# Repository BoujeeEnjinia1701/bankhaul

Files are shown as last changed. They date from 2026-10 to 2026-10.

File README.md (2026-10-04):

# BankHaul

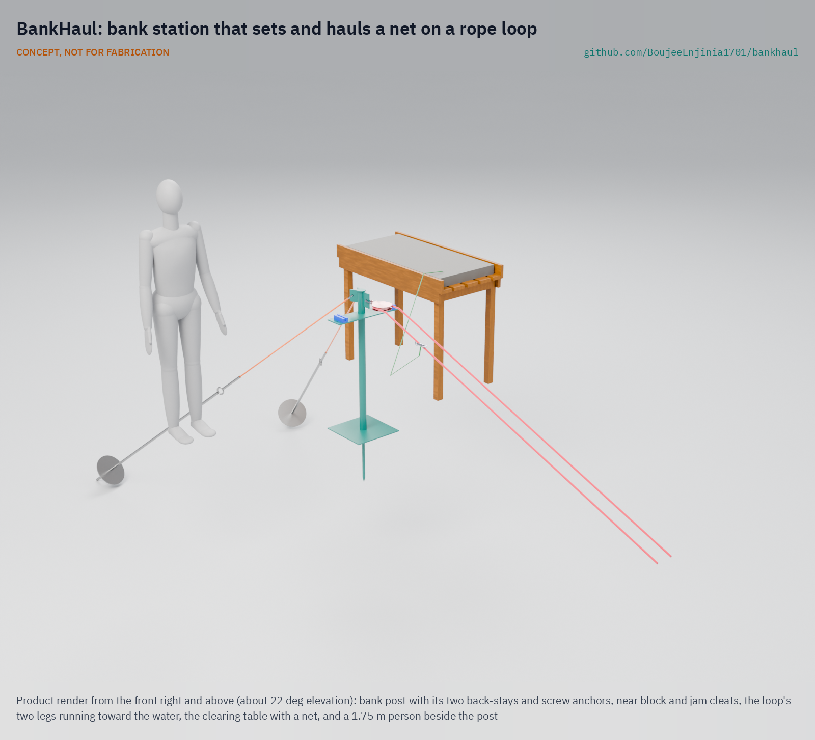
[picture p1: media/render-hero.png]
BankHaul: bank station that sets and hauls a net on a rope loop


     

**Area:** Food and water security · **TRL:** 3 of 9 (proof of concept on paper, design constructable) · **Value-engineering target:** USD 1,800 (estimated prototype cost USD 404) · **Difficulty:** 2 of 5

Sets and hauls nets from the bank on a rope loop so fishers stop wading into crocodile water.

> CONCEPT, NOT FOR FABRICATION. BankHaul is a TRL 3 design on paper: it has not been built or tested.

## Concept rationale

BankHaul is a running rope loop, the same idea as a washing line on two pulleys. One pulley sits on an anchor on the bank; the other sits offshore on a driven stake or on an anchored float. The net, or its end line, is clipped to the loop. Pulling one side of the loop from the bank carries the net out; pulling the other side brings it back to the bank for clearing. Once the stake or float is in place, nobody needs to step into the water to fish.

Everything is commodity hardware: rope, two pulleys, a ground anchor, a stake or a float and some clips. There is no motor and no winch. It is published as an open engineering reference so fisher groups, wildlife authorities and NGOs can build and adapt it to their own banks, nets and bed conditions.

## Burning platform

At Lake Kariba, researchers documented 106 crocodile attacks from 2000 to 2020; in a sample of 60 attacks, 58 % happened while the victim was fishing, and 49 % between midnight and 08:00 ([Matanzima et al., Oryx](https://www.cambridge.org/core/journals/oryx/article/negative-humancrocodile-interactions-in-kariba-zimbabwe-data-to-support-potential-mitigation-strategies/E7F0BCD3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)). In Tanzania, 575 crocodile attacks were recorded from 2010 to 2019 and 58 % were fatal ([Eustace et al., 2022](https://link.springer.com/article/10.1007/s10745-022-00355-z)). In Mozambique, crocodiles caused 66 % of the 265 wildlife-related deaths recorded over 27 months, and victims included people fishing with gill nets ([Dunham et al., Oryx, 2010](https://www.cambridge.org/core/journals/oryx/article/humanwildlife-conflict-in-mozambique-a-national-perspective-with-emphasis-on-wildlife-attacks-on-humans/434EEAAF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)).

The same pattern appears with saltwater crocodiles in Asia: in Timor-Leste, about 80 % of reported attacks happen while fishing or crabbing ([ABC News, 2025](https://www.abc.net.au/news/2025-01-09/crocodile-management-nt-lessons-for-timor-leste/104522096)), and Indonesia recorded 179 attacks with 92 deaths in 2024 ([ICSF, citing CrocAttack](https://icsf.net/newss/indonesias-crocodiles-are-back-and-fishermen-have-scars-to-prove-it/)). The Mozambique study notes that people take the risk because alternative foods or livelihoods are lacking ([Dunham et al., 2010](https://www.cambridge.org/core/journals/oryx/article/humanwildlife-conflict-in-mozambique-a-national-perspective-with-emphasis-on-wildlife-attacks-on-humans/434EEAAF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)). Telling fishers to stay out of the water is not enough; they need a way to keep fishing from the bank.

## Where it could be used

### By industry

| Industry | Use |
| --- | --- |
| Small-scale inland and estuarine fisheries | Setting and hauling gillnets and traps from the bank in crocodile water |
| Wildlife authorities and conservation | A human-wildlife conflict mitigation measure that protects people without removing crocodiles |
| Humanitarian and livelihood programmes | Low-cost kits for fishing households in conflict hotspots |
| Aquaculture and fish ponds | Moving nets, cages or feed lines across ponds without wading |
| Environmental monitoring | Placing and retrieving sampling gear or sensors from the bank |

### By country or region

| Country or region | Why it matters there |
| --- | --- |
| Zimbabwe and Zambia (Lake Kariba) | 58 % of 60 sampled crocodile attacks happened while fishing ([Oryx](https://www.cambridge.org/core/journals/oryx/article/negative-humancrocodile-interactions-in-kariba-zimbabwe-data-to-support-potential-mitigation-strategies/E7F0BCD3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)). |
| Tanzania | 575 crocodile attacks from 2010 to 2019, 58 % fatal ([Human Ecology, 2022](https://link.springer.com/article/10.1007/s10745-022-00355-z)). |
| Mozambique | Crocodiles caused 66 % of wildlife-related deaths, with over half near Lake Cabora Bassa and the Zambezi ([Oryx, 2010](https://www.cambridge.org/core/journals/oryx/article/humanwildlife-conflict-in-mozambique-a-national-perspective-with-emphasis-on-wildlife-attacks-on-humans/434EEAAF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)). |
| Timor-Leste | About 80 % of reported crocodile attacks happen while fishing or crabbing ([ABC News, 2025](https://www.abc.net.au/news/2025-01-09/crocodile-management-nt-lessons-for-timor-leste/104522096)). |
| Indonesia | 179 crocodile attacks and 92 deaths in 2024, more than any other country ([ICSF](https://icsf.net/newss/indonesias-crocodiles-are-back-and-fishermen-have-scars-to-prove-it/)). |

## What sparked the idea

The idea came from the Lake Kariba study by Matanzima, Marowa and Nhiwatiwa, which found that most attacks in its sample happened while people were fishing and recommended area-specific mitigation, patrols and closures of high-risk fishing zones ([Oryx](https://www.cambridge.org/core/journals/oryx/article/negative-humancrocodile-interactions-in-kariba-zimbabwe-data-to-support-potential-mitigation-strategies/E7F0BCD3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)). Closures protect people but also cut off food and income. The question behind BankHaul was simpler: if the net can travel out and back on a rope, does the fisher need to be in the water at all?

## Problem

Small-scale fishers in crocodile waters wade in to set and check their nets, and fishing is the activity during which most attacks happen. They need a way to set and haul nets without entering the water.

Full problem statement: [docs/01-problem.md](docs/01-problem.md)

## Concept

A running rope loop from a bank anchor out to a pulley on a stake or anchored float; fishers set and haul their nets by pulling the loop from the bank and never wade into crocodile water.

A steel post on the bank, held back by two rope stays to screw ground anchors, carries a swivel block at waist height. A steel stake driven into the bed carries a second block on a collar that turns and follows the water level. Two halves of 12 mm floating rope joined by two swivel rings make the loop; the net's far end clips to a ring through a weak link and is pulled out by the loop, then hauled back by hand onto a table at least 5 m from the water. The peak hand pull is about 200 N (BKH-CAL-001).

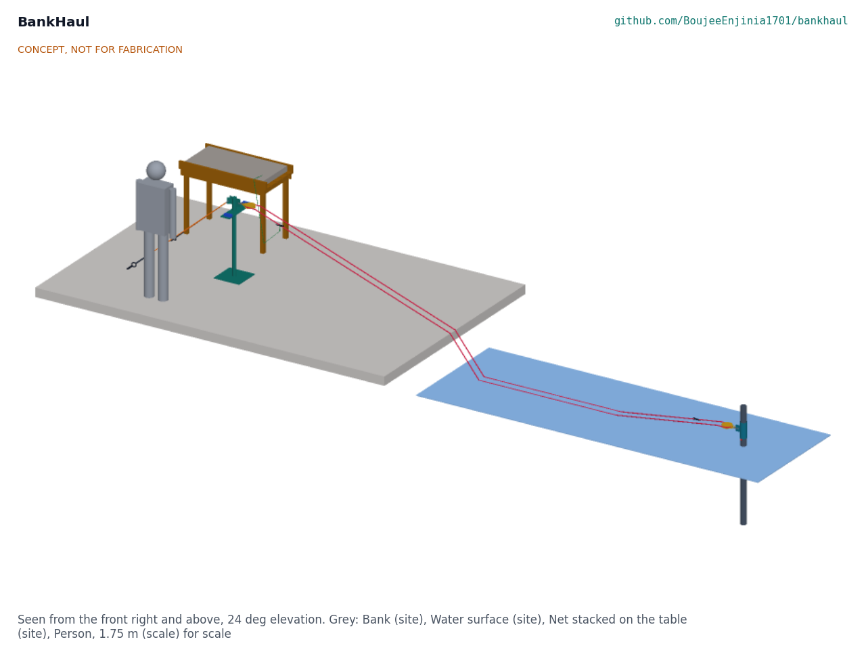
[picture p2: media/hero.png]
BankHaul concept, shortened layout


Full design precis: [docs/02-concept.md](docs/02-concept.md) · Requirements: [docs/03-requirements.md](docs/03-requirements.md) · Calculations: [docs/04-calcs/01-sizing.md](docs/04-calcs/01-sizing.md) · Prototype build plan: [docs/05-build-plan.md](docs/05-build-plan.md) · Design decisions: [docs/06-design-decisions.md](docs/06-design-decisions.md)

## Key components

- Bank post weldment with two back-stays, turnbuckles and screw ground anchors
- Near block and far block (bought swivel blocks)
- Far stake with a swivel collar and stop pin
- Rope loop of two halves joined by two swivel rings
- Net bridles with weak links and snap hooks
- Jam cleats on a cleat bar (the bank brake)
- Clearing table

## Building the prototype

The prototype is one station for a 30 m span, built from seven made and seven bought components. The post, stake and collar are cut, drilled and welded from steel tube and plate; the table is simple carpentry; the stays, loop and bridles are rope work. The bank station is set up on land; the far stake is driven from a boat or at low water, never by wading. The illustrated, step-by-step plan is in [docs/05-build-plan.md](docs/05-build-plan.md) (plan, not yet built).

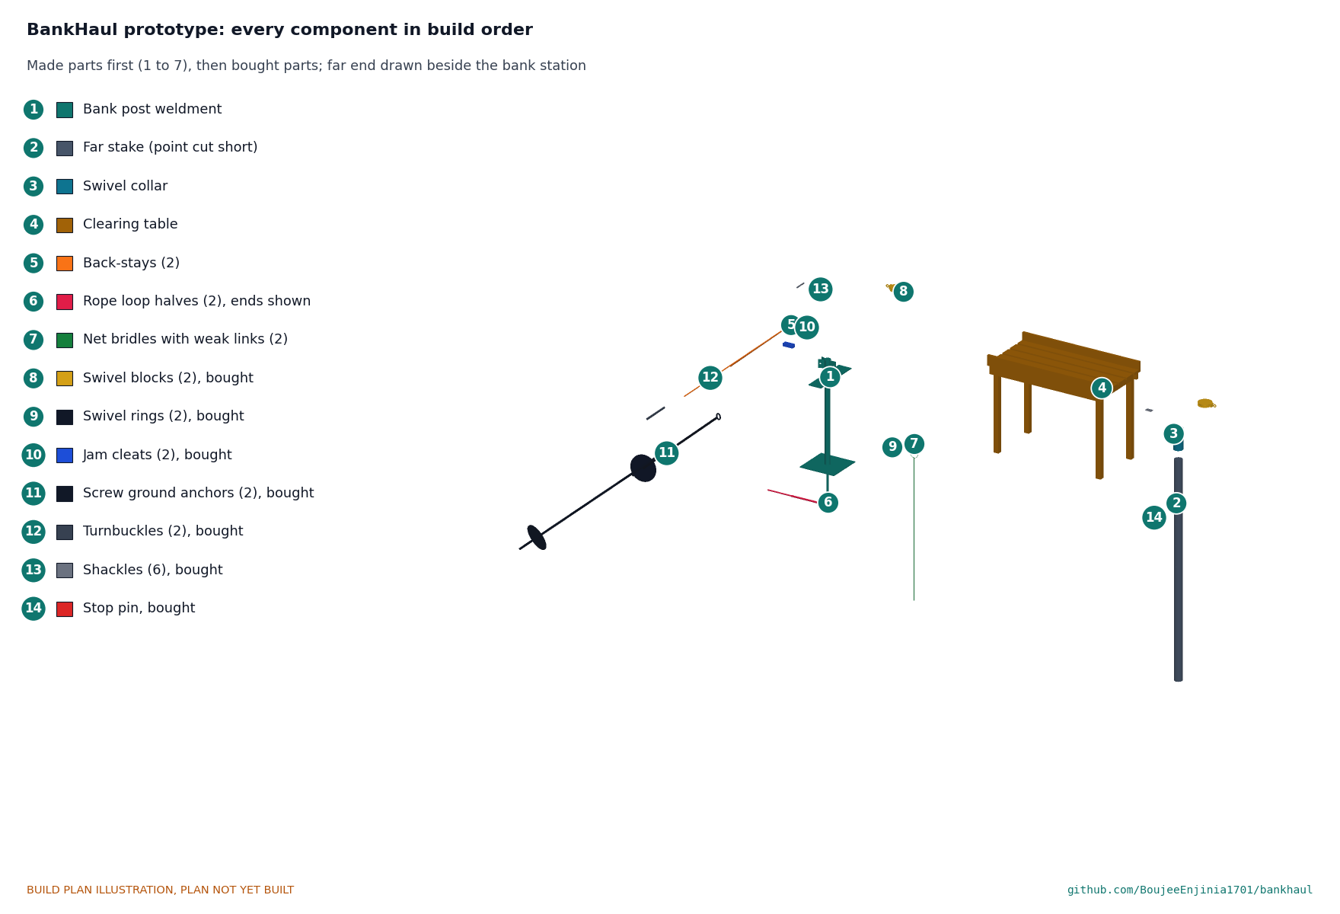
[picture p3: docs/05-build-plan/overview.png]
Every component, pulled apart and numbered in build order


## Safety

> Published as an open engineering reference, not certified equipment.
>
> BankHaul reduces time in the water; it does not protect anyone from a crocodile that leaves the water. Keep away from the water's edge at night where possible and follow local wildlife authority advice.
>
> Installing the offshore stake or float is the most dangerous step; do it from a boat or at low water, never by wading alone.
>
> Rope under load can snap back; never stand in the bight of the loop or in line with a loaded stay, and check anchors, stays, blocks and rope before each season.
>
> Each net end reaches the loop through a weak link that releases at 500 to 700 N; never replace it with stronger cord. Take the loop out of the water before a flood.
>
> Never tie the loop to your body.
>
> This design is published as an open engineering reference. It is not certified equipment.

## Repository layout

| Folder | Contents |
| --- | --- |
| `docs/` | Problem, concept, requirements, calculations and design decisions |
| `cad/src/` | build123d Python source, the source of truth for all geometry |
| `cad/step/`, `cad/stl/` | Exported models for FreeCAD, other CAD tools and printing |
| `cad/drawings/` | 2D sketches and dimensioned drawings |
| `bom/` | Bill of materials |
| `electronics/` | KiCad schematics and PCB layouts |
| `firmware/` | Microcontroller code |
| `media/` | Renders, perspectives and photos |
| `build-log/` | Dated prototyping notes |

## Documentation

Controlled documents follow the portfolio [documentation standard](.kit/STANDARDS.md). Each carries a document ID (BKH-PRC-001 for the precis), a version and a revision history. Branded PDFs are built with `python .kit/render.py` and attached to GitHub Releases when a document is tagged, for example `BKH-PRC-001/v1.0`.

## Credits

Designed by Amish Chadha at Design Molecule Labs. See [CONTRIBUTORS.md](CONTRIBUTORS.md) for roles. To cite this design, use [CITATION.cff](CITATION.cff) (GitHub shows it as "Cite this repository").

AI assistance (Claude) was used to accelerate prototype documentation and first-pass research. Design direction and all decisions are Amish Chadha's, recorded in this repository's decision records (`docs/decisions/`).

## Licenses

- **Hardware** (CAD, drawings, BOM, electronics): [CERN-OHL-S v2](LICENSE)
- **Software** (firmware, scripts, notebooks): [MIT](LICENSE-SOFTWARE)

A project of the [Design Molecule](https://designmolecule.com) lab.

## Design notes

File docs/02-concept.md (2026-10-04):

---
doc_id: BKH-PRC-001
title: BankHaul design precis
project: BankHaul
doc_type: Precis
version: "0.3"
status: Draft
date: '2026-10-03'
author: Amish Chadha
license: CERN-OHL-S-2.0
revisions:
- version: "0.1"
  date: '2026-09-30'
  author: Amish Chadha
  change: Initial scaffold
- version: "0.2"
  date: '2026-10-03'
  author: Amish Chadha
  change: TRL 2 and 3 update; constructable design (BKH-DDR-001, BKH-DDR-002), first-order numbers, safety
- version: "0.3"
  date: '2026-10-03'
  author: Amish Chadha
  change: Far stake driven 3.5 m and R8 restated (Amish's decisions 14A and 15A, BKH-DDR-003); numbers updated
---

# BankHaul design precis

Sets and hauls nets from the bank on a rope loop so fishers stop wading into crocodile water.

BankHaul concept, shortened layout

*Figure 1. Bank station, rope loop and far stake in the shortened picture layout (7 m between the blocks; 30 m in the design case).*

## How it works

A rope loop runs from a post on the bank out to a stake in the water and back. Once the stake is set, the fisher never needs to enter the water: the net is clipped to the loop on the bank, pulled out by the loop, and later hauled back onto a table on the bank.

- **Bank station.** A 48.3 mm steel post stands on a 350 mm foot plate with a ground spike, at least 6 m back from the water. Two rope back-stays with turnbuckles hold it back to two screw ground anchors with 250 mm helixes. A swivel block hangs from a pad eye at 950 mm, about waist height. A cleat bar carries two jam cleats, one for each leg of the loop, and a hole to tie off the net's near end.
- **Far end.** A 76.1 mm steel stake, 5.0 m long, is driven 3.5 m into the bed from a boat or at low water. A collar turns on the stake, resting on a through-bolt stop pin that can be moved up or down a hole as the season's water level changes; a second swivel block hangs from the collar, so it lines up with the loop by itself.
- **Loop.** Two halves of 12 mm floating rope are joined by two eye-to-eye swivels. The swivels are the clip rings: when ring 1 is at the bank, ring 2 is at the far block, and each ring stops at a block if pulled too far.
- **Setting.** The fisher clips the far end of the net to ring 1 through a weak link and pulls the other leg of the loop hand over hand; ring 1 carries the net's far end out while the net pays out from the table. When ring 1 reaches the far block, the net lies along the loop. The near end is tied to the cleat bar through a second weak link, and each leg is dropped into its jam cleat.
- **Hauling.** The fisher frees the legs, unties the near end and pulls the net in onto the table hand over hand; the loop follows, bringing ring 1 and the far end in last. The table is at least 5 m from the water.

## Components

| # | Component | Role | Made or bought |
| --- | --- | --- | --- |
| 1 | Bank post weldment | Carries the near block, the jam cleats and the stays | Made: welded steel tube and plate |
| 2 | Far stake | Carries the far end in the bed | Made: steel tube with a welded point and cap |
| 3 | Swivel collar | Turns on the stake so the far block lines up with the loop | Made: steel tube and lug |
| 4 | Clearing table | Raised surface to stack and clear the net above the waterline | Made: timber |
| 5 | Back-stays (2) | Hold the post back against the loop | Made: spliced polyester rope |
| 6 | Rope loop | Carries the net out and back | Made: two spliced halves of floating rope |
| 7 | Net bridles with weak links (2) | Join each net end to the loop or the post; release at 500 to 700 N | Made: cord, weak link and snap hook |
| 8 | Swivel blocks (2) | Turn the loop at each end | Bought: 100 mm sheave for 12 mm rope |
| 9 | Swivel rings (2) | Join the loop halves; clip rings and end stops | Bought |
| 10 | Jam cleats (2) | Hold each leg; the bank brake | Bought |
| 11 | Screw ground anchors (2) | Anchor the stays in soft soil | Bought: 250 mm helix, 1.6 m rod |
| 12 | Turnbuckles (2) | Tension the stays | Bought: rated M12 |
| 13 | Shackles (6) | Join blocks, stays and anchors | Bought: rated 10 mm |
| 14 | Stop pin | Holds the collar at the season's level | Bought: M12 bolt |

## Key design choices

Each choice is recorded in BKH-DDR-001 (TRL 2 review) or BKH-DDR-002 (design for construction) and listed in `docs/06-design-decisions.md`.

- **A stayed post, not a cantilever.** A post holding 3 kN at waist height as a cantilever would need a deep foundation; stays to screw anchors take the pull as tension and leave the post in compression, and two people can move it.
- **Rings that never pass a block.** The loop's joins are the clip rings, placed half a loop apart, so with a net shorter than the span less 2 m no ring or knot ever runs round a sheave.
- **Weak links.** Every net end reaches the loop or post through a link that releases at 500 to 700 N, about eight times the largest load in normal use, so a crocodile or snag taking the net cannot load the far stake past 1.4 kN or pull a person.
- **Floating loop.** Polysteel floats, so the loop stays visible, clear of the bed and easy to reach from a boat.
- **Hand pull only.** No winch or capstan (IP screen design-around); the peak pull of about 200 N does not need one.

## First-order numbers

All figures from BKH-CAL-001; assumptions are stated there.

| Quantity | Value | Basis |
| --- | --- | --- |
| Loop length, 30 m span | 60.4 m | Two legs plus half a wrap round each 112 mm rope circle |
| Peak hand pull to haul a 30 m net with 10 kg catch | about 200 N | Catch, weed and a fifth of the wet net up a 27 degree bank edge |
| Pull to set the net | about 43 N | Loop and net paying out at 0.5 m/s |
| Weak link release | 500 to 700 N | Nominal 600 N, plus or minus 15 % |
| Far end design load | 1.4 kN | Both legs at the link's highest release |
| Stay tension at the 3 kN bank load | 2.1 kN each | Stays 39 degrees up, 22 degrees either side |
| Screw anchor capacity | 4.4 kN each | 250 mm helix, 0.9 m deep, soil of 10 kPa shear strength |
| Far stake capacity | 6.1 kN in soft mud; 3.0 kN in very soft mud (factor 2.03 on R5) | Broms, short free-head pile, 3.5 m embedded |
| Cycle time | about 6 minutes | Without clearing fish |
| Station mass | about 106 kg; heaviest part 33.2 kg (far stake) | Model volumes and catalogue figures |
| Station parts | USD 394 (steel trial station; R8 now applies to a local-materials station costed with the co-design partner) | `bom/bom.csv` |

Value-engineering target: USD 1,800. Estimated cost of the constructable design: USD 404 including the stake driving cap (USD 1,396 under the target).

## Patent design-arounds

From the preliminary patent, trademark and prior-art screen (not legal advice):

- No powered hauler: hand-pulled loop only, which keeps clear of motorised line-hauler patents such as EP1429601 (expired) and later filings.
- Commodity blocks, anchors and rope, following the traditional running-line practice, rather than any proprietary downrigger or hauler pulley.

## Shared blocks

- CalRig proof-load: the first candidate rig for the anchor, stake and weak link tests at TRL 4.
- Hand capstan block from SaltDrag and SiltHaul: not used; the peak pull is within one person's reach, and the design-around excludes powered hauling.

## Safety

> **Safety:** BankHaul reduces time in the water; it does not protect anyone from a crocodile that leaves the water. Keep away from the water's edge, especially at night and at dawn, and follow the local wildlife authority's advice.
>
> Placing the far stake is the most dangerous step: do it from a boat or at low water with a second person watching, never by wading.
>
> A loaded rope can snap back. Never stand in the bight of the loop or in line with a loaded stay; check anchors, stays, blocks and rope before each season and after any hard pull.
>
> Never tie the loop or the net to your body, and never wrap the rope round a hand. If something big takes the net, let go: the weak link and the jam cleats hold the rest.
>
> Take the loop out of the water before a flood; floating debris can load it far beyond its design.
>
> This design is published as an open engineering reference. It is not certified equipment.

## Open questions

Open decisions and items to confirm when parts are bought are kept in the design decisions register (`docs/06-design-decisions.md`).

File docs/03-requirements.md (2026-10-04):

---
doc_id: BKH-REQ-001
title: BankHaul requirements
project: BankHaul
doc_type: Requirements
version: "0.3"
status: Draft
date: '2026-10-03'
author: Amish Chadha
license: CERN-OHL-S-2.0
revisions:
- version: "0.1"
  date: '2026-09-30'
  author: Amish Chadha
  change: Initial scaffold
- version: "0.2"
  date: '2026-10-03'
  author: Amish Chadha
  change: TRL 3; targets made measurable, R10 (weak link) and R11 (working distance) added, status from BKH-CAL-001
- version: "0.3"
  date: '2026-10-03'
  author: Amish Chadha
  change: Amish's decisions 14A (far stake driven 3.5 m; R5 status) and 15A (R8 restated), BKH-DDR-003
---

# BankHaul requirements

Measurable requirements for the first prototype station. Each status comes from the calculation note BKH-CAL-001 (`docs/04-calcs/01-sizing.md`); "on paper" means calculated, not yet tested. R10 and R11 were added at the TRL 2 review (BKH-DDR-001, items 3 and 4). R8 was restated, and R5's status changed, by Amish's decisions of 2026-10-03 (BKH-DDR-003). Amish, 2026-10-03: "i agree with all the 46 recommendations you provided. please proceed."

Table 1. Requirements

| ID | Requirement | Target | Verification (TRL 4 or later) | Status at TRL 3 |
| --- | --- | --- | --- | --- |
| R1 | Set and haul a gillnet with nobody entering the water | 10 of 10 set and haul cycles completed from the bank | Field trial with partner fishers | Met on paper: once the far stake is set from a boat, no step needs anyone in the water |
| R2 | Working span | At least 30 m (98 ft) between pulleys; stretch goal 50 m (164 ft) | Measured at the trial site | Met on paper: 30 m design case; rope bought for 50 m |
| R3 | Hand pull force | Peak pull under 250 N (56 lbf) to haul a 30 m net with catch | Spring scale or load cell during trials | Met on paper: about 200 N (estimate) |
| R4 | Bank anchor holding | Holds at least 3 kN (675 lbf) in soft wet soil without visible movement | Pull-out test on a CalRig-style rig | Met on paper: screw anchors at factor 2.1 on capacity in soil of 10 kPa shear strength |
| R5 | Offshore stake or float holding | Holds at least 1.5 kN (337 lbf) horizontal load in soft mud | Pull-out tests in a representative bed | Met on paper in soft mud (factor 4.05) and very soft mud (factor 2.03), with the stake driven 3.5 m (decision 14A) |
| R6 | Cycle time | Full haul and reset under 10 minutes for a 30 m net | Timed trials | Met on paper: about 6 minutes (estimate, without clearing fish) |
| R7 | Durability | One fishing season (6 months) of daily use without rope or pulley failure | Season-long pilot with inspection log | Met on paper (estimate): rope factor 5.7 after sun damage |
| R8 | Cost (restated, decision 15A) | Parts under USD 80 per station for a local-materials station, costed from local prices with the co-design partner before the season pilot. The steel station built for the TRL 4 trials is costed and recorded but not held to this figure | Bill of materials for the local-materials station, priced with the co-design partner | Steel trial station: USD 394, accepted for TRL 4. Local-materials station: about USD 98 (first-order estimate), so not yet met; settled by the partner's costing |
| R9 | Level change | Bank anchor relocatable by two people in under 30 minutes as the shoreline moves | Timed relocation | Met on paper: about 22 minutes (estimate) |
| R10 | Weak link | The net's bridle releases between 500 and 700 N, so a net seized by an animal or snag cannot load the loop, stake or fisher beyond that | Pull three samples of each cord batch to release | Met on paper; cord chosen by test when parts are bought |
| R11 | Working distance | The fisher's working spot is at least 5 m (16 ft) from the water's edge at the day's level | Measured at the trial site | Met by layout: 5.0 m |

## Restated by Amish's decisions

- **R8 (decision 15A, 2026-10-03).** Amish: "i agree with all the 46 recommendations you provided. please proceed." The steel station is built for the TRL 4 trials, so they test the method with parts of known strength, and a local-materials station is costed with the co-design partner. R8 was "Parts under USD 80 per station"; it now applies the USD 80 figure to the local-materials station costed from local prices, and records the steel trial station's cost without holding it to that figure.
- **R5 (decision 14A, 2026-10-03).** The target is unchanged; the far stake is driven 3.5 m, so it is met on paper in very soft mud as well as soft mud.

## Assumptions

- Fishers can shift from wading-set nets to loop-set nets without losing much catch.
- Most attack hotspots have banks where a screw anchor can hold (soft wet soil of about 10 kPa undrained shear strength or firmer).
- A boat or low-water window exists to place the far stake once per season.
- Nets can be fitted with a bridle at each end to clip to the loop and the bank post.
- Design case: a 30 m by 2 m gillnet, 10 kg of catch and 5 kg of weed; water 1.0 m deep at the far stake.

> **Safety:** R10 and R11 are safety requirements. They limit what a seized net can do to the fisher and keep the fisher back from the water. Neither makes it safe to stand at the water's edge.

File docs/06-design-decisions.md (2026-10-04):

---
doc_id: BKH-DEC-001
title: BankHaul design decisions register
project: BankHaul
doc_type: Design decisions register
version: "0.2"
status: Draft
date: '2026-10-03'
author: Amish Chadha
license: CERN-OHL-S-2.0
revisions:
- version: "0.1"
  date: '2026-10-03'
  author: Amish Chadha
  change: Register opened; design decisions made under Amish's pre-approvals of 2026-10-03; two requirement decisions proposed
- version: "0.2"
  date: '2026-10-03'
  author: Amish Chadha
  change: Amish decided both open items (14A far stake 3.5 m, 15A R8 restated); moved to Decisions made (BKH-DDR-003)
---

# BankHaul design decisions register

Every design decision still to be made, and every decision made, in one place. Each decision is argued in full in its decision record under `docs/decisions/` or in `docs/REVIEW.md`; this register is the index Amish works from. The build plan (`docs/05-build-plan.md`) describes the design as it stands and does not list decisions.

> **Safety:** Several decisions below set BankHaul's safety case (weak links, working distance, stayed post, far stake, floods). Each took the conservative option; the evidence that would relax it is in BKH-DDR-001, Table 1.

## Open decisions

None. Amish decided both requirement items on 2026-10-03 (decisions 14A and 15A, BKH-DDR-003); see Decisions made below.

## To confirm when parts are bought

| # | What to confirm | Why it matters | Source |
| --- | --- | --- | --- |
| 1 | The weak link cord: three samples from the batch each release between 500 and 700 N as a single 80 mm loop | Sets the largest load a seized net can put into the system (R10) | BKH-CAL-001, C |
| 2 | The screw anchors' helix diameter, rod length and eye, and the supplier's holding figure in soft clay | The bank check uses a 250 mm helix 0.9 m deep (R4) | BKH-CAL-001, D |
| 3 | The blocks' eye and cheek-spacer positions sit outside the rope's path round the sheave, and the sheave takes 12 mm rope | The loop must not rub the block; the post and collar holes are set for this block length | BKH-DDR-002, item 9 |
| 4 | The jam cleats' fixing hole spacing | The cleat bar is drilled for 60 mm | BKH-DWG-101 |
| 5 | The rope's breaking strength, floating and UV stabilisation | Factor 5.7 after a season assumes 20 kN new and half lost to sun | BKH-CAL-001, F |
| 6 | The turnbuckles and shackles are rated and marked with their working load limits | They carry the stays at up to 2.1 kN | BKH-CAL-001, D |
| 7 | The bed's shear strength at the trial site (a hand vane or cone test from the boat) | The 3.5 m stake holds at factor 2.03 down to about 5 kPa; a softer bed needs a new check | BKH-CAL-001, E |
| 8 | Local prices for the local-materials station, with the co-design partner | Sets the restated R8 figure (estimate about USD 98 against USD 80) | BKH-CAL-001, I; BKH-DDR-003 |

## Value engineering

Value-engineering target: USD 1,800 (a hypothetical control target, not a limit). Estimated cost of the constructable design: USD 404 including the stake driving cap (USD 1,396 under the target). Main cost drivers and savings worth trying:

- The two screw anchors (USD 76) are the largest line, then the far stake (USD 60), the rope (USD 54), the two blocks (USD 44), the table (USD 35) and the post (USD 32).
- Rated rigging (shackles, turnbuckles, blocks) is kept because it carries the safety case.
- Savings worth trying: rope bought only for the site's span (USD 29 for 30 m); a local timber table; anchors bought in bulk through a fencing or utility supplier; a hardwood far pole where the bed is firm.

## Decisions made

The pre-approvals: Amish, 2026-10-03: "start with the first 14 repos from the list of 29 projects. I pre-approve the batch runs along with any recommendations you come up with. I also accept any cost overruns or variations from the assumed scope cost." and, for this batch, "Proceed with the remaining 15 scaffolds".

| Date | Decision | Decided by | Record |
| --- | --- | --- | --- |
| 2026-10-03 | Bank anchor: post on a foot plate, held back by two stays to two screw anchors | Amish, under both pre-approvals quoted above | BKH-DDR-001, item 1 |
| 2026-10-03 | Driven stake for the first prototype; float kept as a variant for deep beds | Amish, under both pre-approvals quoted above | BKH-DDR-001, item 2 |
| 2026-10-03 | Weak link at each net end, 500 to 700 N; requirement R10 added | Amish, under both pre-approvals quoted above | BKH-DDR-001, item 3 |
| 2026-10-03 | Fisher works at least 5 m from the water; post 6 m back; requirement R11 added | Amish, under both pre-approvals quoted above | BKH-DDR-001, item 4 |
| 2026-10-03 | 12 mm floating polysteel loop | Amish, under both pre-approvals quoted above | BKH-DDR-001, item 5 |
| 2026-10-03 | Two swivel rings half a loop apart as clip rings and end stops; net at least 2 m shorter than the span | Amish, under both pre-approvals quoted above | BKH-DDR-001, item 6 |
| 2026-10-03 | A jam cleat for each leg as the bank brake | Amish, under both pre-approvals quoted above | BKH-DDR-001, item 7 |
| 2026-10-03 | Haul by the net's near end with the loop following | Amish, under both pre-approvals quoted above | BKH-DDR-001, item 8 |
| 2026-10-03 | Loop taken out before floods | Amish, under both pre-approvals quoted above | BKH-DDR-001, item 9 |
| 2026-10-03 | First co-design candidate to approach: the Lake Kariba research group of the Oryx study with an inshore fishing cooperative (not agreed) | Amish, under both pre-approvals quoted above | BKH-DDR-001, item 10 |
| 2026-10-03 | CalRig as the first candidate proof-load rig; no hand capstan | Amish, under both pre-approvals quoted above | BKH-DDR-001, item 11 |
| 2026-10-03 | `budget_usd` kept at 1,800 as a value-engineering target | Amish: "I also accept any cost overruns or variations from the assumed scope cost." | BKH-DDR-001, item 12 |
| 2026-10-03 | Design for construction: the twelve changes of BKH-DDR-002 | Amish, under both pre-approvals quoted above | BKH-DDR-002 |
| 2026-10-03 | Appearance model additions for renders: loop cut short, stake above the bed only, net on the table, mannequin beside the post | Amish, under both pre-approvals quoted above | `docs/REVIEW.md`, TRL 3 |
| 2026-10-03 | 14A, R5: far stake 5.0 m long, driven 3.5 m (factor 2.03 in very soft mud; USD 12 and 6.4 kg more) | Amish, 2026-10-03: "i agree with all the 46 recommendations you provided. please proceed." | BKH-DDR-003 |
| 2026-10-03 | 15A, R8: build the steel station for the TRL 4 trials and cost a local-materials station with the co-design partner; R8 restated to apply USD 80 to the local-materials station | Amish, 2026-10-03: "i agree with all the 46 recommendations you provided. please proceed." | BKH-DDR-003 |

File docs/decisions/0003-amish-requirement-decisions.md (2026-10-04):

---
doc_id: BKH-DDR-003
title: BankHaul requirement decisions of 2026-10-03
project: BankHaul
doc_type: Design decision record
version: "0.1"
status: Draft
date: '2026-10-03'
author: Amish Chadha
license: CERN-OHL-S-2.0
revisions:
- version: "0.1"
  date: '2026-10-03'
  author: Amish Chadha
  change: Amish's decisions 14A (R5, far stake driven 3.5 m) and 15A (R8, steel trial station and local-materials costing) recorded and carried out
---

# 0003: Requirement decisions of 2026-10-03 (far stake depth and cost per station)

- **Date:** 2026-10-03
- **Status:** accepted
- **Decided by:** Amish Chadha, 2026-10-03: "i agree with all the 46 recommendations you provided. please proceed." For BankHaul these are decisions 14A and 15A, each the recommended option.

## Context

The TRL 3 review left two requirements open (`docs/REVIEW.md`, TRL 3, "Decisions for Amish"):

1. **R5, far stake holding in very soft mud.** The 76.1 mm stake driven 2.5 m held an ultimate 1,845 N in a bed of about 5 kPa shear strength, a factor of 1.23 on the 1.5 kN of R5 against the factor of 2 taken as "holds".
2. **R8, cost per station.** The constructable station cost USD 382 in parts against "parts under USD 80 per station".

## Options considered

| Item | Options | Recommended |
| --- | --- | --- |
| 14 (R5) | A: drive the stake 3.5 m (5.0 m stake); B: two stakes 1 m apart, tied at the top; C: keep 2.5 m and use only sites with a firmer bed | A |
| 15 (R8) | A: build the steel station for the TRL 4 trials and cost a local-materials station with the co-design partner; B: switch the prototype to local materials now (about USD 98); C: one bank post and table for three loops | A |

## Decision

- **14A.** The far stake is a 76.1 x 3.6 mm S355 tube 5.0 m long overall (tube 4,850 mm plus the 150 mm point), driven 3.5 m into the bed. The paint ring that marks the driven depth moves to 3,500 mm above the point; the stop pin holes stay where they were relative to the cap.
- **15A.** The steel station is built for the TRL 4 trials. A local-materials station is costed from local prices with the co-design partner before the season pilot. R8 is restated: "Parts under USD 80 per station for a local-materials station, costed from local prices with the co-design partner before the season pilot. The steel station built for the TRL 4 trials is costed and recorded but not held to this figure."

## Consequences

| Item | Requirement | New result | Against the target |
| --- | --- | --- | --- |
| 14A | R5 | Factor 2.03 in very soft mud (3,040 N ultimate); 4.05 in soft mud (6,079 N); bending 162 MPa at 1.5 kN, unchanged | Met on paper in both beds; the TRL 4 pull test settles it |
| 15A | R8 (restated) | Steel trial station USD 394; local-materials station about USD 98 (first-order estimate) | Trial station accepted; the local-materials figure is not yet met on the estimate and is settled by the partner's costing |

- **Mass.** The stake is 33.2 kg, 6.4 kg more; it remains the heaviest part and is lifted by two people from the boat. The station is about 106 kg.
- **Cost.** The stake line rises from USD 48 to USD 60 (the same tube price per metre, about USD 12 a metre, for 1.0 m more). Value-engineering target: USD 1,800. Estimated cost of the constructable design: USD 404 (USD 1,396 under the target). Station parts USD 394.
- **Build.** The stake is cut 4,850 mm long and driven to a paint ring 3,500 mm above the point. In soft mud it sinks part of the way under its own weight and is pushed and twisted down before driving. Drawings BKH-DWG-002 and BKH-DWG-003 are at Rev P3 (BKH-DWG-001 bumped with them, no change to its content); making sketch BKH-DWG-102 is at Rev P2; build plan steps 6 to 8 are redrawn.
- **Safety.** A 5.0 m stake is longer to stand up from a boat. The build plan's safety stop now says two people lift it upright and nobody drives it from a standing position higher than the boat's seat.

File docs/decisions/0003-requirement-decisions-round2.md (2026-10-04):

---
doc_id: BKH-DDR-003
title: BankHaul requirement decisions, round 2
project: BankHaul
doc_type: Design decision record
version: "0.1"
status: Draft
date: '2026-10-03'
author: Amish Chadha
license: CERN-OHL-S-2.0
revisions:
- version: "0.1"
  date: '2026-10-03'
  author: Amish Chadha
  change: R5 (far stake in very soft mud) and R8 (cost per station) decided by Amish on 2026-10-03, both as recommended
---

# 0003: Requirement decisions, round 2

- **Date:** 2026-10-03
- **Status:** decided. Decided by Amish Chadha, 2026-10-03: "i approve all of the 47 recommendations provided by you. Execute them." Both decisions below were the recommended options in `docs/REVIEW.md` (TRL 3, Decisions for Amish) and in the design decisions register, taken exactly as worded there.

## Context

At TRL 3 (BKH-CAL-001 v0.1) two requirements were not met or at risk on paper. R5 (far stake holding) was met in soft mud but at risk in very soft mud: in a bed of about 5 kPa the 76.1 mm stake driven 2.5 m holds an ultimate 1,845 N, a factor of 1.23 on the 1.5 kN load, against the factor of 2 used as "holds", because lateral capacity in clay falls with its strength and the load acts 1.2 m above the bed. R8 (parts under USD 80 per station) was not met: the constructable station costs USD 382, driven by bought rated hardware and the steel stake and post.

> **Safety:** Neither decision relaxes a safety provision. The long stake is heavier (33.2 kg) and is handled by two people from a boat held on two anchors, with a lookout, as before; the hand vane reading of the bed is taken under the same rules. The steel trial station keeps the rated rigging that carries the safety case.

## Options considered

*Table 1. Options for each decision.*

| Requirement | A | B | C |
| --- | --- | --- | --- |
| R5, far stake holding in very soft mud | Drive 3.5 m into very soft beds (5.0 m stake): factor 2.03, met, about USD 12 more per stake and 6.4 kg more (33 kg stake) | Two stakes 1 m apart tied at the top with a bar carrying the collar: factor 2.21, met, about USD 56 more and about 28 kg more, two to drive from the boat | Keep 2.5 m and site stations only where a hand vane shows 10 kPa or more: factor 2.46 where used, very soft beds excluded, no cost or mass |
| R8, cost per station | Build this steel station for the TRL 4 trials and cost a local-materials station with the co-design partner before the season pilot: R8 not met for the trial station, USD 382 now, about 100 kg | Switch the prototype now to local materials: about USD 98, not met but close, about 30 kg more, R7 and R9 at risk | One bank post and table serve three loops at a landing site: about USD 257 per loop, not met, about 60 kg per loop |

## Decision

*Table 2. Decisions taken.*

| # | Requirement | Option chosen | Effect | Condition |
| --- | --- | --- | --- | --- |
| 5 | R5, far stake holding in very soft mud | A: drive 3.5 m into very soft beds with a 5.0 m stake | Factor 2.03 at 5 kPa (ultimate 3,040 N), 2.46 at 10 kPa with the standard 2.5 m: R5 met on paper. Long stake 33.2 kg (26.8 kg standard), about USD 12 more; station USD 394 at a very soft site. Bending stress unchanged (162 MPa, factor 2.2 on S355) | The extra 1 m is cut only where a hand vane test of the bed, from the boat down to 2.5 m, reads under 10 kPa. It gives a factor of 2 only down to 4.9 kPa; weaker beds are a new open question |
| 6 | R8, cost per station | A: build the steel station for the TRL 4 trials; cost a local-materials station with the co-design partner before the season pilot | R8 not met for the trial station (USD 382, or USD 394 with the long stake; about 100 kg). No change to the design or the bill of materials | The local-materials costing, from local prices with the co-design partner, is made before the season pilot and gives the real R8 figure |

## Consequences

- `cad/src/model.py`: `embed_vsoft` (3,500 mm) and `su_vane_min` (10 kPa) added, with the derived length of the long stake (5,000 mm). The model and the STEP files still show the 2.5 m design case, so they were not re-exported.
- `cad/src/sheets.py`: far end general arrangement BKH-DWG-002 to Rev P3 with the long stake note; `cad/src/build_plan_media.py`: making sketch BKH-DWG-102 with the long stake's cut length and paint ring.
- `docs/04-calcs/sizing.py` and `results.csv` (BKH-CAL-001 v0.2): R5 met on paper; the weakest bed covered (4.9 kPa); station cost and heaviest lift for the long stake; R8 restated as not met for the trial station.
- `bom/bom.csv`: line 2 note gives the long stake's cut length, mass and extra cost; the costed station stays the standard one (USD 382).
- Build plan BKH-BLD-001 v0.2: hand vane reading of the bed before the stake is cut, the long stake's cut length and paint ring, and the vane reading added to the safety stop before driving.
- `docs/03-requirements.md` v0.3: R5 and R8 status updated; no target restated.

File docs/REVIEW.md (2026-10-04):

# Review note: BankHaul

## 2026-10-03: Amish's requirement decisions carried out

Amish, 2026-10-03: "i agree with all the 46 recommendations you provided. please proceed." For BankHaul that decides items 14 and 15 as recommended (14A and 15A). Recorded in `docs/decisions/0003-amish-requirement-decisions.md` (BKH-DDR-003) and `docs/06-design-decisions.md` (BKH-DEC-001 v0.2); open decisions are now none.

**Changes made.**

- **14A, R5: far stake driven 3.5 m.** `cad/src/model.py` embedment 2,500 to 3,500 mm, so the stake is 5.0 m long overall (tube 4,850 mm); constructability checks pass (no overlaps, nothing floating); STEP and STL regenerated. `bom/bom.csv` line 2: USD 48 to USD 60 (same tube price per metre, about USD 12 a metre, for 1.0 m more), 33.2 kg. Build plan (BKH-BLD-001 v0.2) section 3.2 and step 6: cut 4,850 mm, paint ring 3,500 mm above the point, two people lift the stake upright, push and twist it down before driving; safety stop updated.
- **15A, R8 restated.** `docs/03-requirements.md` (BKH-REQ-001 v0.3) quotes Amish: R8 now applies "parts under USD 80 per station" to a local-materials station costed from local prices with the co-design partner before the season pilot; the steel station built for the TRL 4 trials is costed and recorded but not held to that figure. No design change.
- Calculation note BKH-CAL-001 v0.2 and `docs/04-calcs/sizing.py` re-run; `results.csv` updated. Precis BKH-PRC-001 v0.3 and README cost updated.

**New results.**

| Requirement | Target | New result | Status |
| --- | --- | --- | --- |
| R5 | Holds 1.5 kN horizontal in soft mud (factor 2 taken as "holds") | Factor 2.03 in very soft mud (5 kPa, was 1.23); 4.05 in soft mud (10 kPa, was 2.46); bending 162 MPa at 1.5 kN, unchanged | Met on paper in both beds; TRL 4 pull test |
| R8 (restated) | Local-materials station parts under USD 80, costed with the partner; steel trial station recorded | Steel trial station USD 394; local-materials station about USD 98 (first-order estimate) | Trial station accepted; local-materials figure not yet met on the estimate, settled by the partner's costing |

**Cost and mass.** Value-engineering target: USD 1,800. Estimated cost of the constructable design: USD 404 (USD 1,396 under the target); station parts USD 394. Far stake 33.2 kg (6.4 kg more), still the heaviest part; station about 106 kg.

**Pictures changed.** BKH-DWG-002 and BKH-DWG-003 at Rev P3 (BKH-DWG-001 bumped with the shared revision list, content unchanged); making sketch BKH-DWG-102 Rev P2; build plan steps 6, 7 and 8 redrawn; concept blueprint key figures (BKH-DWG-010) and concept media regenerated. The overview and joint pictures show the stake cut short and do not change. Appearance model: the detail view adds a red paint ring at the bed marking 3.5 m driven, since the deeper stake itself is below the bed and out of sight (appearance addition under Amish's decision of 2026-10-03). Scene files re-exported to `/home/claude/renders/bankhaul`; photoreal renders are re-made on Amish's Mac.

**Safety.** Standing a 5.0 m, 33 kg stake upright from a boat is harder than a 4.0 m one; the build plan now has two people lift it and nobody drive it standing higher than the boat's seat. All other safety notes stand.

**Cross-repo actions.** None.

**Open decisions.** None. Nothing new needs Amish.

**Recommended next step.** The design is ready for TRL 4 when the phase allows: build the steel station, run the R4, R5 and R10 proof loads (CalRig or in place), and cost the local-materials station with the co-design partner for R8.

## Session 2026-10-03: TRL 3 (kit 1.7.0, /to-trl3 under Amish's pre-approvals)

Amish, 2026-10-03: "start with the first 14 repos from the list of 29 projects. I pre-approve the batch runs along with any recommendations you come up with. I also accept any cost overruns or variations from the assumed scope cost." and, for this second batch, "Proceed with the remaining 15 scaffolds". Every design recommendation in this session is therefore recorded as decided, dated 2026-10-03, in `docs/06-design-decisions.md`. Requirements not met or at risk are not decided; they are posed below under "Decisions for Amish" (Amish, 2026-10-03: "A simple statement doesn't add value - ensure you are identifying a state and posing it as a clear recommendation for me to decide on."). Kit 1.7.0 was installed from the kit source; `.kit/PHASE.yaml` kept as installed.

### TRL 2

**What was done.**

- `docs/01-problem.md` (BKH-PRB-001 v0.2): first co-design candidate with a checklist, safety section.
- `docs/03-requirements.md` (BKH-REQ-001 v0.2): measurable targets with status; R10 (weak link) and R11 (working distance) added.
- `docs/02-concept.md` (BKH-PRC-001 v0.2): how it works, components, key design choices, first-order numbers, safety.
- `docs/decisions/0001-trl2-review-decisions.md` (BKH-DDR-001): twelve TRL 2 review items decided.

**Results.** A hand-pulled loop on two blocks can set and haul a 30 m gillnet from the bank; the hauling pull is set by dragging the catch up the bank edge, not by the loop. The open structural questions were the bank anchor (a 3 kN pull at waist height in soft soil) and the far stake in soft mud.

**Requirements not met.** None decided at TRL 2; R8 (cost) was already doubtful with bought blocks and anchors.

**Decisions made under the pre-approvals.** BKH-DDR-001, items 1 to 12: stayed post on screw anchors; driven stake for the prototype (float kept as a variant); weak links and R10; 5 m working distance and R11; 12 mm floating polysteel; swivel rings as clip rings and stops; jam cleats; haul by the near end; loop out before floods; Lake Kariba researchers with an inshore cooperative as first co-design candidate (not agreed); CalRig as first proof-load rig and no capstan; budget kept.

**Safety concerns.** Placing the far stake; rope snap-back; a net seized by a crocodile pulling the fisher; standing at the water's edge at night.

### TRL 3

**What was done.**

- `docs/04-calcs/01-sizing.md`, `docs/04-calcs/sizing.py` and `docs/04-calcs/results.csv` (BKH-CAL-001 v0.1).
- `cad/src/model.py`: parametric build123d model with constructability checks (no overlaps, nothing floating); STEP and STL in `cad/step` and `cad/stl` (bank station, far end, table; assembly STEP at the 30 m design case).
- `cad/src/sheets.py`: BKH-DWG-001 (bank station GA), BKH-DWG-002 (far end GA) and BKH-DWG-003 (layout, shortened), Rev P2.
- `bom/bom.csv`: 17 lines, all priced, with suppliers by type.
- `cad/src/concept_media.py`: `media/hero.png`, `exploded.png`, `flow.png`, `concept-blueprint.png` and `.pdf` (BKH-DWG-010), `model.glb` (about 1 MB, coarse tessellation) and `viewer.html`. No cutaway (the inside does not matter).
- `docs/decisions/0002-design-for-construction.md` (BKH-DDR-002); `design_state: constructable`.
- `cad/src/build_plan_media.py`: overview, seven making sketches (BKH-DWG-101 to 107), eight joint close-ups and eleven step pictures; `docs/05-build-plan.md` (BKH-BLD-001) and `docs/06-design-decisions.md` (BKH-DEC-001).
- `cad/src/product_model.py` (`product_parts()`, `TITLE`, `RENDER_VIEWS` hero, exploded, detail); scenes exported to `/home/claude/renders/bankhaul` (three .npz and .json, `bankhaul__jobs.json`). Photoreal renders, captions and cards are made on Amish's Mac; the README already leads with `media/render-hero.png`.
- `README.md`, `project.yaml` (trl 3, trl_target 3).

**Results (BKH-CAL-001).** Loop 60.4 m for the 30 m span; peak hand pull about 200 N to haul a 30 m net with 10 kg of catch; setting pull about 43 N; weak link 510 to 690 N, 8.3 times the normal load; far end design load 1.38 kN; stays 2.1 kN each at the 3 kN bank load; screw anchors 4.4 kN each (factor 2.13); far stake 3.7 kN in soft mud (factor 2.46) and 1.8 kN in very soft mud (factor 1.23), bending 150 to 162 MPa in S355; rope factor 5.7 after a season's sun; cycle 6.3 minutes without clearing fish; relocation 22 minutes; station about 100 kg, heaviest part the 26.8 kg stake. Value-engineering target: USD 1,800. Estimated cost of the constructable design: USD 392 (USD 1,408 under the target); station parts USD 382.

**Requirements not met or at risk.**

- **R5, at risk in very soft mud:** met in soft mud (factor 2.46) but factor 1.23 where the bed is very soft.
- **R8, not met:** USD 382 per station.
- R1, R3, R4, R6, R7, R9 and R10 are met on paper or as estimates and are settled by the TRL 4 trials; R6 excludes clearing fish (about 10 minutes for a 10 kg catch), which the loop does not change.

**Decisions for Amish.**

*Decision 1: R5, far stake holding in very soft mud.* State: in a bed with about 5 kPa shear strength, the 76.1 mm stake driven 2.5 m holds an ultimate 1,845 N, a factor of 1.23 on the R5 load, against the factor of 2 used as "holds"; in soft mud (10 kPa) it holds 3,689 N, factor 2.46. Cause: lateral capacity in clay falls in proportion to its strength, and the load acts 1.2 m above the bed.

| Option | Effect on R5 (very soft mud) | Cost | Mass |
| --- | --- | --- | --- |
| A: drive 3.5 m into very soft beds (stake 5.0 m long) | Factor 2.03, met | About USD 12 more per stake | 6.4 kg more (33 kg stake) |
| B: two stakes 1 m apart, tied at the top with a bar carrying the collar | Factor 2.21, met | About USD 56 more | About 28 kg more; two to drive from the boat |
| C: keep 2.5 m and site stations only where a hand vane shows 10 kPa or more | Factor 2.46 where used; very soft beds excluded | None | None |

**Recommendation: A.** It keeps one stake and one driving method, meets R5 in very soft mud for USD 12, and the 1 m extra is cut only for sites that the vane test shows need it.

*Decision 2: R8, cost per station.* State: the constructable station costs USD 382 in parts, about 4.8 times the R8 figure. Cause: bought rated hardware (two screw anchors USD 76, two blocks USD 44, shackles and turnbuckles USD 27) and steel stake and post (USD 80) dominate; the rope is USD 54.

| Option | Effect on R8 | Cost | Mass |
| --- | --- | --- | --- |
| A: build this steel station for the TRL 4 trials; cost a local-materials station with the co-design partner from local prices before the season pilot | Not met for the trial station; a local figure replaces the estimate | USD 382 now | About 100 kg |
| B: switch the prototype now to local materials: hardwood post and far pole, buried timber deadman, two hand-made hardwood sheaves, rope cut to a 30 m span, hardwood cleats, pole table | About USD 98: not met, close; R7 (sheave wear, timber rot) and R9 (digging a deadman, about 45 minutes) become at risk | About USD 98 | About 30 kg more (timber pole and deadman) |
| C: one bank post and table serve three loops at a landing site (post head with three pad eyes) | About USD 257 per loop: not met | About USD 257 per loop | About 60 kg per loop |

**Recommendation: A.** The steel station has known strengths, so the TRL 4 trials test the method rather than the materials; the local-materials costing then gives a real R8 figure for the season pilot.

**Decisions made under the pre-approvals.** BKH-DDR-002, the twelve design-for-construction changes (listed below); the appearance model additions (below). All in `docs/06-design-decisions.md`. Open decisions: the two above, "Proposed, awaiting Amish".

**Build plan findings (design changes made for construction, BKH-DDR-002).**

1. Bank post as a 48.3 mm tube on a 350 mm foot plate and spike, held back by two stays: the post only carries compression.
2. Pad eye at 950 mm with the near block on a shackle.
3. Two stay lugs splayed 22 degrees, 960 mm up.
4. Cleat bar slipped over the post for the jam cleats and the tie-off hole.
5. Screw anchors set in line with the stays, helix 0.9 m deep.
6. Far stake 76.1 x 3.6 mm S355; a 60.3 mm tube would reach about 250 MPa at the R5 load.
7. Welded point and cap disc on the stake; a driving cap tool added.
8. Swivel collar with 3 mm clearance on a moveable M12 stop pin, five holes at 200 mm.
9. Block eye and spacer outside the rope wrap; loop leaves each block level.
10. Loop as two halves joined by swivel rings, one end spliced and one hitched, so the span can change.
11. Net bridles with calibrated weak links and snap hooks.
12. Slatted table with lip boards, landward of the post and clear of the stays.

**Appearance model.** `product_model.py` uses the `model.py` solids in the shortened layout. Additions not in `model.py`: the loop and rings cut into a bank part and a far part, the stake shown above the bed only, a net stacked on the table, and a 1.75 m mannequin (`mannequin()`, standing, facing the water) beside the post and to the left of it as seen by the hero camera, never between the camera and the station. Decided under the pre-approvals.

**Safety concerns.**

- Placing the far stake from a boat in crocodile water is the most exposed job; it is a safety stop in the build plan, with two people and a lookout.
- A net seized by a large crocodile: the weak link bounds the load at about 700 N, but only if the link is never replaced with stronger cord; it is painted and tested by batch.
- Rope and stay snap-back: anchors sized at factor 2; nobody in the bight of the loop or in line with a stay.
- Floating debris can load the loop beyond its design; the loop comes out before floods.
- The 5 m working distance is a judgement, not data; the wildlife authority's advice may call for more at a given site.

**Recommended next step.** After Amish decides the two items above, the design is ready for TRL 4 when the phase allows: build one station, run the R4, R5 and R10 proof loads on CalRig or in place, then set and haul trials with the first co-design candidate. Suggestion not added to the repo: a float-and-mooring far end for beds deeper than 1.5 m.

## Session 2026-09-30: scaffolded

### What was done

- Repository created from kit 1.6.0 at TRL 1, target TRL 2.
- `docs/01-problem.md` (BKH-PRB-001 v0.1): problem with cited evidence, users, environment, constraints, prior work, open questions.
- `docs/02-concept.md` (BKH-PRC-001 v0.1): how it works, components, patent design-arounds, shared blocks, safety.
- `docs/03-requirements.md` (BKH-REQ-001 v0.1): 9 proposed requirements.
- `README.md` with concept rationale, burning platform, where it could be used, and what sparked the idea.

### Next

- Run `/populate` to bring the repo to a strong TRL 2 with concept media.

## 2026-10-03: photoreal renders

Rendered with Blender Cycles on Amish's Mac from `cad/src/product_model.py`; captioned with `.kit/photo_caption.py`; `media/card.png` and `media/social-preview.png` made with `.kit/cards.py`. Views: hero, exploded, detail. image_qc passes and `render.py --check` has no FAIL.

## 2026-10-04: photoreal renders redone after the round-2 and round-3 decisions

Views: hero, exploded, detail; cards regenerated; image_qc passes and `render.py --check` has no FAIL.

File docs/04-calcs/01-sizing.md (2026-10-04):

---
doc_id: BKH-CAL-001
title: BankHaul sizing calculations
project: BankHaul
doc_type: Calculation
version: "0.2"
status: Draft
date: '2026-10-03'
author: Amish Chadha
license: CERN-OHL-S-2.0
revisions:
- version: "0.1"
  date: '2026-10-03'
  author: Amish Chadha
  change: First sizing note at TRL 3 for the constructable design (BKH-DDR-002)
- version: "0.2"
  date: '2026-10-03'
  author: Amish Chadha
  change: Amish's decisions 14A and 15A (BKH-DDR-003); far stake driven 3.5 m (R5 met in very soft mud); R8 restated; cost and mass updated
---

# BankHaul sizing calculations

The constructable design meets ten of the eleven requirements on paper. Amish decided both open items on 2026-10-03 (Amish, 2026-10-03: "i agree with all the 46 recommendations you provided. please proceed."): the far stake is now driven 3.5 m (decision 14A), so R5 is met in very soft mud at a factor of 2.03; and R8 is restated (decision 15A): the steel station is built for the TRL 4 trials at USD 394 in parts, and the under USD 80 figure applies to a local-materials station costed with the co-design partner, estimated here at USD 98 and so not yet met. Every figure below is produced by `docs/04-calcs/sizing.py` from the parameters in `cad/src/model.py`; `docs/04-calcs/results.csv` holds the results table. Values marked "estimate" are first-order and are checked by test at TRL 4.

> **Safety:** These calculations size a rope system that works under load beside crocodile water. They are first-order and are not a substitute for proof-load tests on the anchors, stake, rope splices and weak links before the station is used.

## Results against requirements

Table 1. Results against every requirement

| ID | Target | Result | Status | Section |
| --- | --- | --- | --- | --- |
| R1 | Set and haul with nobody in the water | No step needs anyone in the water once the far stake is set from a boat | Met on paper; field trial at TRL 4 | J |
| R2 | At least 30 m between pulleys; stretch 50 m | 30 m design case; rope bought for 50 m | Met on paper | A |
| R3 | Peak pull under 250 N | 200 N (estimate) | Met on paper | B |
| R4 | Holds 3 kN in soft wet soil without movement | Anchor factor 2.13 at 10 kPa | Met on paper; pull test at TRL 4 | D |
| R5 | Holds 1.5 kN horizontal in soft mud | Factor 4.05 at 10 kPa; 2.03 at 5 kPa (3.5 m embedded) | Met on paper in soft and very soft mud; pull test at TRL 4 | E |
| R6 | Full haul and reset under 10 min | 6.3 min (estimate, without clearing fish) | Met on paper (estimate) | G |
| R7 | One season without rope or pulley failure | Rope factor 5.7 after sun damage | Met on paper (estimate) | F |
| R8 | Local-materials station parts under USD 80, costed with the partner; steel trial station recorded (restated, decision 15A) | Steel trial station USD 394; local-materials station about USD 98 (estimate) | Steel trial station accepted for TRL 4; **local-materials figure not yet met** (estimate), to be costed with the partner | I |
| R9 | Relocated by two people in under 30 min | 22 min (estimate) | Met on paper (estimate) | H |
| R10 | Weak link releases 500 to 700 N | 510 to 690 N | Met on paper; calibrate at TRL 4 | C |
| R11 | Working spot at least 5 m from the water | 5.0 m | Met by layout | J |

## A. Loop and rope

Assumptions: 12 mm floating polypropylene and polyethylene blend rope ("polysteel"), 20 kN minimum breaking strength, 0.068 kg/m, density about 0.93; blocks with 100 mm sheaves, so the rope centre runs on a 56 mm radius.

- Loop length for the 30 m design span: 2 x 30 + 2 x pi x 0.056 = **60.4 m**; for the 50 m stretch span, 100.4 m.
- Rope bought: 120 m, cut into two halves of 55 m (each 5 m longer than the 50 m span for splices and knots), leaving 10 m spare. The surplus of each half is coiled at its ring, which never passes a block.
- The loop for 30 m weighs 4.1 kg and floats.
- Sheave to rope diameter ratio: 100 / 12 = **8.3**, at the usual minimum of 8 for fibre rope.

## B. Hand pull to haul a 30 m net with catch (R3), estimate

Assumptions: a 30 m by 2 m gillnet with a 0.06 kg/m lead line, 1.2 kg of twine and a 0.03 kg/m float line; the wet net is 1.6 times its dry mass; 10 kg of catch and 5 kg of weed or debris; friction 0.6 on the bed and the wet bank; hauling at 0.4 m/s; the bank edge rises 0.5 m over 1 m (27 degrees); the fisher stacks the net on the table as it arrives, so about a fifth of the net is on the bank edge at once.

| Load | Value | Basis |
| --- | --- | --- |
| Lead line friction on the bed | 9.7 N | Submerged weight of the lead line x 0.6 |
| Drag of the bunched net and catch | 40.0 N | 0.5 x 1,000 x 0.4² x 0.5 m² |
| Catch, weed and a fifth of the net up the bank edge | 156.8 N | 15.9 kg x 9.81 x (0.6 cos 27° + sin 27°) |
| Loop following round both blocks | 18.3 N | Rope friction on the ground, block efficiency 0.95 each |
| **Peak hand pull** | **200 N** | Bank edge load, half the water loads, loop |

The peak comes at the instant the whole catch is on the bank edge. Hauling is done by the net's near end, so the loop only follows. Setting the net takes about **43 N** at 0.5 m/s.

## C. Weak link (R10) and design loads

The weak link sets the largest load a seized or snagged net can put into the system.

- Release: nominal **600 N**, plus or minus 15 % (510 to 690 N). The cord is chosen by pulling three samples from the batch bought.
- The largest load in normal use is during setting, **62 N**, so the lowest release is **8.3 times** the normal load: no nuisance breaks.
- Far end design load: both legs at the highest release, **1.38 kN**, within the 1.5 kN of R5.
- Bank design load: **3.0 kN** (R4) horizontal at the near block. It covers twice the link release, debris on the loop and a jammed cleat.

## D. Bank post, stays and screw anchors (R4)

Assumptions: soft wet soil with an undrained shear strength of 10 kPa; anchors with a single 250 mm helix on a 1.6 m rod, set in line with the stay; capacity Q = Fc x su x A with Fc = 9 for a deep helix (depth to helix diameter 3.6, at the critical depth for this soil).

| Quantity | Value | Note |
| --- | --- | --- |
| Stay length, lug hole to anchor eye | 1.44 m | Anchor eyes 1,100 mm behind and 450 mm either side |
| Stay elevation | 38.7° | |
| Stay tension at 3 kN | **2,076 N** each | Both stays share the pull along the line |
| Stay rope factor | 9.0 | 10 mm polyester, 22 kN, 85 % at the eye splice |
| Post compression | 2,595 N | Buckling factor 93 (48.3 x 3.2 tube, 1.0 m, pinned) |
| Foot plate bearing | 22.6 kPa | Factor 2.3 on 5.14 x su |
| Helix depth | 0.89 m | |
| Anchor capacity | **4,418 N** each | Factor **2.13** on the stay tension |
| Pad eye shear | 33.6 MPa | Block load 6 kN, two shear planes |
| Block working load factor | 1.67 | 500 kg block, two legs at 1.5 kN |

A factor of 2 or more on the anchor's ultimate capacity is taken as "no visible movement", since helical anchors creep noticeably above about half their ultimate load. R4 is met on paper; the TRL 4 pull test on a CalRig-style rig settles it.

## E. Far stake lateral capacity (R5)

Method: Broms' short free-head pile in cohesive soil. The load acts 1.2 m above the bed (1.0 m of water plus 0.2 m to the far block). The stake is a 76.1 x 3.6 mm S355 tube, 5.0 m long, embedded 3.5 m (decision 14A, BKH-DDR-003; Amish, 2026-10-03: "i agree with all the 46 recommendations you provided. please proceed.").

| Bed | Undrained shear strength | Ultimate lateral load | Factor on 1.5 kN | Bending stress at 1.5 kN |
| --- | --- | --- | --- | --- |
| Soft mud | 10 kPa | 6,079 N | **4.05** | 150 MPa (factor 2.4 on S355) |
| Very soft mud | 5 kPa | 3,040 N | **2.03** | 162 MPa (factor 2.2 on S355) |

A 60.3 mm stake would carry the load in soft mud but reach about 250 MPa at 1.5 kN, too close to yield; the 76.1 mm tube was chosen for strength (BKH-DDR-002, item 6). The bending stress at the R5 load does not change with embedment, since the largest moment lies within about 0.6 m of the bed.

At the first TRL 3 embedment of 2.5 m the factor in very soft mud was **1.23**, so R5 was at risk there. Driving the stake 1.0 m deeper raises it to **2.03**: R5 is now **met on paper in soft and very soft mud**. The stake is 1.0 m longer, 6.4 kg heavier (33.2 kg) and USD 12 dearer. The TRL 4 pull test from the boat settles it.

## F. Loop rope strength and durability (R7)

- The largest leg tension is the larger of the link's highest release and half the bank load: 1.5 kN. The new rope through a splice (85 %) has a factor of **11.3** on it.
- Assuming the rope loses half its strength to sun over a tropical season, the factor at the end of the season is **5.7**.
- Two set and haul cycles a day for 180 days give about 720 passes over each sheave, far below the bending fatigue life of fibre rope at a sheave ratio of 8.
- Blocks with bushed nylon sheaves in silty water are the less certain part; the season pilot at TRL 4 records bush wear.

R7 is met on paper as an estimate.

## G. Cycle time (R6), estimate

Haul at 0.25 m/s with stacking (2.0 min), unclip (1.0 min), re-clip (1.0 min), set 30 m at 0.4 m/s (1.3 min), cleat and tie off (1.0 min): **6.3 minutes**. Clearing a 10 kg catch of about 30 fish at 20 s each takes a further 10 minutes, as it does today; the loop does not change it, so it is outside this figure.

## H. Relocation (R9), estimate

Two people: unscrew both anchors (4 min), lift out the post and spike (2), carry up to 50 m (3), set out the new spot (3), screw in both anchors (6), stand the post and tension the stays (4): **22 minutes**. Re-tying both ring knots for the new loop length takes about 6 minutes more and is outside R9, which covers the bank anchor.

## I. Cost per station (R8) and value engineering

The station parts in `bom/bom.csv` cost **USD 394** (the 5.0 m far stake adds USD 12); with the stake driving cap, the prototype costs USD 404. Value-engineering target: USD 1,800. Estimated cost of the constructable design: USD 404 (USD 1,396 under the target).

The largest cost drivers are the two screw anchors (USD 76), the far stake (USD 60), the rope (USD 54), the two blocks (USD 44), the table (USD 35) and the post (USD 32).

R8 is restated (decision 15A, BKH-DDR-003; Amish, 2026-10-03: "i agree with all the 46 recommendations you provided. please proceed."). The steel station is built for the TRL 4 trials, so the trials test the method with parts of known strength; its USD 394 is recorded, not held to the R8 figure. The USD 80 figure applies to a local-materials station, costed from local prices with the co-design partner before the season pilot. The first-order estimate of that station (hardwood post with bolted fittings, buried timber deadman, hardwood far pole, two hand-made hardwood sheaves on steel pins, rope for a 30 m span only, galvanised rings, hardwood cleats, a pole table) is about **USD 98**, so the restated R8 is **not yet met** on this estimate. For reference, one bank post and table serving three loops would cost about USD 269 per loop.

## J. Layout and masses

- The post stands 6 m back from the water's edge and the fisher works within 1 m of it: **5.0 m** from the water (R11).
- Once the far stake is set from a boat or at low water, setting, hauling, clearing and relocating the bank station are all done from the bank (R1).
- Masses: bank post weldment 17.2 kg, far stake 33.2 kg, two screw anchors 14.3 kg, clearing table 26.4 kg, swivel collar 1.6 kg, two blocks 2.2 kg, rope 7.5 kg, small parts about 4 kg: about **106 kg** for the station. The heaviest part is the far stake, handled by two people from a boat.

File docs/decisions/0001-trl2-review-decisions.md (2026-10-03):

---
doc_id: BKH-DDR-001
title: BankHaul TRL 2 review decisions
project: BankHaul
doc_type: Design decision record
version: "0.1"
status: Draft
date: '2026-10-03'
author: Amish Chadha
license: CERN-OHL-S-2.0
revisions:
- version: "0.1"
  date: '2026-10-03'
  author: Amish Chadha
  change: TRL 2 review items decided under Amish's pre-approvals of 2026-10-03
---

# 0001: TRL 2 review decisions

- **Date:** 2026-10-03
- **Status:** accepted

## Context

The TRL 2 review (`docs/REVIEW.md`, TRL 2 section) raised the items below. On 2026-10-03 Amish wrote: "start with the first 14 repos from the list of 29 projects. I pre-approve the batch runs along with any recommendations you come up with. I also accept any cost overruns or variations from the assumed scope cost." He then wrote: "Proceed with the remaining 15 scaffolds", under the same pre-approval, which covers BankHaul. Every design recommendation below is therefore decided as recommended. Choices that touch safety take the conservative option, with the evidence that would relax them stated. Partners and regions are the first candidates to approach, not agreements. Requirements that are not met or at risk on paper (R5 in very soft mud, R8) are not decided here; they are posed to Amish in `docs/REVIEW.md` under "Decisions for Amish".

## Options considered

Table 1 lists the options for each item and the one chosen.

## Decision

*Table 1. Items decided on 2026-10-03 under Amish's pre-approvals.*

| # | Item | Options | Decision | What would relax a safety choice |
| --- | --- | --- | --- | --- |
| 1 | Bank anchor | (a) post driven or concreted in as a cantilever; (b) buried timber deadman; (c) post on a foot plate held back by two stays to screw ground anchors | (c), conservative: the stays take the pull as tension and the anchors can be moved in about 22 minutes (R9). Anchors sized at a factor of 2 on the R4 load | Pull tests at the trial site showing a holding factor above 3 would allow one anchor in firm soil |
| 2 | Far end for the first prototype | (a) driven stake; (b) float held by a sinker | (a) for the prototype, because a float that holds 1.5 kN sideways needs a sinker or anchor heavier than two people can place from a canoe. The float is kept as a variant for deep beds, not built in the first prototype | Not a safety choice |
| 3 | Load limit on the net | (a) none, size everything on what a crocodile can pull; (b) a weak link at each net end | (b), conservative: R10 added, release 500 to 700 N. The far end then sees 1.4 kN at most | Release tests showing a tighter scatter could narrow the band, never raise its top above 700 N |
| 4 | Where the fisher works | At the water's edge; 3 m back; 5 m back | At least 5 m back, conservative: R11 added; the post stands 6 m from the water | Local attack-distance data from the wildlife authority could support a different distance at a given site |
| 5 | Loop rope | 10 mm sinking polyester; 12 mm floating polysteel | 12 mm floating polysteel: a hand-hauling grip, stays visible and clear of the bed, factor 5.7 after a season's sun | Not relaxed |
| 6 | Clip points | (a) knots or hitches tied anywhere on the loop; (b) two swivel rings half a loop apart that join the loop halves | (b): the rings are the clip rings and the end stops and never run round a block if the net is at least 2 m shorter than the span | Not a safety choice |
| 7 | Bank brake | (a) horn cleat; (b) ratchet block; (c) a jam cleat for each leg | (c): either leg drops into its cleat between pulls and holds against an offshore pull | Not relaxed |
| 8 | How the net is hauled | (a) by the loop, far end first; (b) by the net's near end, with the loop following | (b): the net comes in straight onto the table without doubling back; the weak links stay out of the hauling load | Not a safety choice |
| 9 | Floods | Leave the loop in; take it out | Take the loop out before a flood; floating debris can load it far beyond its design | Not relaxed |
| 10 | Co-design partner | A wildlife authority; a researcher with local attack data; a fisher association | First candidate to approach: the Lake Kariba research group behind the Oryx study (Matanzima, Marowa and Nhiwatiwa), together with an inshore fishing cooperative on the Zimbabwean shore (not agreed) | |
| 11 | Shared blocks | CalRig for proof loads; hand capstan from SaltDrag and SiltHaul | CalRig is the first candidate rig for the anchor, stake and weak link tests at TRL 4. The hand capstan is not used: the peak pull is about 200 N, and the design-around excludes powered hauling | |
| 12 | Budget | Keep `budget_usd` at 1,800 | Kept; it is a value-engineering target, not a limit | |

## Consequences

- R10 (weak link) and R11 (working distance) are added to BKH-REQ-001.
- The design for construction (BKH-DDR-002) works from these choices.
- R5 in very soft mud and R8 are posed to Amish as decisions; they are listed as "Proposed, awaiting Amish" in `docs/06-design-decisions.md`.

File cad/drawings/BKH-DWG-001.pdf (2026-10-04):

CONCEPT, NOT FOR FABRICATION | BankHaul · github.com/BoujeeEnjinia1701/bankhaul

FRONT VIEW
Scale 1:50; looking at the front (along +Y)

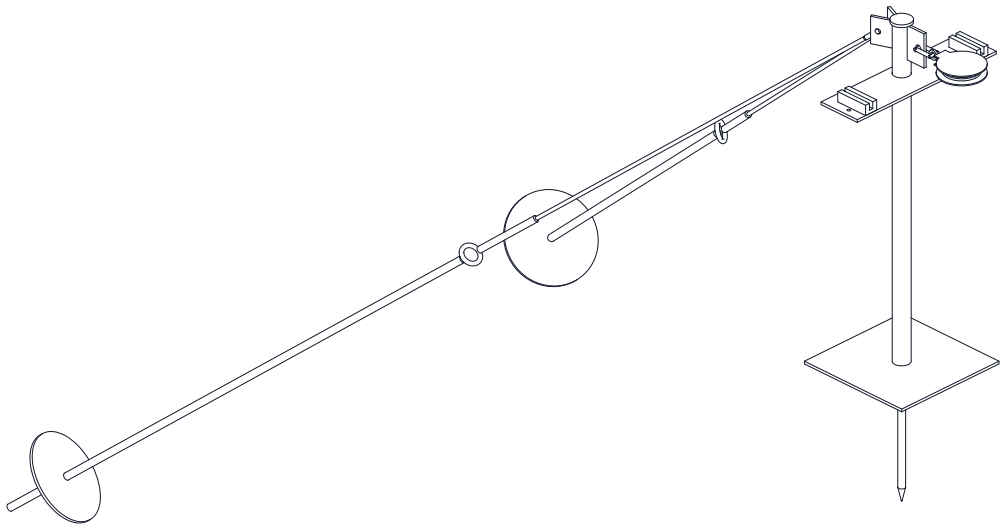
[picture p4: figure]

TOP VIEW
Scale 1:50; looking down (along -Z)

RIGHT VIEW
Scale 1:50; looking at the right side (along -X)

2566

1989 1974

ISOMETRIC VIEW
Not to scale; ground at z = 0; seen from the front right and above, about 30 deg elevation

MAIN DIMENSIONS AND INTERFACES (MM)
Post 48.3 x 3.2 tube, head 1,000 above the ground; weldment 17.2 kg (1) Foot plate 350 x 350 x 8; ground spike 20 round, 400 below the plate
Pad eye 18 hole 64 from the post axis, 950 up; near block on a shackle (8, 13) Near sheave centre 216 in front of the post; legs 112 apart
Two stay lugs, 15 holes, 960 up, splayed 22.2 deg either side of the line
Back-stays 10 rope with M12 turnbuckles to the anchor eyes (5, 12)
Anchor eyes 1,100 behind and 450 either side; rods in line with the stays (11)
Cleat bar 130 x 500 x 8 slipped over the post, top 850 up; jam cleats 200 either side (10) Tie-off hole 15 dia in the cleat bar for the net's near end
Third-angle; front view from -Y; the loop runs out to +X; (n) = BOM line
REV | DESCRIPTION | DATE | BY
P1 | Preliminary GA for TRL 3 (from cad/src/model.py) | 2026-10-03 | AC
P2 | BKH-DDR-002: design for construction | 2026-10-03 | AC
P3 | BKH-DDR-003: far stake 5.0 m long, driven 3.5 m (decision 14A) | 2026-10-03 | AC
BANKHAUL | github.com/BoujeeEnjinia1701/bankhaul

## Bank station: general arrangement

DRAWING NO.
BKH-DWG-001

REV
P3

SHEET
1 of 1

SIZE

## ANSI B

SCALE
1:50

UNITS
mm
PROJECTION | DATE
2026-10-03

DRAWN
Amish Chadha

MATERIAL / NOTES
Steel weldment, bought blocks, anchors and rigging per bom/bom.csv. PRELIMINARY, NOT FOR FABRICATION
Licensed CERN-OHL-S-2.0 · Design Molecule Lab · designmolecule.com | Generated from cad/src; do not edit by hand

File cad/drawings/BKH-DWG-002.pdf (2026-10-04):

CONCEPT, NOT FOR FABRICATION | BankHaul · github.com/BoujeeEnjinia1701/bankhaul

FRONT VIEW
Scale 1:50; looking at the front (along +Y)

TOP VIEW
Scale 1:50; looking down (along -Z)

RIGHT VIEW
Scale 1:50; looking at the right side (along -X)

336

130 5006

ISOMETRIC VIEW
Not to scale; seen from the front right and above, about 30 deg elevation

MAIN DIMENSIONS AND INTERFACES (MM)
Stake 76.1 x 3.6 S355 tube, 5,000 long overall with a 150 point; 33.2 kg (2) Driven 3,500 into the bed; design water depth 1,000; top 500 above the water Cap disc 6 thick takes the driving cap; never drive on the open tube
Five 12.5 holes at 200 pitch for the M12 stop pin (14)
Collar 88.9 x 3.2 x 200 turns on the stake and rests on the pin (3)
Collar lug 8 thick, 18 hole 75 from the stake axis
Far sheave 200 above the water at the design level (8, 13)
Move the pin up or down a hole to follow the season's water level Lateral capacity: BKH-CAL-001, section E (factor 2.03 in very soft mud) Third-angle; front view from -Y; the loop arrives from -X; (n) = BOM line
REV | DESCRIPTION | DATE | BY
P1 | Preliminary GA for TRL 3 (from cad/src/model.py) | 2026-10-03 | AC
P2 | BKH-DDR-002: design for construction | 2026-10-03 | AC
P3 | BKH-DDR-003: far stake 5.0 m long, driven 3.5 m (decision 14A) | 2026-10-03 | AC
BANKHAUL | github.com/BoujeeEnjinia1701/bankhaul

## Far end: stake, swivel collar and far block, general arrangement

DRAWING NO.
BKH-DWG-002

REV
P3

SHEET
1 of 1

SIZE

## ANSI B

SCALE
1:50

UNITS
mm
PROJECTION | DATE
2026-10-03

DRAWN
Amish Chadha

MATERIAL / NOTES
Steel tube S355 per bom/bom.csv; bought block and shackle. PRELIMINARY, NOT FOR FABRICATION
Licensed CERN-OHL-S-2.0 · Design Molecule Lab · designmolecule.com | Generated from cad/src; do not edit by hand

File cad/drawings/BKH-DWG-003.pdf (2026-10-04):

CONCEPT, NOT FOR FABRICATION | BankHaul · github.com/BoujeeEnjinia1701/bankhaul

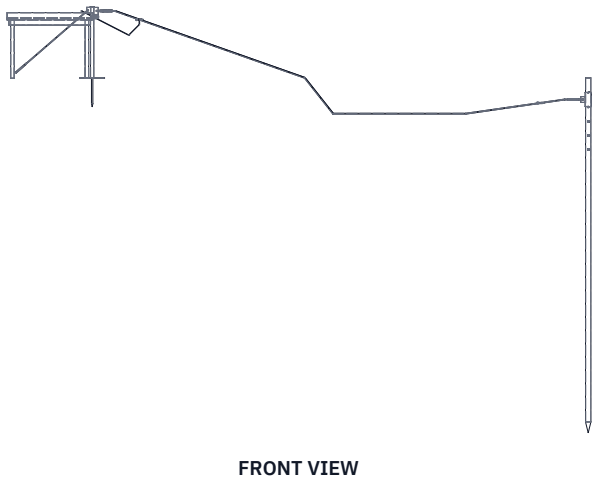
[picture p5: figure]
FRONT VIEW

Scale 1:100; looking at the front (along +Y)

TOP VIEW
Scale 1:100; looking down (along -Z)

8244

1750 6008

ISOMETRIC VIEW
Not to scale; span shortened to 7 m; seen from the front right and above, about 30 deg elevation

LAYOUT RULES (MM)
Design span 30,000 between sheave centres; stretch 50,000 (R2) Post at least 6,000 back from the water's edge (R11)
The fisher works within 1,000 of the post, never nearer the water Loop legs 112 apart, floating; the net is set along the -Y leg
Net no longer than the span less 2,000, so no ring reaches a block Loop direction within the stays' splay (22 deg either side) Clearing table landward on the +Y side, clear of the stays
Far stake set from a boat or at low water, never by wading Nobody in the bight of the loop or in line with a loaded stay Third-angle; front view from -Y; X along the loop
REV | DESCRIPTION | DATE | BY
P1 | Preliminary GA for TRL 3 (from cad/src/model.py) | 2026-10-03 | AC
P2 | BKH-DDR-002: design for construction | 2026-10-03 | AC
P3 | BKH-DDR-003: far stake 5.0 m long, driven 3.5 m (decision 14A) | 2026-10-03 | AC
BANKHAUL | github.com/BoujeeEnjinia1701/bankhaul

## Net-hauling station: layout (span shortened)

DRAWING NO.
BKH-DWG-003

REV
P3

SHEET
1 of 1

SIZE

## ANSI B

SCALE
1:100

UNITS
mm
PROJECTION | DATE
2026-10-03

DRAWN
Amish Chadha

MATERIAL / NOTES
Layout only; parts per BKH-DWG-001, 002 and 101 to 107. PRELIMINARY, NOT FOR FABRICATION
Licensed CERN-OHL-S-2.0 · Design Molecule Lab · designmolecule.com | Generated from cad/src; do not edit by hand

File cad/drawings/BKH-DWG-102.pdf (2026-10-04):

### BUILD PLAN SKETCH, PLAN NOT YET BUILT BankHaul · github.com/BoujeeEnjinia1701/bankhaul

FRONT VIEW
Scale 1:50; looking at the front (along +Y)

TOP VIEW
Scale 1:50; looking down (along -Z)

RIGHT VIEW
Scale 1:50; looking at the right side (along -X)

76

76 5006

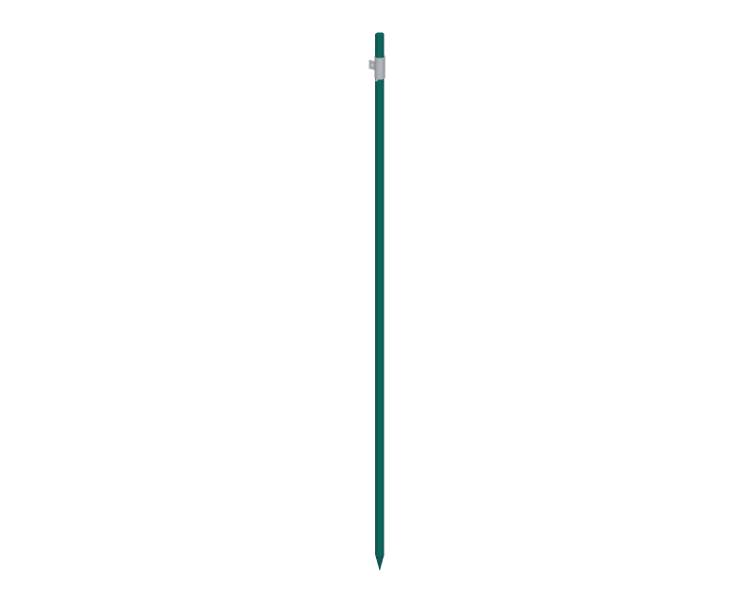
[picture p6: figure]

WHERE IT GOES
This part in colour, its neighbours in grey

HOW TO MAKE IT AND HOW IT FITS
Tube 4,850 long; overall 5,000 with the point; 33 kg, two to lift Point: four 4 mm plate triangles welded to a cone, 150 long
Cap disc 76 dia x 6 welded on the top; it takes every blow
Five 12.5 cross holes at 200 pitch, the top one 712 below the cap Drill the holes square through both walls on one line
Mark a paint ring 3,500 above the point: drive to this ring at the bed
Paint after drilling; leave the bore open to drain
Check: straight within 10 over the length; the pin slides through every hole
REV | DESCRIPTION | DATE | BY
P1 | Making sketch for the prototype build plan | 2026-10-03 | AC
P2 | BKH-DDR-003: stake 5.0 m long, driven 3.5 m (decision 14A) | 2026-10-03 | AC
BANKHAUL | github.com/BoujeeEnjinia1701/bankhaul

## Far stake: making sketch

DRAWING NO.
BKH-DWG-102

REV
P2

SHEET
1 of 1

SIZE

## ANSI B

SCALE
1:50

UNITS
mm
PROJECTION | DATE
2026-10-03

DRAWN
Amish Chadha

MATERIAL / NOTES
76.1 x 3.6 tube, S355; 4 mm plate; 6 mm plate; zinc-rich paint
Licensed CERN-OHL-S-2.0 · Design Molecule Lab · designmolecule.com | Generated from cad/src; do not edit by hand

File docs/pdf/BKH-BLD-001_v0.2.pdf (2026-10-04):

B A N K H A U L · B U I L D P L A N

# BankHaul prototype build plan

Design Molecule Lab · designmolecule.com

D O C U M E N T CO N T RO L

Document ID | BKH-BLD-001 | Version | 0.2
Status | Draft | Date | 2026-10-03
Author | Amish Chadha | License | CERN-OHL-S-2.0
Project TRL | TRL 3 | Proof of concept
Repository | github.com/BoujeeEnjinia1701/bankhaul
Source | docs/05-build-plan.md @ uncommitted

R EV I S I O N H I STO RY

Version | Date | Author | Change
0.2 | 2026-10-03 | Amish Chadha | Far stake 5.0 m long, driven 3.5 m (BKH-DDR-003, Amish's decision 14A); cost updated
0.1 | 2026-10-03 | Amish Chadha | First build plan; design made constructable (BKH-DDR-002)

D R A F T · N O T F O R F A B R I C A T I O N

## BankHaul prototype build plan

Plan, not yet built. How to build the first proof-of-concept station, component by component. Building and testing to it is TRL 4 work. Decisions still to be made are kept in the design decisions register ( docs/06-design-decisions.md ), not here.

Safety: BankHaul is a rope system worked beside crocodile water. Placing the far stake is the most dangerous job in this plan: it is done from a boat or at low water, with a second person watching the water, never by wading. Ropes under load can snap back; nobody stands in the bight of the loop or in line with a loaded stay. Section 6 lists the points where work stops.

### 1. What you are building


Figure 1. Every component of the prototype station, numbered in build order. The far end is drawn beside the bank station so all parts show.
The prototype is one net-hauling station for a 30 m span: a steel post on the bank held back by two rope stays to two screw ground anchors, a block at the post's head, a steel stake driven into the bed with a turning collar and a second block, a loop of floating rope between the blocks, two net bridles with weak links, and a timber clearing table. Seven components are made (the post, stake, collar and table by welding, drilling and carpentry; the stays, loop and bridles by rope work) and seven are bought (blocks, swivel rings, jam cleats, screw anchors, turnbuckles, shackles and a stop pin). The station parts cost about USD 394 from the bill of materials.

### 2. What changed to make it buildable

Component | The concept had | The buildable design has | Why
Bank post | A screw or deadman anchor carrying the pulley at waist height | A steel post on a foot plate and spike, held back by two splayed stays to two screw anchors | A post alone cannot hold 3 kN at waist height in soft soil; the stays take the pull as tension
Near pulley | A pulley on the anchor | A bought swivel block on a shackle through a pad eye at 950 mm | Commodity parts that line up with the loop by themselves
Cleat and brake | A cleat on the anchor | A cleat bar slipped over the post with a jam cleat for each leg and a tie-off hole | The round post has no flat face for a cleat
Screw anchors Not defined | Two anchors with 250 mm helixes,
| | screwed in line with the stays | The rods stay in tension; each holds about twice its load
Far stake | A steel or hardwood stake A 76.1 mm steel tube with a welded point
| | and cap, 5.0 m long, driven 3.5 m into the bed | A lighter stake bends at the design load; a shallower one can lean over in very soft mud
Far pulley and swivel | A pulley with a swivel | A collar that turns on the stake, resting on a stop pin that moves with the water level, with a bought block on a shackle | The collar is the swivel; the pin follows the season
Rope loop | An endless spliced loop | Two halves joined by two swivel rings, one end of each half spliced and the other hitched | The loop length can change with the shoreline; the rings are the clip points and end stops
Net clips | Quick clips | A bridle at each net end with a weak link and a snap hook | A seized net cannot pull more than about 700 N on the loop
Clearing table | A raised table or platform | A slatted timber table with lip boards, landward of the post | Keeps the net on the table, 5 m or more from the water

### 3. Making the components

### 3.1 Bank post weldment

What it is and what it is made from. The post that carries the near block, the jam cleats and the two stays. It is a 48.3 mm by 3.2 mm steel tube on a 350 mm square foot plate 8 mm thick, with a 20 mm round bar spike below, an 8 mm cap disc, an 8 mm pad eye, two 8 mm stay lugs and a 130 by 500 by 8 mm cleat bar. It weighs about 17 kg. How to make it.
Cut the tube 992 mm long with square ends. Cut the foot plate 350 mm square and mark its centre.
Cut the spike 400 mm long and grind a point over the last 40 mm. Weld it square under the foot plate centre, all round.
Stand the tube on the plate centre, square within 1 degree in both directions, and weld all round. Weld the 60 mm cap disc on the top.
Cut the pad eye from 8 mm plate, 84 by 100 mm, and drill an 18 mm hole 64 mm from the post's centre line and 950 mm above the ground. Weld it to the tube on the side that will face the water, top edge flush with the top of the tube.
Cut two stay lugs, 84 by 80 mm, with 15 mm holes 960 mm above the ground. Weld them to the back of the tube, each turned 22 degrees off straight back, one to each side.
Cut the cleat bar 130 by 500 mm and cut a 48.9 mm hole 40 mm from its back edge. Drill four 9 mm holes for the cleats (170 mm and 230 mm either side of the post's centre line, 40 mm in front of it) and one 15 mm tie-off hole. Slide it down the tube until its top is 850 mm above the ground, square to the pad eye, and weld all round. Clean and paint with zinc-rich paint.

1.
2.

3.

4.

5.

6.

7.

How it fits the parts next to it.

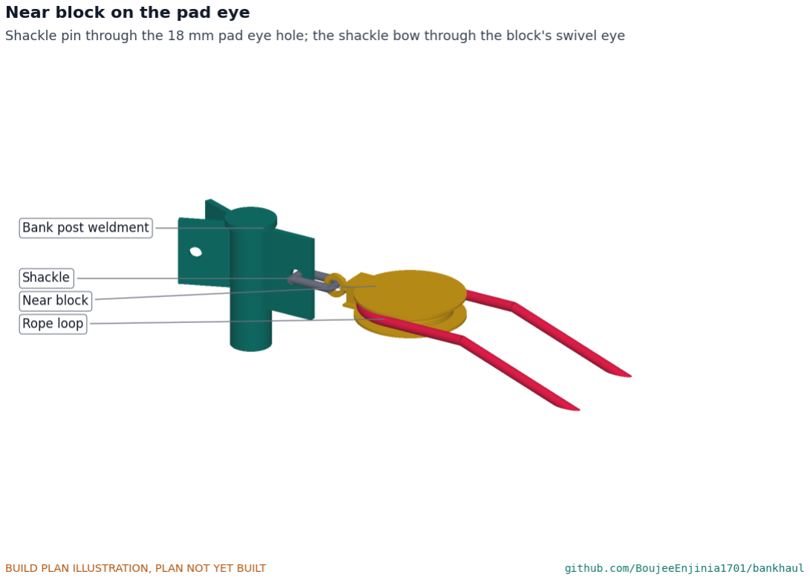
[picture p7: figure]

Figure 2. The near block hangs from the pad eye on a 10 mm shackle. The shackle pin passes through the 18 mm hole; the bow passes through the block's swivel eye. The block lies flat when the loop pulls on it.

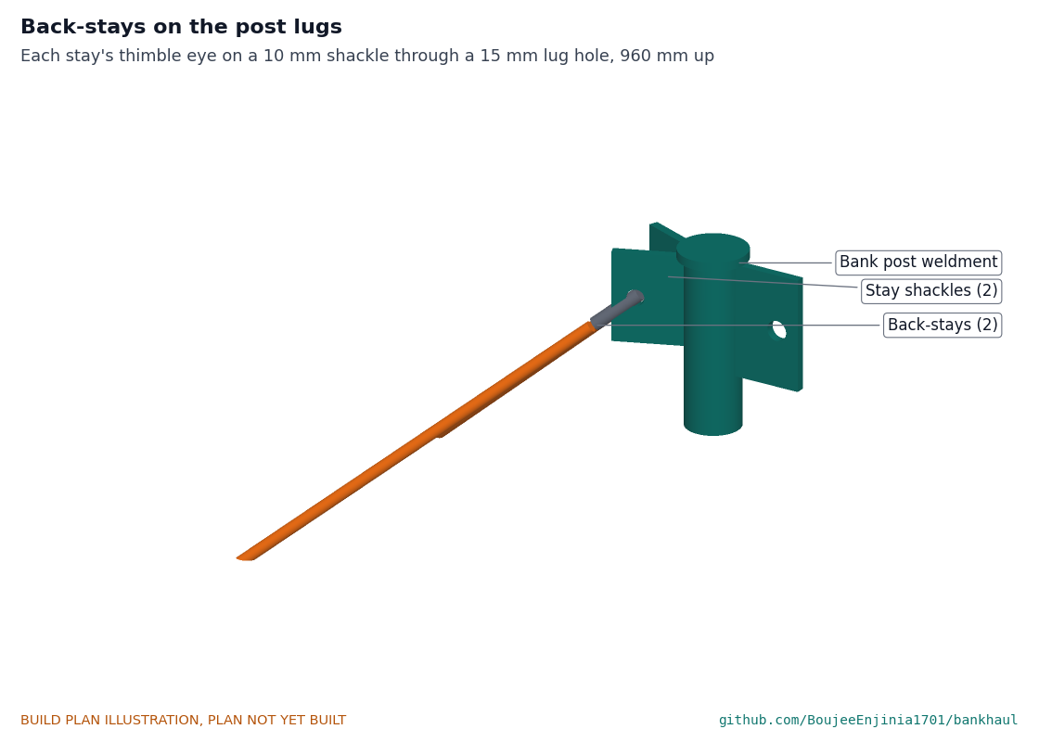
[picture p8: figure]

Figure 3. Each stay's thimble eye is held on a 10 mm shackle through a 15 mm lug hole. The lugs point along the stays, so the shackles pull straight.

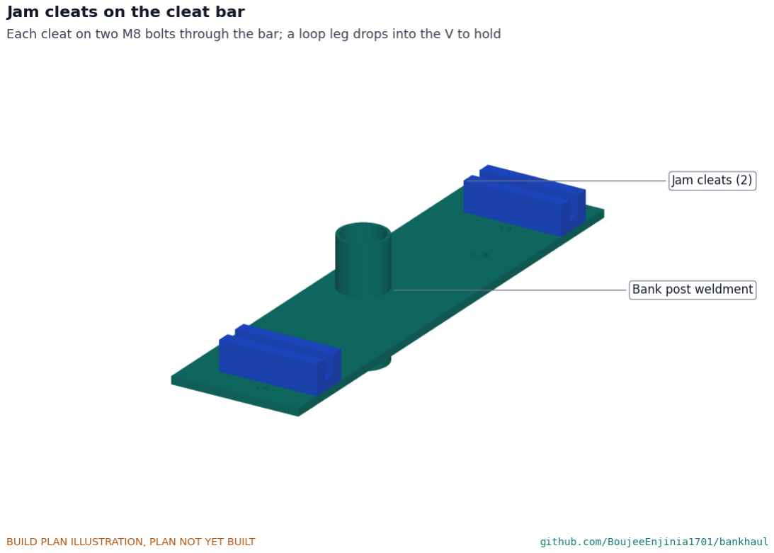
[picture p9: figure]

Figure 4. Each jam cleat sits on the cleat bar on two M8 bolts, its V pointing toward the water, beside one leg of the loop.

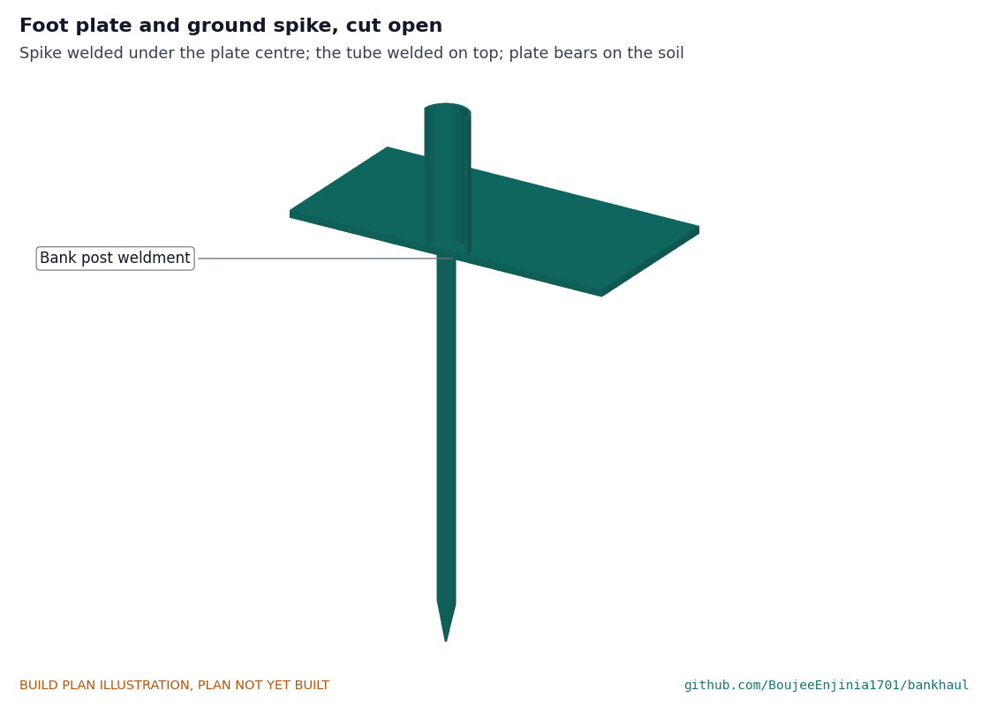
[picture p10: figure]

Figure 5. The spike is welded under the plate centre and the tube on top. The plate bears on the soil; the spike stops it sliding.
Check before moving on. A 10 mm shackle pin passes freely through the pad eye and both lug holes; the tube stands square on the plate; the cleat bar is level.

### 3.2 Far stake

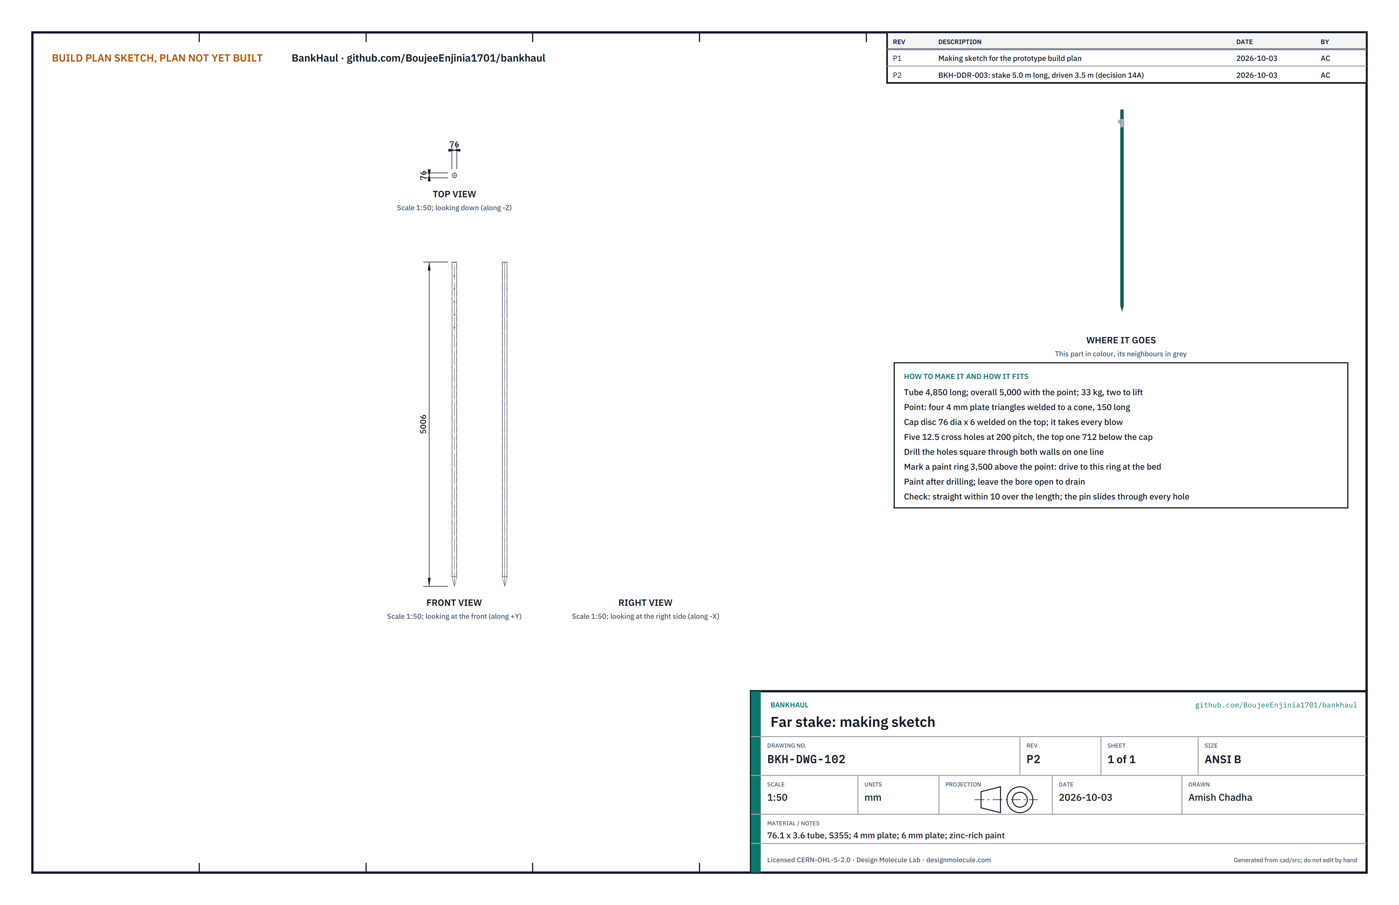
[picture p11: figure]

What it is and what it is made from. The post in the bed that carries the far block. It is a 76.1 mm by 3.6 mm S355 steel tube, 5.0 m long overall with its point, with five cross holes for the stop pin. It weighs about 33 kg, so two people carry and lift it.
How to make it.
Cut the tube 4,850 mm long with square ends.
Cut four triangles from 4 mm plate and weld them into a cone point 150 mm long on one end. Weld a 6 mm cap disc on the other end; this disc takes every blow when driving.
Mark a paint ring 3,500 mm above the point: the stake is driven until this ring reaches the bed.
Drill five 12.5 mm holes straight through both walls on one line, 200 mm apart, the top one 712 mm below the cap.
Paint with zinc-rich paint after drilling.

How it fits the parts next to it. The collar slides over the top and rests on the stop pin (section 3.3, Figure 7). Check before moving on. The stake is straight within 10 mm over its length, and a 12 mm bolt slides through every hole.

1.
2.

3.
4.

5.

### 3.3 Swivel collar

What it is and what it is made from. A short tube that turns on the stake and carries the far block. It is an 88.9 mm by 3.2 mm steel tube, 200 mm long, with an 8 mm lug.
How to make it.
Cut the tube 200 mm long with square ends and remove the burr inside.
Cut the lug from 8 mm plate, 60 by 80 mm, with an 18 mm hole 75 mm from the collar's centre line. Weld the lug to the outside of the tube, square to the tube's axis and centred on its length. Paint.

How it fits the parts next to it.

1.
2.
3.

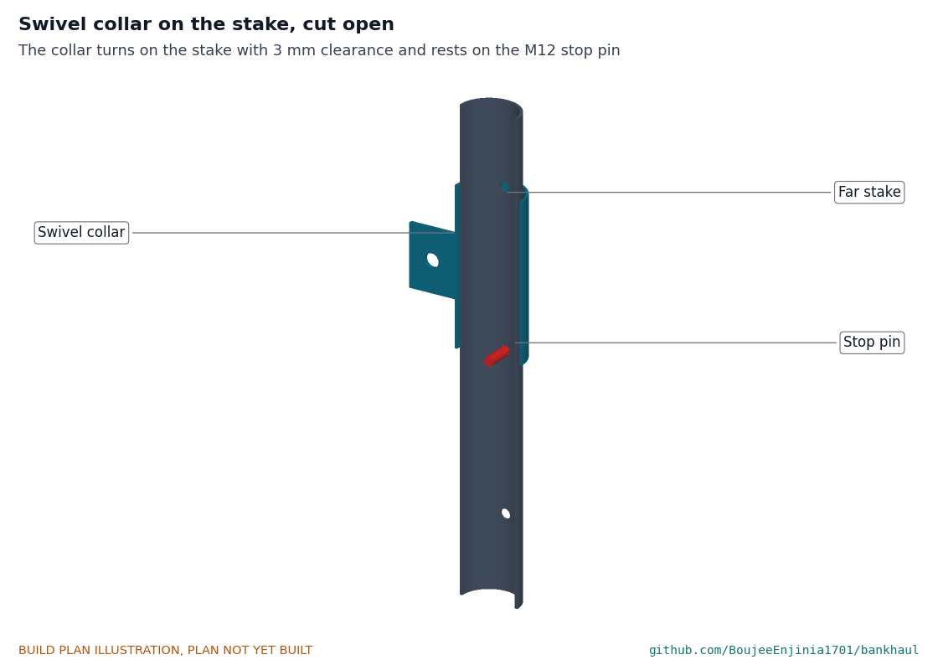
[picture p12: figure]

Figure 6. The collar turns on the stake with about 3 mm clearance all round and rests on the M12 stop pin through the stake.

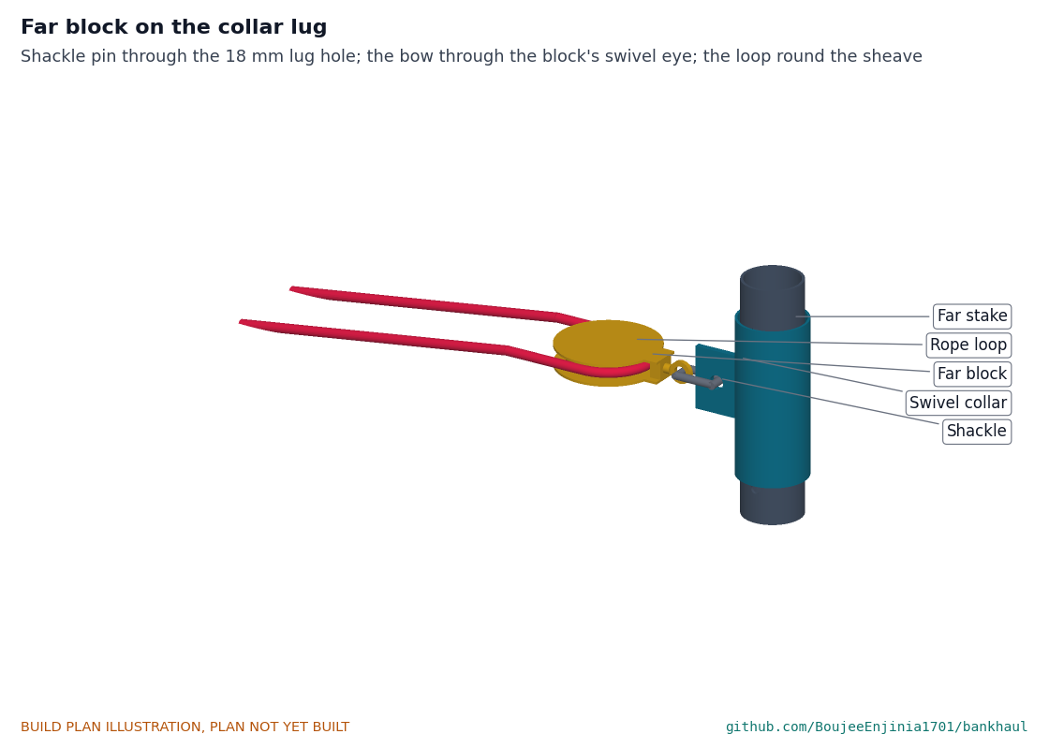
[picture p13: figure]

Figure 7. The far block hangs from the collar lug on a 10 mm shackle; the loop runs round its sheave and back toward the bank.
Check before moving on. The collar spins on an offcut of the stake tube and drops down it under its own weight.

### 3.4 Clearing table

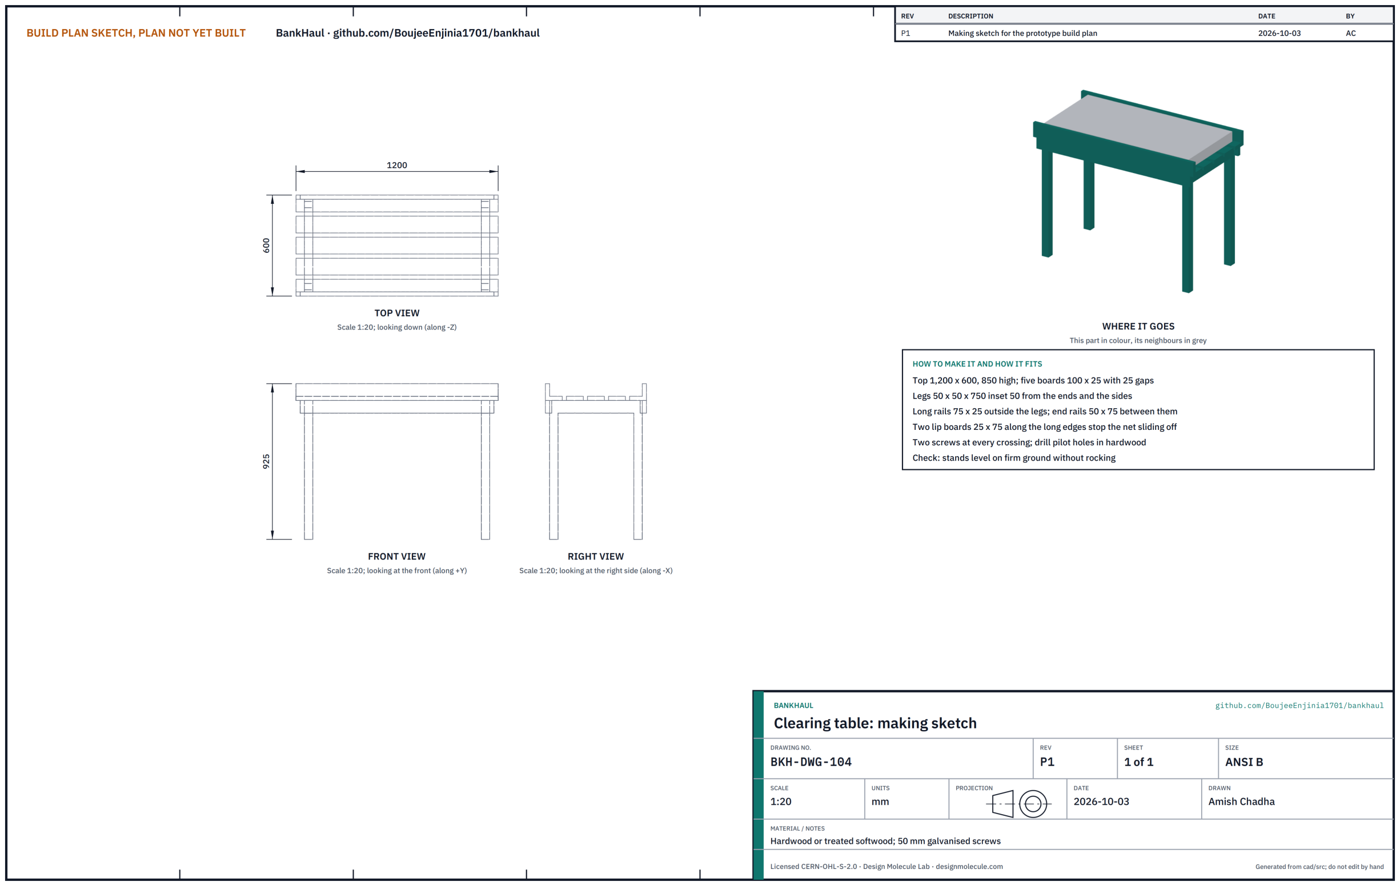
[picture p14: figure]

What it is and what it is made from. A raised table on the bank where the net is stacked and cleared. Hardwood or treated softwood, held with 50 mm galvanised screws; the top is 1,200 by 600 mm and 850 mm high.
How to make it.
Cut four legs 50 by 50 by 750 mm, two long rails 75 by 25 by 1,150 mm, two end rails 50 by 75 by 475 mm, five top boards 100 by 25 by 1,200 mm and two lip boards 25 by 75 by 1,200 mm.
Screw the long rails to the outside of the legs, 50 mm in from each end, and the end rails between them.
Screw the top boards across the rails with 25 mm gaps so water drains.
Screw the lip boards on edge along both long sides.

How it fits the parts next to it. It stands free on the bank, landward of the post and on the side away from the stays. Check before moving on. It stands level on firm ground without rocking.

1.

2.
3.
4.

### 3.5 Back-stays

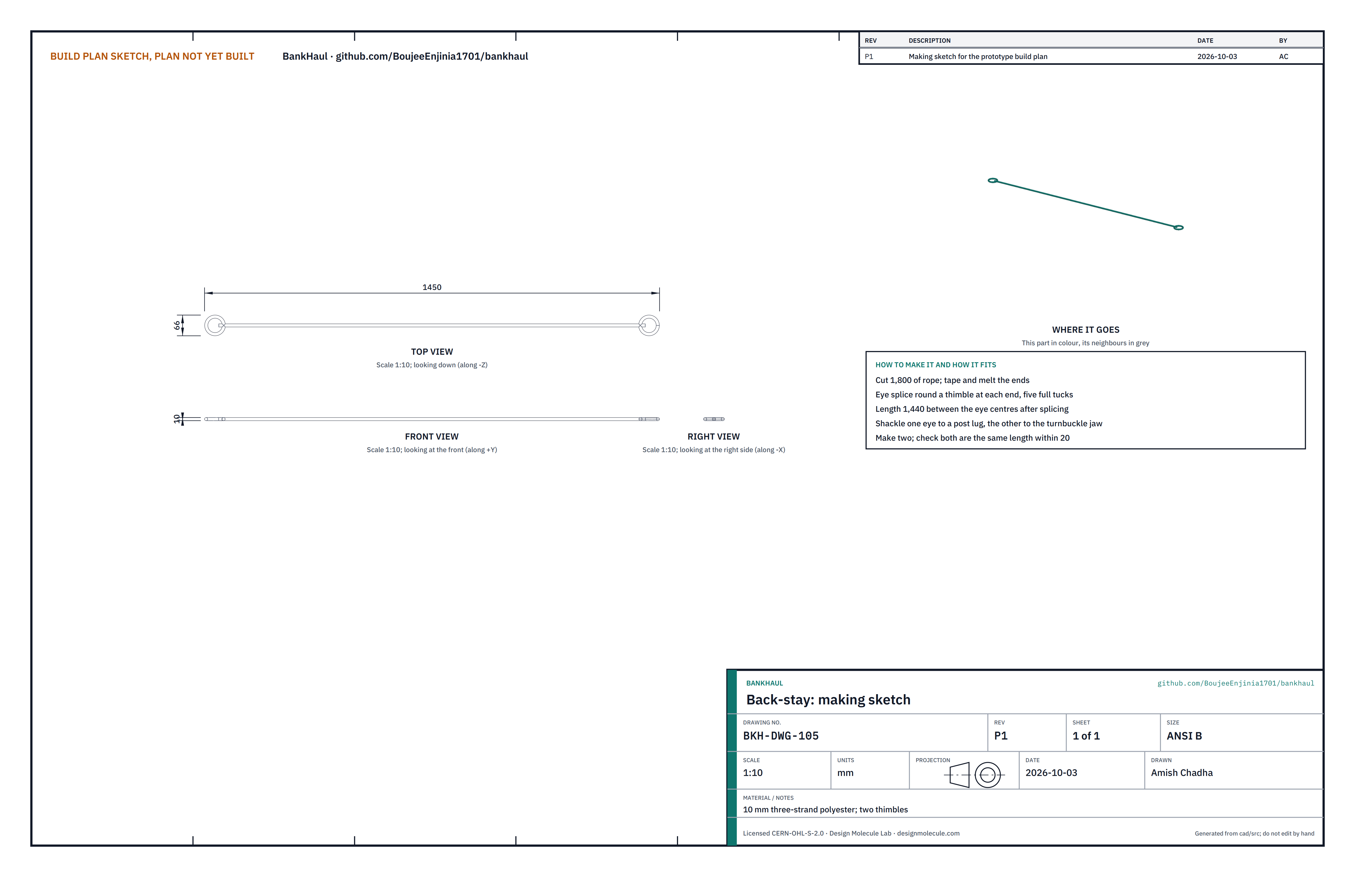
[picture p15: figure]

What it is and what it is made from. Two short ropes that hold the post back. Each is 10 mm three-strand polyester with a thimbled eye splice at each end.
How to make it.
Cut two lengths of 1,800 mm; tape and melt the ends.
Splice an eye round a thimble at each end with five full tucks, so the eye centres are 1,440 mm apart.

How it fits the parts next to it. One eye is shackled to a post lug (Figure 3); the other is shackled to the turnbuckle on the anchor eye.

1.
2.

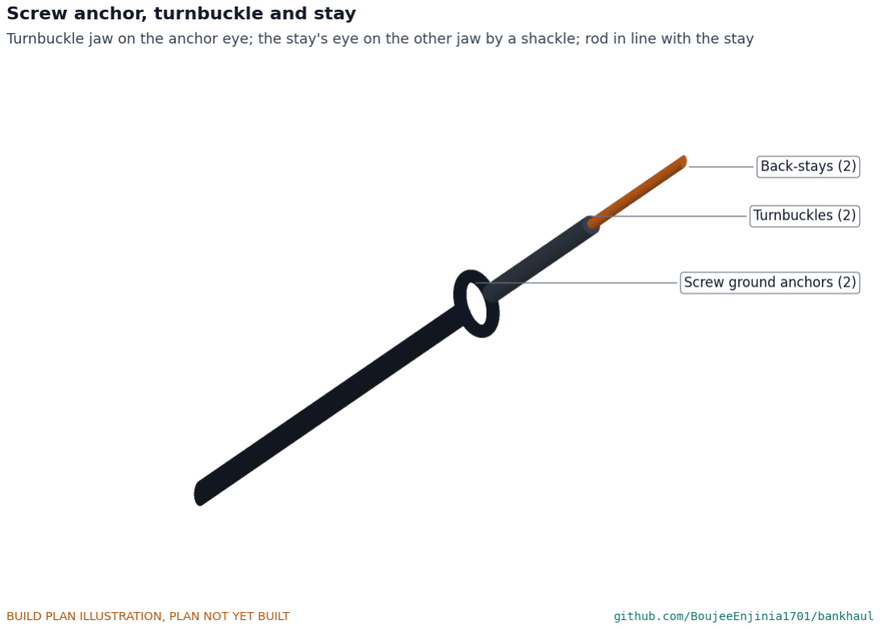
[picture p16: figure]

Figure 8. The turnbuckle's jaw takes the anchor's eye; the stay's eye is shackled to the other jaw. The anchor's rod runs in line with the stay.
Check before moving on. Both stays are the same length within 20 mm.

### 3.6 Rope loop

What it is and what it is made from. The loop that carries the net out and back: two halves of 12 mm floating polysteel rope joined by two eye-to-eye swivels, the swivel rings.
How to make it.
Cut two halves of 55 m from the 120 m coil; tape and melt all ends.
Splice a soft eye, about 80 mm long, round one eye of a swivel ring at one end of each half, with five tucks.
The plain end of each half is tied to the other ring with a round turn and two half hitches when the loop is reeved (step 9), so its length suits the span.

How it fits the parts next to it.

1.
2.
3.

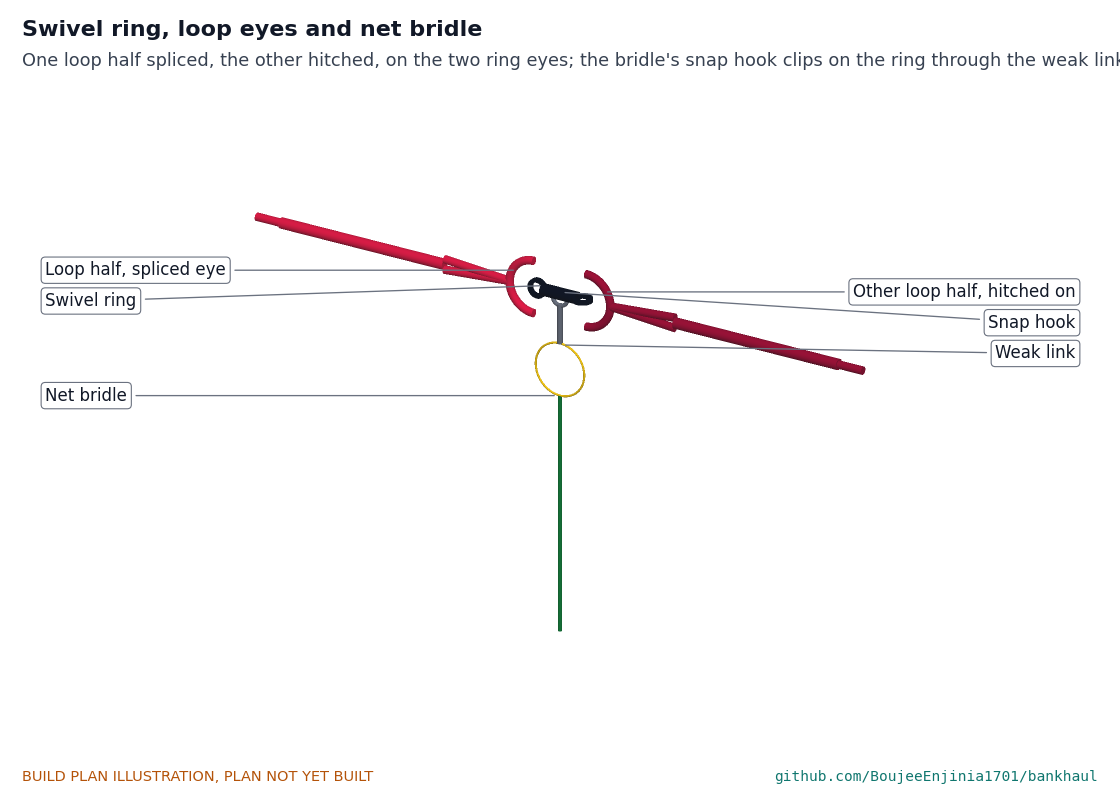
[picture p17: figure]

Figure 9. The two loop halves meet at each swivel ring, one spliced and one hitched. The net bridle's snap hook clips onto ring 1.
Check before moving on. Each ring turns freely under a firm hand pull; each splice has five full tucks.

### 3.7 Net bridles with weak links

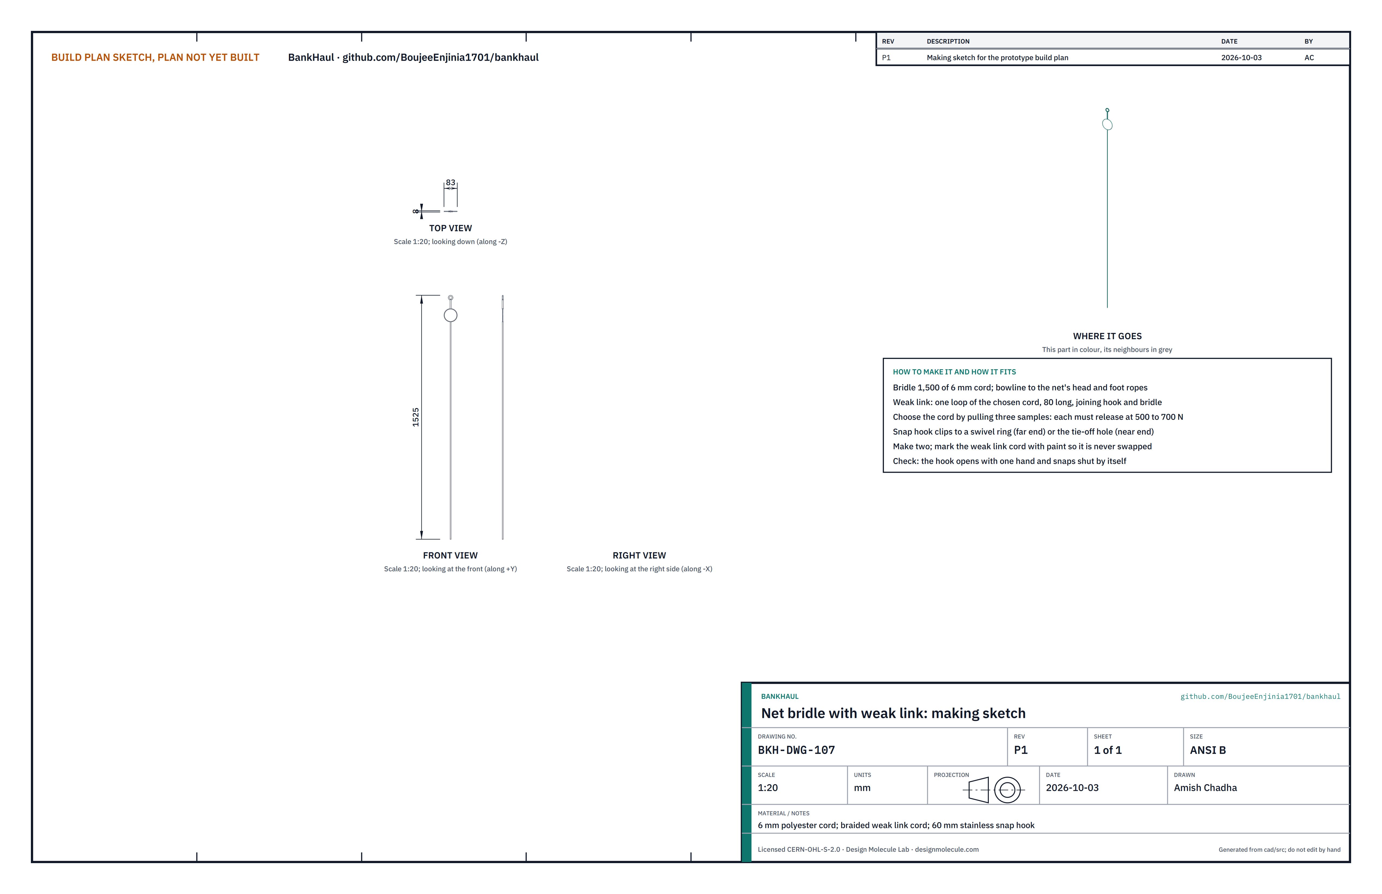
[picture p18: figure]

What it is and what it is made from. One bridle for each end of the net: 1.5 m of 6 mm polyester cord, a weak link of braided cord and a 60 mm stainless snap hook.
How to make it.
Pull three samples of the weak link cord to breaking on a spring scale or the CalRig rig; use the cord only if every sample breaks between 500 and 700 N, as a single loop 80 mm long.
Tie the bridle cord to the head rope and foot rope at the net's end with bowlines.
Join the bridle to the snap hook with one loop of the weak link cord. Mark the link with paint so it is never replaced with stronger cord.

How it fits the parts next to it. The far-end bridle clips onto ring 1 (Figure 9); the near-end bridle clips into the tie-off hole of the cleat bar.
Check before moving on. The hook opens with one hand and snaps shut by itself.

### 3.8 Bought components

Swivel blocks (2). Single sheave, 100 mm sheave for 12 mm rope, swivel eye, working load limit at least 500 kg. The eye and the spacer between the cheeks must sit outside the rope's path round the sheave. Nothing to do to them.
Swivel rings (2). Eye-to-eye swivels, 10 mm, working load limit at least 500 kg, with eyes at least 25 mm inside. Jam cleats (2). V-jam cleats for 10 to 14 mm rope with two 8 mm fixing holes about 60 mm apart. If the hole spacing differs, drill the cleat bar to suit.

1.

2.
3.

•

•
•

Screw ground anchors (2). A single 250 mm helix on a 20 mm galvanised rod, 1.6 m long, with an eye. Turnbuckles (2). Rated M12 jaw-and-jaw, working load limit at least 500 kg.
Shackles (6). Rated 10 mm bow shackles, working load limit at least 750 kg; wire every pin shut (mousing). Stop pin. An M12 by 100 mm stainless bolt with a nyloc nut and two washers, plus a spare.
Stake driving cap (tool). A 300 mm length of 88.9 mm tube with a 10 mm cap plate and two handles, made to fit over the stake top.

### 4. Putting it together

Steps 1 to 5 and 10 are done on the bank; steps 6 to 9 need a boat or a low-water day and two people.

Step 1: Screw in the two ground anchors

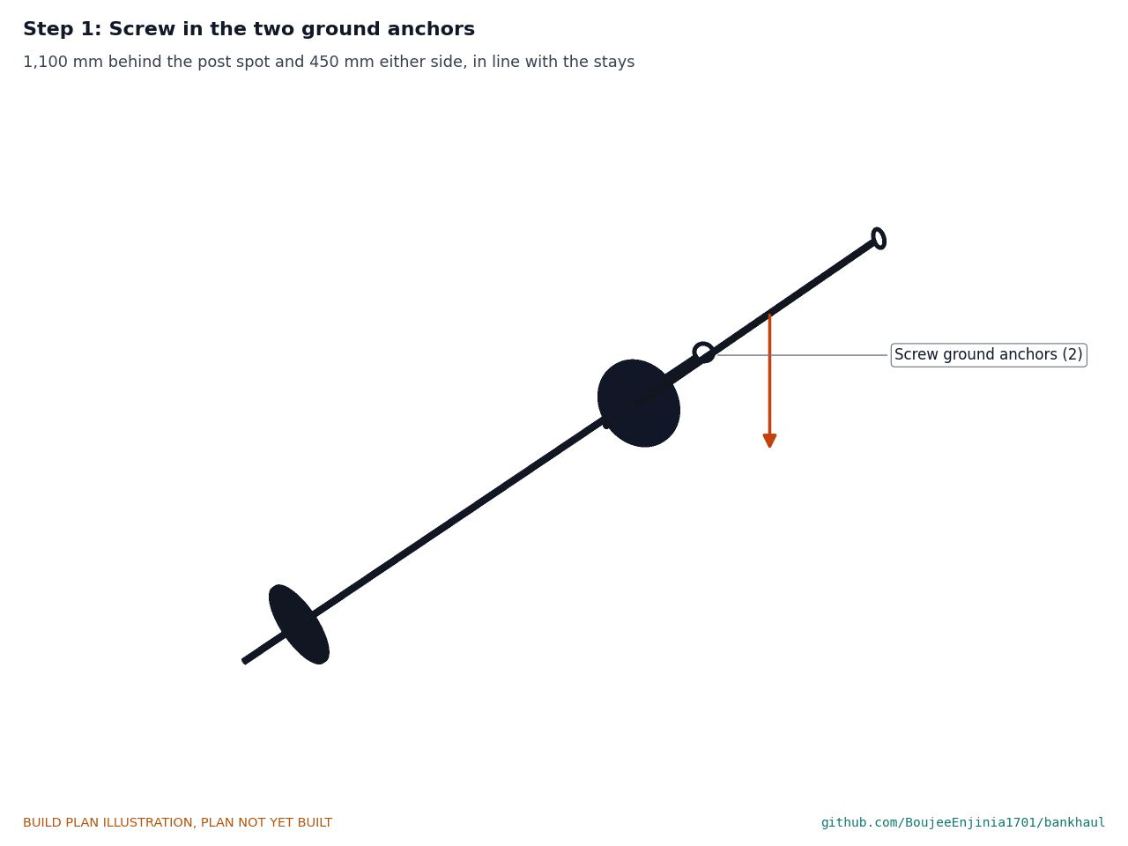
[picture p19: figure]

Mark the post spot at least 6 m back from the water's edge. Mark the two anchor spots 1,100 mm behind it and 450 mm either side of the line to the far stake. Screw each anchor in with a bar through its eye, leaning back toward the post at about 39 degrees from the ground, until the eye is just above the ground.

•
•
•
•
•

Step 2: Stand the post on its spike

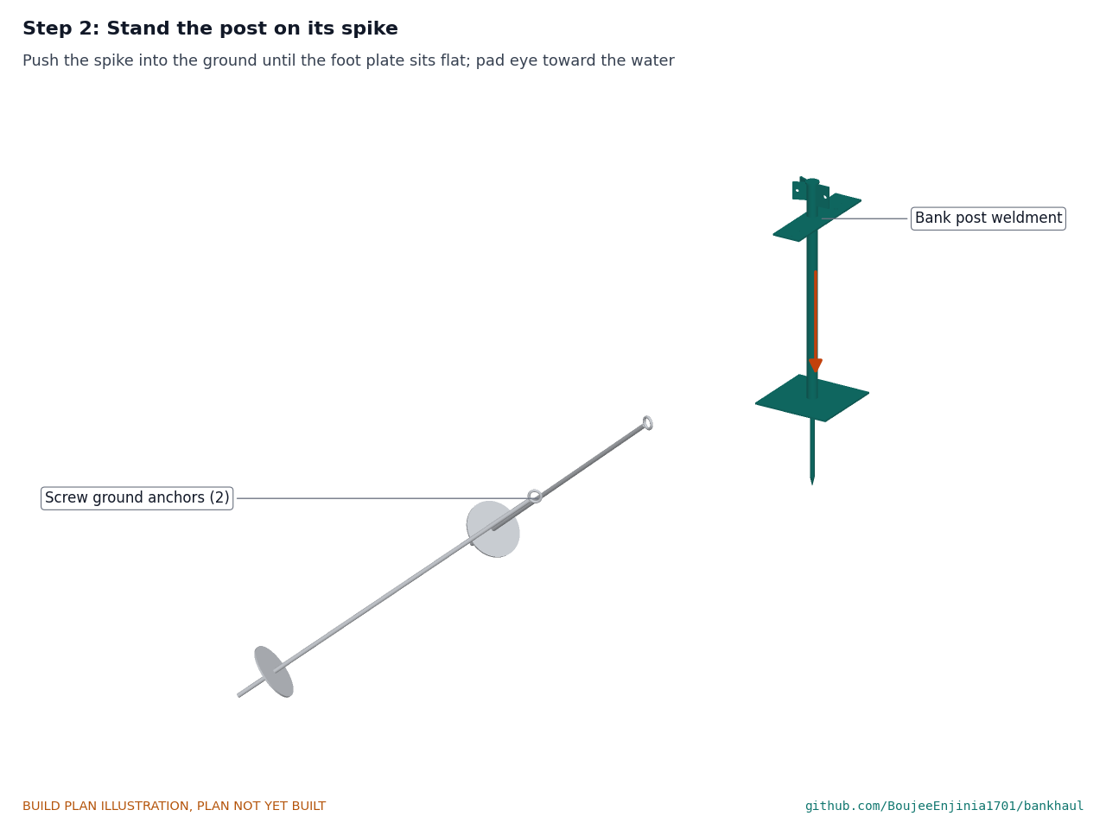
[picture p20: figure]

Push the spike in until the foot plate sits flat, pad eye toward the water.

Step 3: Fit the back-stays

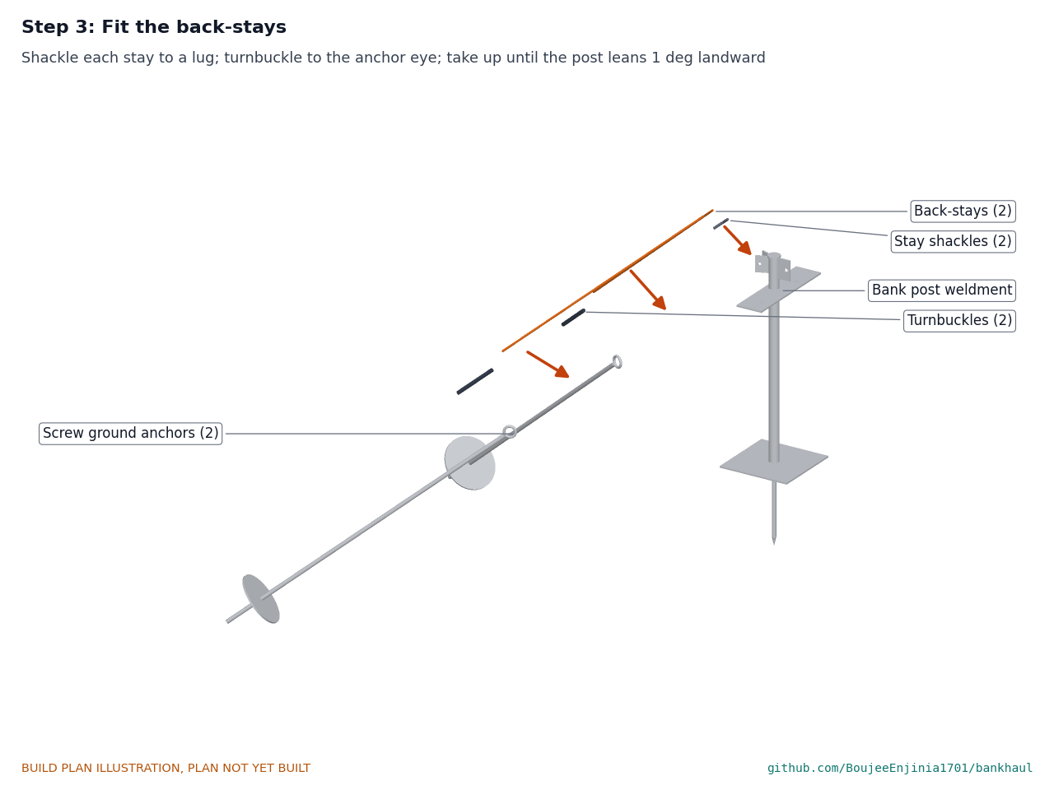
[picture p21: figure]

Shackle each stay to a post lug and to a turnbuckle on an anchor eye. Take up both turnbuckles evenly until the post leans about 1 degree away from the water. Wire the shackle pins.

Step 4: Bolt on the jam cleats

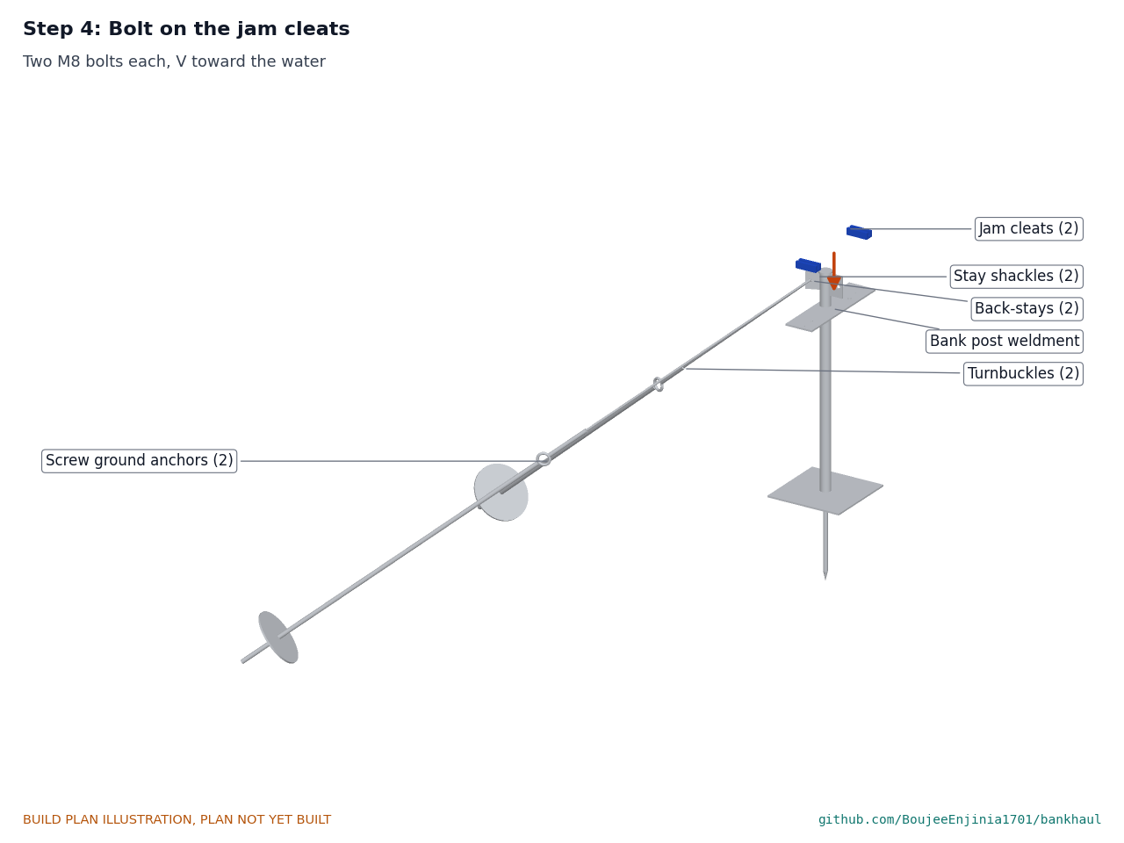
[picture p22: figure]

Two M8 bolts each, with the V pointing toward the water.

Step 5: Hang the near block

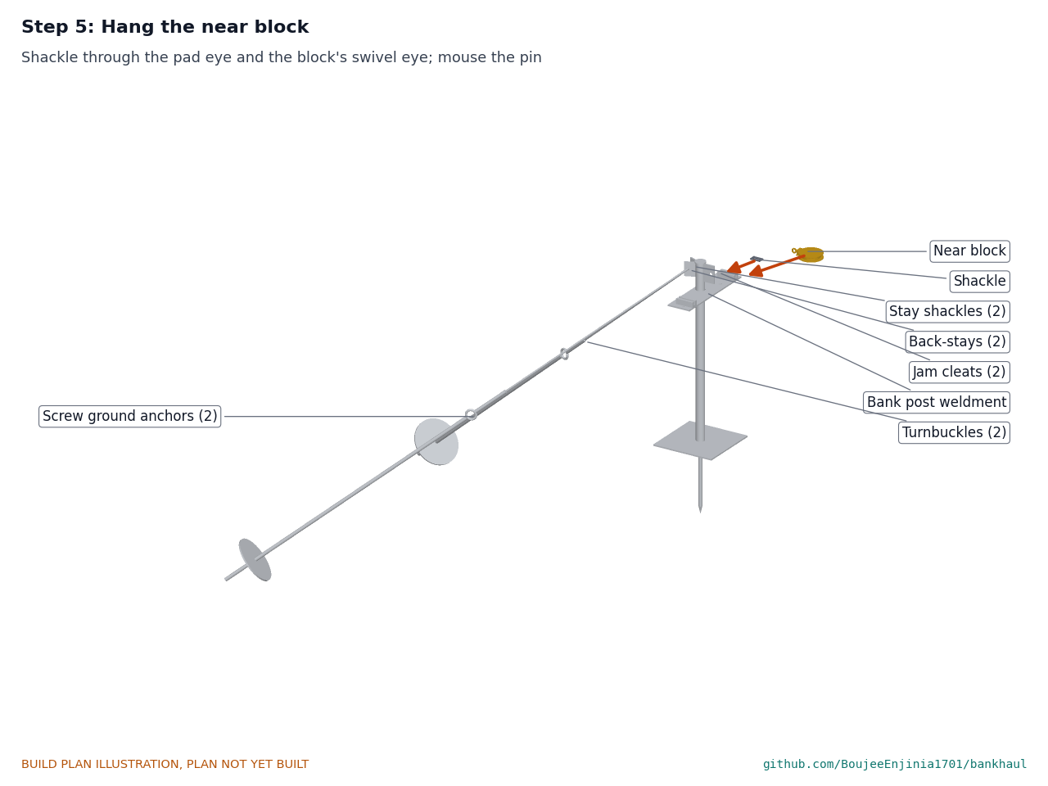
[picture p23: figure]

Shackle through the pad eye and the block's swivel eye; wire the pin.

Step 6: Drive the far stake from a boat

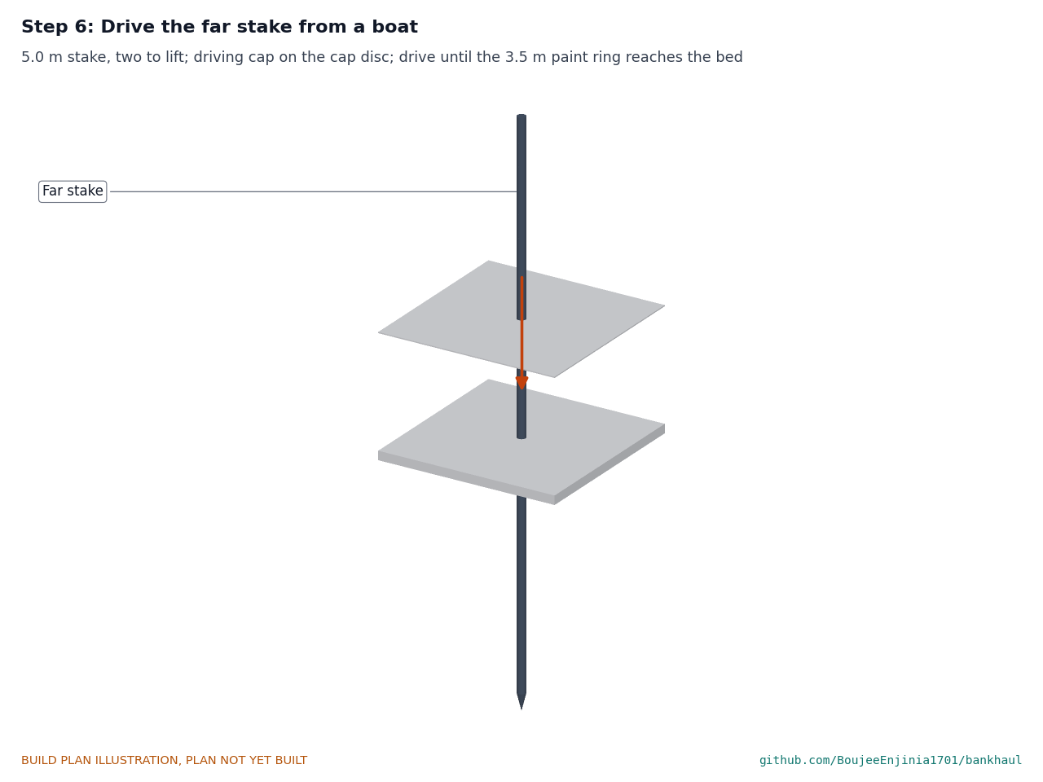
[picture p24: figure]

From a boat held on two anchors, or standing on the dry bed at low water, stand the stake on its point 30 m from the post on the line between the anchors. The stake is 5.0 m long, so two people lift it upright together. In soft mud it sinks part of the way under its own weight; push and twist it down as far as it will go. Then fit the driving cap and drive with a post driver or sledge until the paint ring, 3.5 m above the point, reaches the bed. Keep it upright within 2 degrees.

Step 7: Fit the stop pin and the collar

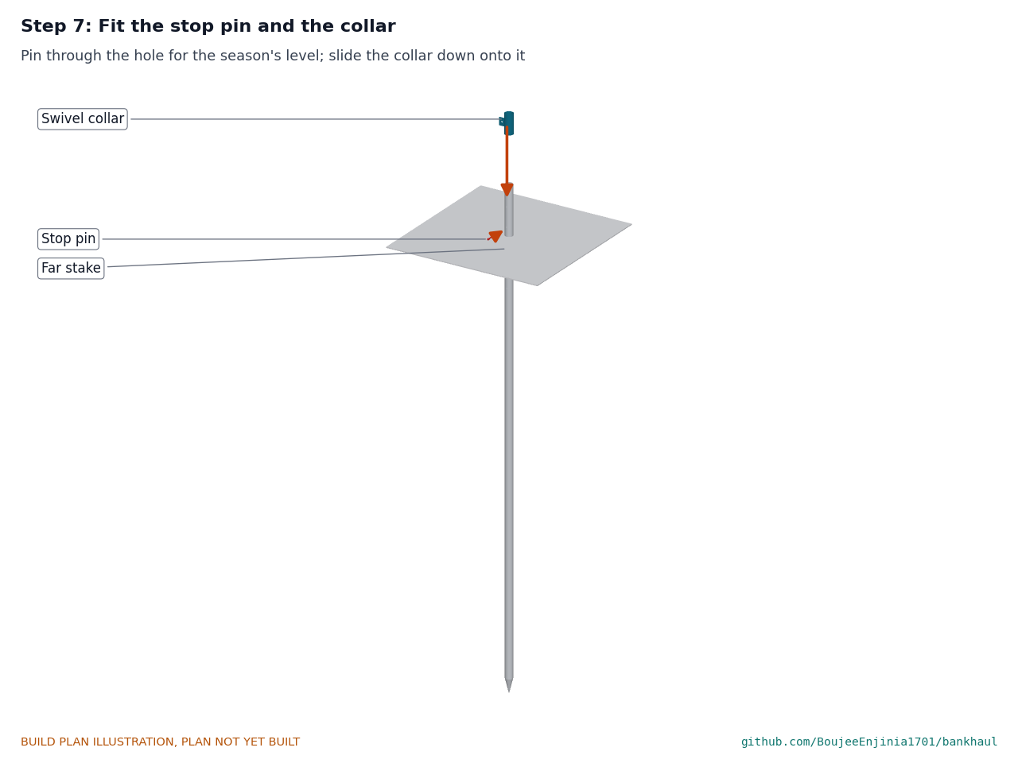
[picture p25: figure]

Choose the hole that puts the far block about 200 mm above the day's water. Fit the bolt and nyloc nut through it, then slide the collar down the stake onto the pin.

Step 8: Hang the far block

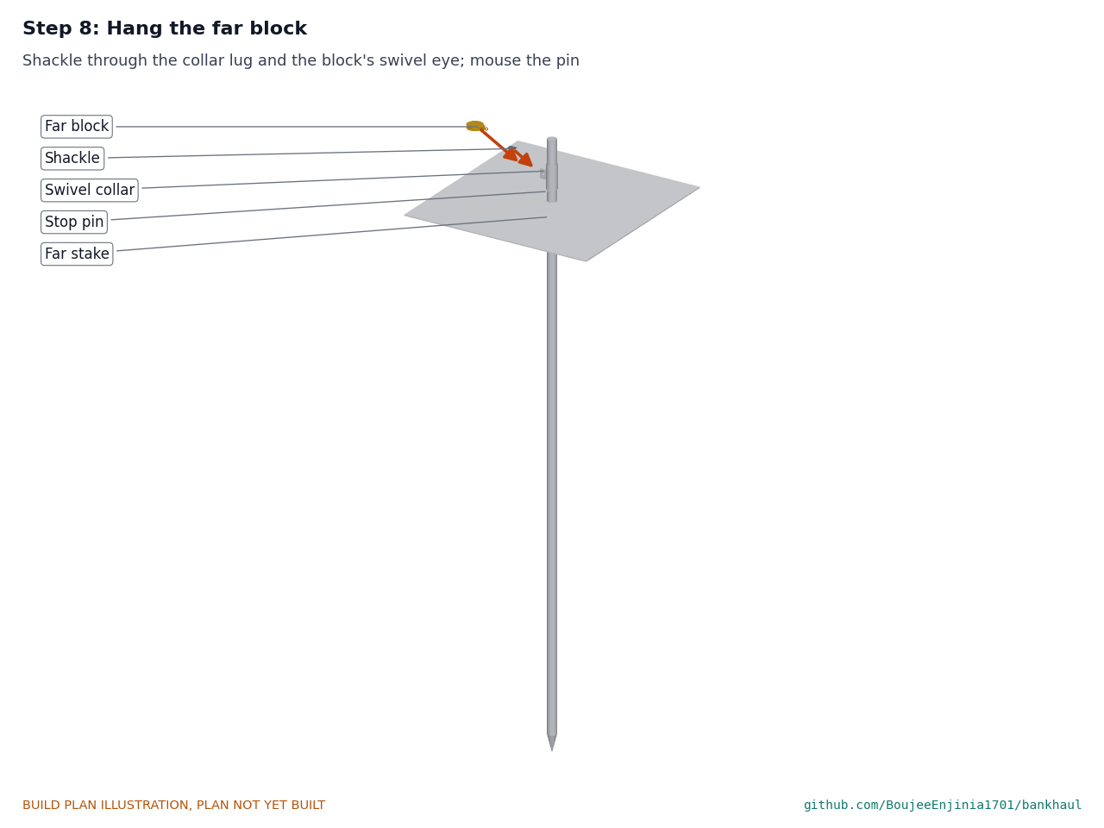
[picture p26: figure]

Shackle through the collar lug and the block's swivel eye; wire the pin.

Step 9: Reeve the loop and join the halves

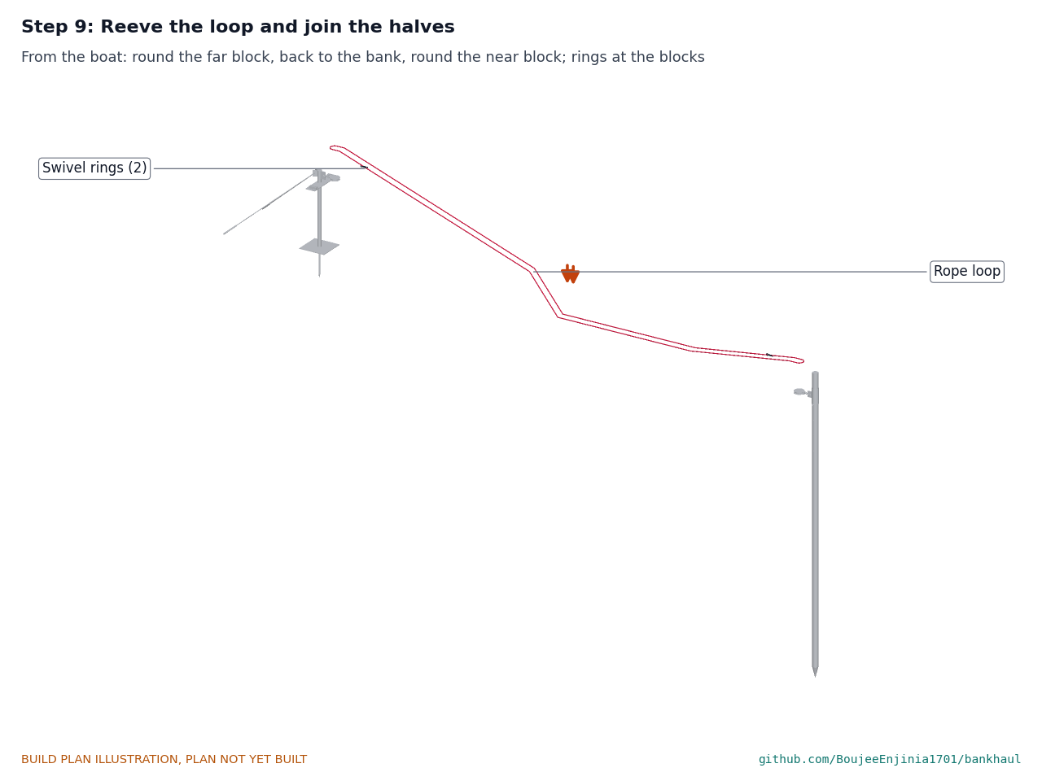
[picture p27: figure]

From the boat, run the first half from the bank round the far block and back to the bank; run the second half round the near block. Tie each plain end to the other half's ring with a round turn and two half hitches, so that ring 1 lies about 450 mm in front of the near block when ring 2 lies about 450 mm short of the far block and the loop is snug but not tight. Coil and seize any surplus at the ring.

Step 10: Set up the clearing table


Landward of the post on the side away from the stays, level on firm ground.

Step 11: Clip the net to ring 1


Stack the net on the table, far end on top. Clip the far-end bridle to ring 1 and the near-end bridle to the tie-off hole. The station is now ready for the first checks.

### 5. First checks

Check | Requirement How | Pass when

Post and
stays
| R4 | Pull the near block toward the water with a spring scale or come-along to 3 kN, from behind a screen | No visible movement of post, anchors or stays; no change at the anchor eyes
Far stake | R5 | Pull the collar toward the bank to 1.5 kN from the boat | The stake moves less than 25 mm at the collar and springs back
Weak link | R10 | Pull three links from the batch | Each releases between 500 and 700 N
Loop runs | R2 | Pull each leg by hand over a full cycle | The loop runs freely; no ring reaches a block; nothing rubs a cheek
Set and haul | R1, R3 | Set and haul a 30 m net from the bank with a spring scale on the hauling end | Nobody enters the water; peak pull under 250 N
Timing | R6 | Time a haul and reset | Under 10 minutes without clearing fish
Working spot | R11 | Measure from where the fisher stands to the water's edge | 5 m or more

### 6. Safety stops

Before driving the far stake: two people, a boat held on two anchors or a dry bed, a lookout on the water, and the local wildlife authority's advice on the site. Never wade. The 5.0 m stake is lifted upright by two people and never driven from a standing position higher than the boat's seat.
Before the first load on the bank station: stays tensioned, all shackle pins wired, anchors in line with the stays, and nobody in line with a stay or in the bight of the loop.
Before the first pull test: the person pulling stands behind a screen or to the side of the line; the load is applied slowly and held, never jerked.
Before the first net is set: both weak links tested from the same batch and marked; the jam cleats hold a leg against a firm pull.
Before each use: the loop, splices, stays, shackles and blocks are looked over; any cut, melted or worn rope is replaced.
When floods are expected: the loop is taken out of the water and the net is not set.

### 7. Tools, skills and workspace

Welding and drilling: MIG or stick welder for 3 to 8 mm steel, angle grinder, pillar drill or magnetic drill to 49 mm, a flat table to square the post. A competent welder.
Woodwork: saw, drill and screwdriver.
Rope work: splicing fid, sharp knife, tape and lighter; someone who can make an eye splice in three-strand rope. Site: two people, a tommy bar for the screw anchors, a post driver or 5 kg sledge with the driving cap, a tape measure, a boat that two people can work from, life jackets.
Testing: a spring scale or load cell to 5 kN and a come-along, or the CalRig proof-load rig.

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
### 8. Where the numbers come from

Model and constructability checks: | cad/src/model.py
General arrangements: | cad/drawings/BKH-DWG-001 | (bank station), | BKH-DWG-002 | (far end) and | BKH-DWG-003
(layout)
Making sketches: | cad/drawings/BKH-DWG-101 | to | BKH-DWG-107 ; pictures: | cad/src/build_plan_media.py
Calculations: | docs/04-calcs/01-sizing.md | and | docs/04-calcs/sizing.py | (BKH-CAL-001)
Parts: | bom/bom.csv
Design changes: | docs/decisions/0002-design-for-construction.md | (BKH-DDR-002) and | docs/decisions/
0003-amish-requirement-decisions.md | (BKH-DDR-003)

•
•

•
•
•
•

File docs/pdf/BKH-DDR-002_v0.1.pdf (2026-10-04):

B A N K H A U L · D E S I G N D E C I S I O N R E C O R D

# BankHaul design for construction

### Design Molecule Lab · designmolecule.com

D O C U M E N T CO N T RO L

Document ID | BKH-DDR-002 | Version | 0.1
Status | Draft | Date | 2026-10-03
Author | Amish Chadha | License | CERN-OHL-S-2.0
Project TRL | TRL 3 | Proof of concept
Repository | github.com/BoujeeEnjinia1701/bankhaul
Source | docs/decisions/0002-design-for-construction.md @ uncommitted

R EV I S I O N H I STO RY

Version | Date | Author | Change
0.1 | 2026-10-03 | Amish Chadha

Constructability review and changes that make the design buildable, decided under Amish's pre-approvals of 2026-10-03

D R A F T · N O T F O R F A B R I C A T I O N

# 0002: Design for construction

Date: 2026-10-03
Status: accepted

## Context

STANDARDS section 18 asks for every part to be makeable by its stated process and to fit and fasten to its neighbours (Amish, 2026-09-30: "fix the design assumptions to match and be physically feasible"). The TRL 2 concept (BKH-PRC-001, BKH-DDR-001) was reviewed part by part in cad/src/model.py : how each part is made, how it joins each neighbour, and build123d checks for overlapping parts and for parts that do not touch what holds them. The checks now report no overlaps and no floating parts; the only contacts allowed are a pin or rope eye passing through the hole or eye it is fitted to. Amish pre-approved every recommendation on 2026-10-03: "start with the first 14 repos from the list of 29 projects. I pre-approve the batch runs along with any recommendations you come up with. I also accept any cost overruns or variations from the assumed scope cost." and "Proceed with the remaining 15 scaffolds". No change alters what BankHaul does or its pitch; the safety-related changes all take the conservative side.

## Options considered

For each problem the simplest physically sound fix was chosen; the alternatives are noted in Table 1.

## Decision

Table 1. Changes made for construction.

•
•

# | Part | Problem found | Change | Why

1 | Bank anchor post | The concept's "screw or deadman anchor carrying the pulley at waist height" put a 3 kN pull 1 m above soft soil, which a post alone cannot resist | A 48.3 x 3.2 mm tube welded to a 350 mm foot plate with a 400 mm ground spike, held back by two splayed stays to two screw anchors | The post only carries compression (2.6 kN, buckling factor 93); foot bearing factor 2.3
2 | Near block mounting | No fixing for the pulley was defined | An 8 mm pad eye with an 18 mm hole at 950 mm; the bought swivel block hangs on a 10 mm shackle and lines up with the loop by itself | Commodity parts; pad eye shear 34 MPa at 6 kN
3 | Stay
attachment
No stay fixing | Two 8 mm lugs with 15 mm holes at
960 mm, splayed 22 degrees either side of straight back, each with a shackle

The stays meet the post
square to the lug, so the
shackle is not side-loaded

4 Cleat and
brake

A cleat on a round post has no flat face to bolt to

A 130 x 500 x 8 mm cleat bar with a 48.9 mm hole, slipped over the post and welded all round at 850 mm; two jam cleats on M8 bolts and a 15 mm tie-off hole

Gives the bought cleats a
flat seat beside each leg

5 Screw anchors A vertical anchor pulled at 39 degrees bends its rod in soft soil

Each anchor is screwed in line with its stay, so the rod is in tension; helix 0.9 m deep

Anchor factor 2.13 on the
stay tension (BKH-CAL-001, D)
6 | Far stake | A light stake would yield in bending at the R5 load

A 76.1 x 3.6 mm S355 tube, 2.5 m in the bed; a 60.3 mm tube would reach about 250 MPa at 1.5 kN

Bending factor 2.4 on
yield; capacity factor 2.46 in soft mud
7 | Stake ends | An open tube cannot be driven without splitting its top

A welded four-plate cone point and a 6 mm cap disc; a separate driving cap tool (BOM 17)

Drivable from a boat with a post driver or sledge

8 | Far block mounting and swivel | The concept's "far pulley and swivel" had no defined way to turn or follow the water level

An 88.9 x 3.2 mm collar that turns on the stake with 3 mm clearance and rests on an M12 stop pin; five pin holes at 200 mm pitch

The collar is the swivel; the pin follows the season's
level
9 | Blocks | The rope wrap must not touch the block's spacer or cheeks

Blocks specified with the eye and spacer outside the rope wrap (cheeks 65 mm radius over a 56 mm rope circle); the loop leaves each block level for about 100 mm

Checked in the model: no
rope contact with cheeks
or spacer
10 Loop | An endless spliced loop cannot change length as the shoreline moves

Two halves of 55 m, each with an eye splice on one swivel ring and a round turn and two half hitches on the other; surplus coiled at the ring

Spans from 30 to 50 m
with the same rope;
nothing but the sheave-side rope passes a block
11 Net clips | "Quick clips" were not defined and had no load limit

A bridle at each net end with a calibrated weak link and a 60 mm

R10; the link stays out of the hauling load

# | Part | Problem found | Change | Why

| | | stainless snap hook; far end to ring 1, near end to the tie-off hole
12 Clearing table | A flat table lets a wet net slide off | Slatted top 1,200 x 600 mm at 850
| | | mm with two lip boards; placed landward on the +Y side, clear of the stays | Net stays on the table; the table is at least 5 m from the water

## Consequences

cad/src/model.py , the drawings BKH-DWG-001 to 003 (Rev P2), the concept media and the build plan pictures are regenerated from the constructable model.
Bill of materials: the cleat bar, stays, turnbuckles, shackles, stop pin, fixings, rope work kit and driving cap are added. Station parts: USD 382.
project.yaml | is set to | design_state: constructable .

•

•

•

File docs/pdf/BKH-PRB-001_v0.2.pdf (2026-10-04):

B A N K H A U L · P R O B L E M S TAT E M E N T

# BankHaul problem statement

Design Molecule Lab · designmolecule.com

D O C U M E N T CO N T RO L

Document ID | BKH-PRB-001 | Version | 0.2
Status | Draft | Date | 2026-10-03
Author | Amish Chadha | License | CERN-OHL-S-2.0
Project TRL | TRL 3 | Proof of concept
Repository | github.com/BoujeeEnjinia1701/bankhaul
Source | docs/01-problem.md @ uncommitted

R EV I S I O N H I STO RY

Version | Date | Author | Change
0.2 | 2026-10-03 | Amish Chadha | TRL 2 update; first co-design candidate, safety note, open questions routed to the decisions register
0.1 | 2026-09-30 | Amish Chadha | Initial scaffold

D R A F T · N O T F O R F A B R I C A T I O N

## BankHaul problem statement

Small-scale fishers often work gillnets and traps close to shore, in the shallows or from canoes. In crocodile water, fishing is the activity during which most recorded attacks happen.

### The problem

Attack studies across Africa and Asia point to the same activity. At Kariba, fishing accounted for 58 % of sampled attacks, ahead of domestic chores at 27 % (Oryx). (https://www.cambridge.org/core/journals/oryx/article/negative-humancrocodile-interactions-in-kariba-zimbabwe-data-to-support-potential-mitigation-strategies/E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) In northern Mozambique victims were collecting water, bathing, wading across rivers, falling from canoes and fishing with gill nets, rod and line, or nets and traps (Oryx, 2010). (https://www.cambridge.org/core/journals/oryx/article/humanwildlife-conflict-in-mozambique-a-national-perspective-with-emphasis-on-wildlife-attacks-on-humans/4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) In Timor-Leste, fishing and crabbing account for about 80 % of reported attacks (ABC News, 2025). (https://www.abc.net.au/news/2025-01-09/crocodile-management-nt-lessons-for-timor-leste/104522096)
The main engineered answer so far is the crocodile exclusion enclosure, a fenced area at the water's edge. Enclosures work well for bathing, collecting water and washing, but are far less useful for fishers (CrocAttack). (https://crocattack.org/crocodile-exclusion-enclosures-cees/) The Uganda Wildlife Authority built enclosures on Yuwe Island in Lake Victoria in 2019 after about 10 deaths, mainly to protect water collection (PML Daily, 2019). (https://www.pmldaily.com/news/2019/10/yuwe-island-gets-crocodile-exclusion-enclosures.html) Commercial setnet fishers already use running lines, a pulley system from shore to deeper water, to moor skiffs (Northwest Setnetters), (https://www.northwestsetnetters.org/what-we-do) but that practice assumes boats and has not been packaged as a no-wade method for subsistence fishers.

### Users and context

User | Need | Context
Subsistence and small-scale fishers | Set, check and haul nets from the bank at night and at dawn | Lake shores, river banks, estuaries and mangrove edges
Fisher associations and village committees | A shared set of stations at known hotspots | Landing sites and fishing camps
Wildlife authorities | A mitigation measure they can promote alongside patrols and closures | Human-wildlife conflict programmes
NGOs and livelihood programmes | A low-cost, locally made kit | Households in conflict hotspots

### Operating environment

Fresh or brackish water, still to slow flowing; banks from firm to soft mud and sand.
Working span from bank anchor to offshore pulley of 10 to 50 m (33 to 164 ft) (target).
Water depth at the offshore pulley up to about 3 m (10 ft) for a stake, deeper with a float (estimate). Seasonal level change of the shoreline; banks move as water rises and falls.
Night and dawn use, sun, UV and floating debris; hippos and crocodiles present.

### Constraints

Prototype budget ceiling USD 1,800 for all prototypes and test rigs.
No powered hauler; hand pull only (IP screen design-around).

•
•
•
•
•

•
•

Parts cost target below USD 80 per station (target), using commodity rope, pulleys and anchors.
Installable without anyone standing in crocodile water; the offshore point is placed from a boat, at low water, or by a trained team with protection.
Open hardware under CERN-OHL-S-2.0.

### Out of scope

Crocodile deterrence, capture or culling.
Protection for bathing and water collection, already covered by exclusion enclosures. Motorised line haulers or winches.
Changes to fishing regulations or zoning.

### Prior work

Prior work | What it does | Gap for these users | Source
Crocodile exclusion enclosures (CEEs) | Metal or wire fenced areas at the water's edge for bathing, washing and collecting water | Far less useful for fishers, who need to reach water beyond the fence | link (https://crocattack.org/crocodile-exclusion-enclosures-cees/)

Yuwe Island enclosures, Uganda
Wildlife Authority (2019)

Crocodile exclusion enclosure for residents who depend on Lake Victoria for water

Protects a fixed water point, not fishing | link (https://www.pmldaily.com/news/2019/10/yuwe-island-gets-crocodile-exclusion-enclosures.html)
Setnet running lines | A pulley line from shore to deeper water used by commercial setnetters to moor skiffs

Assumes boats and crew; not
documented as a no-wade method for subsistence nets

link (https://www.northwestsetnetters.org/what-we-do)

EP1429601B1, device for
hauling a fishing line (expired 2022)

A hydraulic motorised pulley and capstan line hauler

Powered and boat-mounted; BankHaul stays manual and bank-based

link (https://patents.google.com/patent/EP1429601B1/en)

### Co-design

First candidate to approach (not agreed): the Lake Kariba research group behind the Oryx study (Matanzima,
Marowa and Nhiwatiwa), together with an inshore fishing cooperative on the Zimbabwean shore of the lake, because the researchers hold attack locations and times and can site a trial station where attacks happen (BKH-DDR-001, item 10).
Checklist for the co-design work:
[ ] Confirm the net types, lengths and depths used at the trial site.
[ ] Map the bank, bed and water level over a season at two candidate stations.
[ ] Agree who places and inspects the far stake, and from which boat.
[ ] Agree the safety briefing with the local wildlife authority.

The original brief: a fisher association in a documented attack hotspot, working with the wildlife authority or a human-wildlife conflict researcher who already holds local attack data, so the station is sited where attacks happen and tested with the nets people actually use.

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
### Safety

Safety: BankHaul is a rope system worked beside crocodile water. It reduces time in the water; it does not protect anyone from a crocodile that leaves the water. Placing the far stake is the most dangerous step and is done from a boat or at low water, never by wading. A loaded rope can snap back, and a net seized by a large animal can pull hard on the loop: the design limits that pull with a weak link, keeps the fisher at least 5 m from the water and never ties the loop to anyone. BankHaul is published as an open engineering reference, not certified equipment.

### Open questions

The questions below are answered, or routed to the design decisions register ( docs/06-design-decisions.md ), at TRL 3.
How can the offshore stake or float be placed safely where no boat is available?
Does a moving loop disturb fish or crocodiles more than a static net?
Which net types (gillnet, seine, traps) suit the loop, and which do not?
Will fishers use shared stations, or does each household need its own?
How does anchor pull-out behave in soft, saturated beds over a season?

•
•
•
•
•

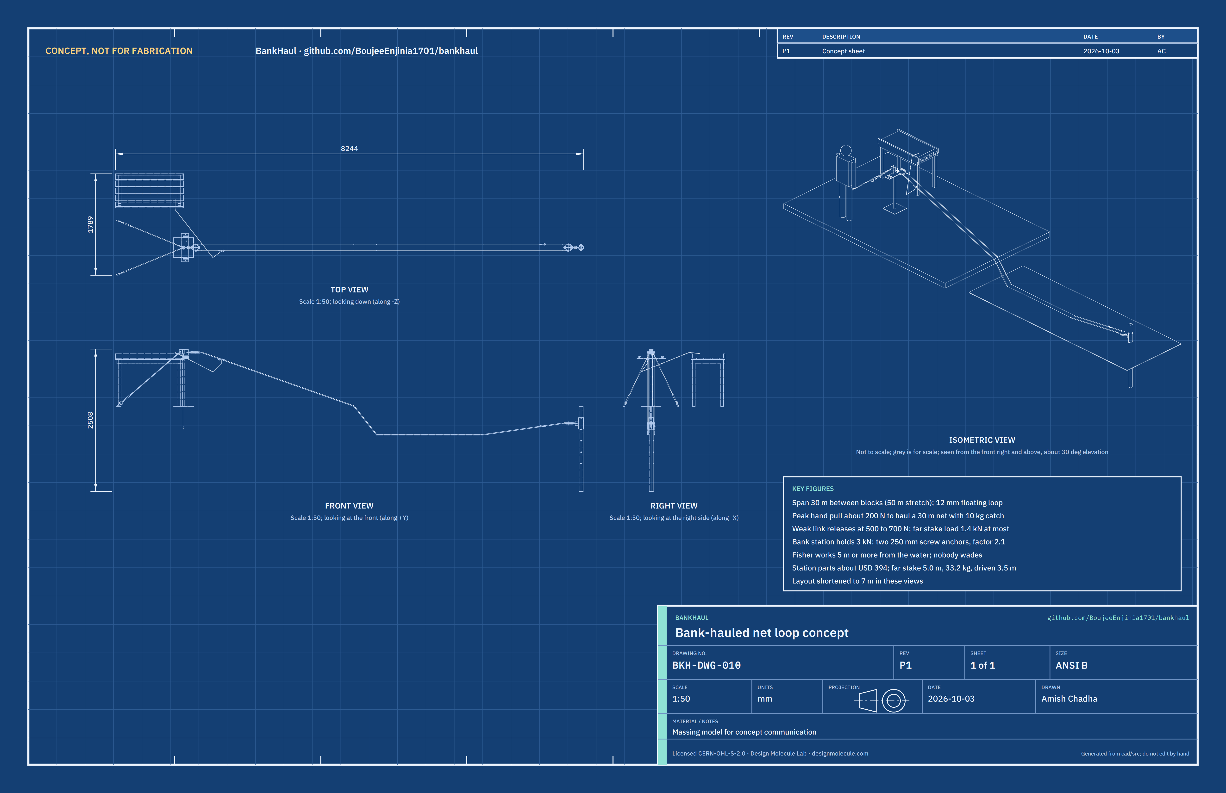
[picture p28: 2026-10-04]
media/concept-blueprint.png

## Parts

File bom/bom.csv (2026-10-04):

item | qty | spec | supplier | unit_cost_usd | make_buy | notes
1 Bank post weldment | 1 | Steel tube 48.3 x 3.2 mm (S235 or S355) 992 mm long; foot plate 350 x 350 x 8 mm; ground spike from 20 mm round bar 400 mm long with a ground point; cap disc 60 mm from 8 mm plate; pad eye 8 mm plate 84 x 100 mm with an 18 mm hole; two stay lugs 8 mm plate 84 x 80 mm with 15 mm holes; cleat bar 130 x 500 x 8 mm flat with a 48.9 mm hole, four 9 mm holes and a 15 mm tie-off hole; zinc-rich paint | Local steel stockholder | 32.00 | make | Indicative material price; 17.2 kg from cad/src/model.py; MIG or 2.5 mm stick welds
2 Far stake | 1 | Steel tube 76.1 x 3.6 mm (S355, EN 10219) 4,850 mm long; welded cone point 150 mm long from 4 mm plate; 6 mm cap disc; five 12.5 mm cross holes at 200 mm pitch for the stop pin; zinc-rich paint | Local steel stockholder | 60.00 | make | Indicative: same tube price per metre as before (about USD 12 a metre), 1.0 m more for USD 12; 33.2 kg; driven 3.5 m into the bed from a boat (BKH-CAL-001 E; BKH-DDR-003)
3 Swivel collar | 1 | Steel tube 88.9 x 3.2 mm, 200 mm long, turns freely on the stake; lug 8 mm plate 60 x 80 mm with an 18 mm hole, welded on | Local steel stockholder | 8.00 | make | Indicative; 1.6 kg
4 Clearing table | 1 | Hardwood or treated softwood: four legs 50 x 50 x 750 mm; two long rails 75 x 25 x 1,150 mm; two end rails 50 x 75 x 475 mm; five top boards 100 x 25 x 1,200 mm with 25 mm gaps; two lip boards 25 x 75 x 1,200 mm; 50 mm galvanised screws | Local timber yard | 35.00 | make | Indicative; 26.4 kg; top 850 mm high
5 Back-stays | 2 | 10 mm three-strand polyester rope, 1.8 m each with a thimbled eye splice at each end (minimum breaking strength 22 kN) | Chandlery or fishing supplier | 3.50 | make | Made from bought rope; 4 m bought for two
6 Rope loop | 1 | 12 mm floating polypropylene and polyethylene blend rope (polysteel), UV stabilised, minimum breaking strength 20 kN; 120 m coil cut into two halves of 55 m with an eye splice at one end of each, 10 m spare | Fishing supplier or chandlery | 54.00 | make | Made from bought rope; the loop for a 30 m span uses about 61 m; halves cut long so the span can grow to 50 m
7 Net bridles with weak links | 2 | 6 mm polyester cord bridle 1.5 m; weak link of braided cord calibrated to release at 500 to 700 N (about 1.5 mm braided polyester, to be chosen by test); stainless snap hook 60 mm | Fishing supplier | 3.00 | make | One at each end of the net; cord for test samples included
8 Swivel blocks | 2 | Single-sheave block with swivel eye, 100 mm sheave for 12 mm rope, galvanised or stainless cheeks, nylon sheave on a bushed pin, working load limit at least 500 kg | Chandlery or rigging supplier | 22.00 | buy | Indicative; about 1.1 kg each; near block and far block
9 Swivel rings | 2 | Eye-to-eye swivel, galvanised or stainless, 10 mm, working load limit at least 500 kg, eyes at least 25 mm inside | Rigging or fishing supplier | 7.00 | buy | Indicative; join the two loop halves and serve as clip rings and end stops
10 Jam cleats | 2 | V-jam cleat for 10 to 14 mm rope, cast aluminium or glass-filled nylon, two 8 mm fixing holes about 60 mm apart | Chandlery | 9.00 | buy | Indicative
11 Screw ground anchors | 2 | Helical ground anchor, single 250 mm helix, 20 mm galvanised rod 1.6 m long with a forged eye | Fencing or utility hardware supplier | 38.00 | buy | Indicative; 7.2 kg each; set in line with the stay (BKH-CAL-001 D)
12 Turnbuckles | 2 | Rated jaw-and-jaw turnbuckle M12, drop forged, galvanised, working load limit at least 500 kg, take-up 150 mm | Rigging supplier | 6.00 | buy | Indicative
13 Shackles | 6 | Bow shackle 10 mm, galvanised, rated, working load limit at least 750 kg, screw pin (mouse with wire) | Rigging supplier | 2.50 | buy | Indicative; two at the blocks | two at the stay lugs | two at the anchor eyes
14 Stop pin bolts | 2 | Stainless bolt M12 x 100 with nyloc nut and two washers; one fitted, one spare | Hardware store | 2.00 | buy | Indicative
15 Fixings | 1 | Four M8 x 50 stainless bolts with nyloc nuts and washers for the jam cleats; two 2 m lengths of 3 mm whipping twine; tape | Hardware store | 3.00 | buy | Indicative
16 Rope work kit | 1 | Splicing fid for 12 mm rope, sharp knife, whipping twine, lighter | Chandlery | 6.00 | buy | Indicative; used for the loop and stay splices
17 Stake driving cap | 1 | Steel tube 88.9 x 3.2 mm 300 mm long with a 10 mm cap plate and two 20 mm handles; fits over the stake top for a post driver or sledge | Local steel stockholder | 10.00 | make | Tool; not part of the station

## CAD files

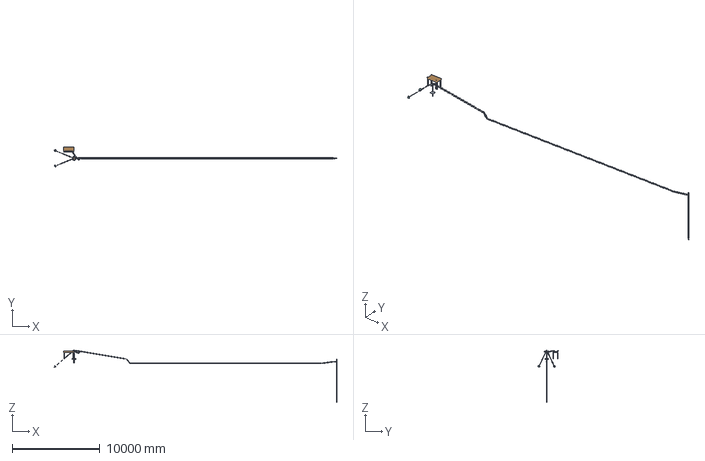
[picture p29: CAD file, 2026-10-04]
cad/step/bankhaul-assembly.step
32329.1 x 2294.4 x 6008.0 mm

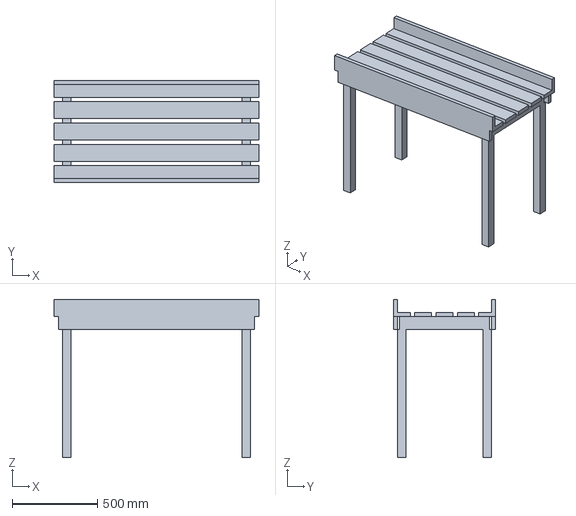
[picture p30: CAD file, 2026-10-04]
cad/step/bankhaul-table.step
1200.0 x 600.0 x 925.0 mm

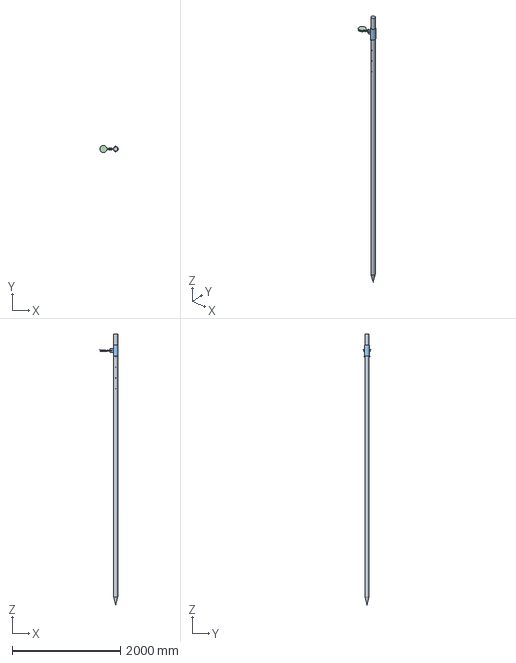
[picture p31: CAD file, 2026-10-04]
cad/step/bankhaul-far-end.step
336.5 x 129.9 x 5006.0 mm

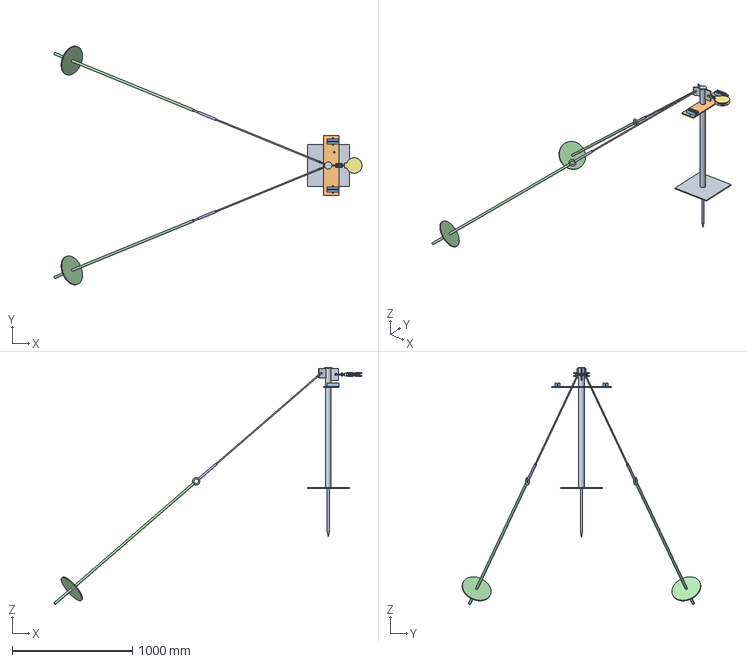
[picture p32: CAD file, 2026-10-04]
cad/step/bankhaul-bank-station.step
2565.7 x 1988.8 x 1974.4 mm

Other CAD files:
cad/stl/bankhaul-bank-station.stl
cad/stl/bankhaul-far-end.stl
cad/stl/bankhaul-table.stl

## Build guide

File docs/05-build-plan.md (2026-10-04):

---
doc_id: BKH-BLD-001
title: BankHaul prototype build plan
project: BankHaul
doc_type: Build plan
version: "0.2"
status: Draft
date: '2026-10-03'
author: Amish Chadha
license: CERN-OHL-S-2.0
revisions:
- version: "0.1"
  date: '2026-10-03'
  author: Amish Chadha
  change: First build plan; design made constructable (BKH-DDR-002)
- version: "0.2"
  date: '2026-10-03'
  author: Amish Chadha
  change: Far stake 5.0 m long, driven 3.5 m (BKH-DDR-003, Amish's decision 14A); cost updated
---

# BankHaul prototype build plan

**Plan, not yet built.** How to build the first proof-of-concept station, component by component. Building and testing to it is TRL 4 work. Decisions still to be made are kept in the design decisions register (`docs/06-design-decisions.md`), not here.

> **Safety:** BankHaul is a rope system worked beside crocodile water. Placing the far stake is the most dangerous job in this plan: it is done from a boat or at low water, with a second person watching the water, never by wading. Ropes under load can snap back; nobody stands in the bight of the loop or in line with a loaded stay. Section 6 lists the points where work stops.

## 1. What you are building

Every component, pulled apart and numbered in build order

*Figure 1. Every component of the prototype station, numbered in build order. The far end is drawn beside the bank station so all parts show.*

The prototype is one net-hauling station for a 30 m span: a steel post on the bank held back by two rope stays to two screw ground anchors, a block at the post's head, a steel stake driven into the bed with a turning collar and a second block, a loop of floating rope between the blocks, two net bridles with weak links, and a timber clearing table. Seven components are made (the post, stake, collar and table by welding, drilling and carpentry; the stays, loop and bridles by rope work) and seven are bought (blocks, swivel rings, jam cleats, screw anchors, turnbuckles, shackles and a stop pin). The station parts cost about USD 394 from the bill of materials.

## 2. What changed to make it buildable

| Component | The concept had | The buildable design has | Why |
| --- | --- | --- | --- |
| Bank post | A screw or deadman anchor carrying the pulley at waist height | A steel post on a foot plate and spike, held back by two splayed stays to two screw anchors | A post alone cannot hold 3 kN at waist height in soft soil; the stays take the pull as tension |
| Near pulley | A pulley on the anchor | A bought swivel block on a shackle through a pad eye at 950 mm | Commodity parts that line up with the loop by themselves |
| Cleat and brake | A cleat on the anchor | A cleat bar slipped over the post with a jam cleat for each leg and a tie-off hole | The round post has no flat face for a cleat |
| Screw anchors | Not defined | Two anchors with 250 mm helixes, screwed in line with the stays | The rods stay in tension; each holds about twice its load |
| Far stake | A steel or hardwood stake | A 76.1 mm steel tube with a welded point and cap, 5.0 m long, driven 3.5 m into the bed | A lighter stake bends at the design load; a shallower one can lean over in very soft mud |
| Far pulley and swivel | A pulley with a swivel | A collar that turns on the stake, resting on a stop pin that moves with the water level, with a bought block on a shackle | The collar is the swivel; the pin follows the season |
| Rope loop | An endless spliced loop | Two halves joined by two swivel rings, one end of each half spliced and the other hitched | The loop length can change with the shoreline; the rings are the clip points and end stops |
| Net clips | Quick clips | A bridle at each net end with a weak link and a snap hook | A seized net cannot pull more than about 700 N on the loop |
| Clearing table | A raised table or platform | A slatted timber table with lip boards, landward of the post | Keeps the net on the table, 5 m or more from the water |

## 3. Making the components

### 3.1 Bank post weldment

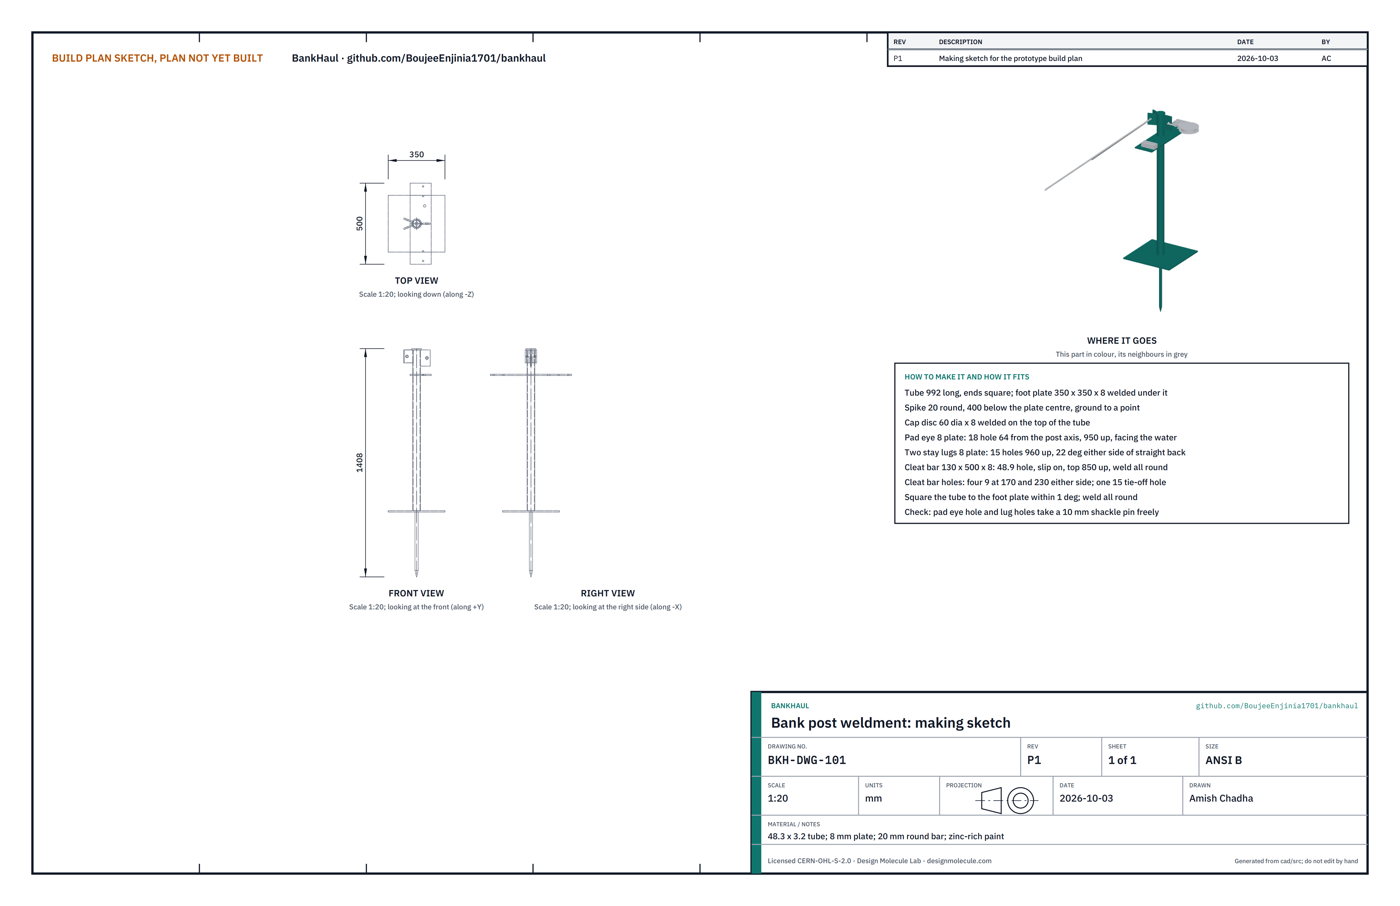
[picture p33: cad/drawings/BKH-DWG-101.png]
Making sketch: bank post weldment


**What it is and what it is made from.** The post that carries the near block, the jam cleats and the two stays. It is a 48.3 mm by 3.2 mm steel tube on a 350 mm square foot plate 8 mm thick, with a 20 mm round bar spike below, an 8 mm cap disc, an 8 mm pad eye, two 8 mm stay lugs and a 130 by 500 by 8 mm cleat bar. It weighs about 17 kg.

**How to make it.**

1. Cut the tube 992 mm long with square ends. Cut the foot plate 350 mm square and mark its centre.
2. Cut the spike 400 mm long and grind a point over the last 40 mm. Weld it square under the foot plate centre, all round.
3. Stand the tube on the plate centre, square within 1 degree in both directions, and weld all round. Weld the 60 mm cap disc on the top.
4. Cut the pad eye from 8 mm plate, 84 by 100 mm, and drill an 18 mm hole 64 mm from the post's centre line and 950 mm above the ground. Weld it to the tube on the side that will face the water, top edge flush with the top of the tube.
5. Cut two stay lugs, 84 by 80 mm, with 15 mm holes 960 mm above the ground. Weld them to the back of the tube, each turned 22 degrees off straight back, one to each side.
6. Cut the cleat bar 130 by 500 mm and cut a 48.9 mm hole 40 mm from its back edge. Drill four 9 mm holes for the cleats (170 mm and 230 mm either side of the post's centre line, 40 mm in front of it) and one 15 mm tie-off hole. Slide it down the tube until its top is 850 mm above the ground, square to the pad eye, and weld all round.
7. Clean and paint with zinc-rich paint.

**How it fits the parts next to it.**

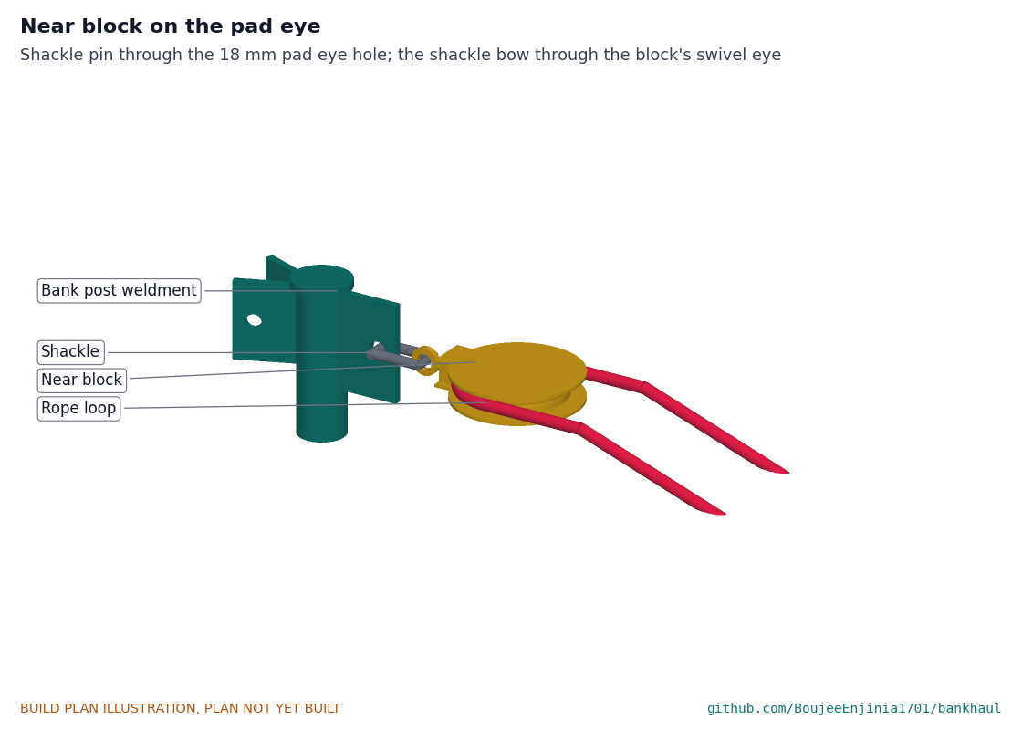
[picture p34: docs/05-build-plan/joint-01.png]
Close-up: near block on the pad eye


*Figure 2. The near block hangs from the pad eye on a 10 mm shackle. The shackle pin passes through the 18 mm hole; the bow passes through the block's swivel eye. The block lies flat when the loop pulls on it.*

Close-up: back-stays on the post lugs

*Figure 3. Each stay's thimble eye is held on a 10 mm shackle through a 15 mm lug hole. The lugs point along the stays, so the shackles pull straight.*

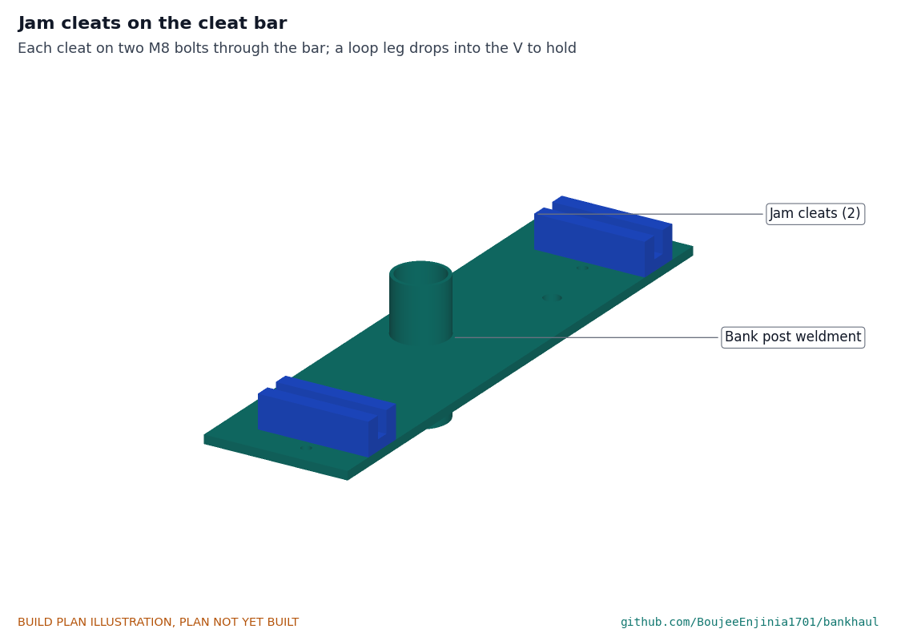
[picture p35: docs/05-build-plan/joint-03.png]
Close-up: jam cleats on the cleat bar


*Figure 4. Each jam cleat sits on the cleat bar on two M8 bolts, its V pointing toward the water, beside one leg of the loop.*

Close-up: foot plate and ground spike, cut open

*Figure 5. The spike is welded under the plate centre and the tube on top. The plate bears on the soil; the spike stops it sliding.*

**Check before moving on.** A 10 mm shackle pin passes freely through the pad eye and both lug holes; the tube stands square on the plate; the cleat bar is level.

### 3.2 Far stake

Making sketch: far stake

**What it is and what it is made from.** The post in the bed that carries the far block. It is a 76.1 mm by 3.6 mm S355 steel tube, 5.0 m long overall with its point, with five cross holes for the stop pin. It weighs about 33 kg, so two people carry and lift it.

**How to make it.**

1. Cut the tube 4,850 mm long with square ends.
2. Cut four triangles from 4 mm plate and weld them into a cone point 150 mm long on one end. Weld a 6 mm cap disc on the other end; this disc takes every blow when driving.
3. Mark a paint ring 3,500 mm above the point: the stake is driven until this ring reaches the bed.
4. Drill five 12.5 mm holes straight through both walls on one line, 200 mm apart, the top one 712 mm below the cap.
5. Paint with zinc-rich paint after drilling.

**How it fits the parts next to it.** The collar slides over the top and rests on the stop pin (section 3.3, Figure 7).

**Check before moving on.** The stake is straight within 10 mm over its length, and a 12 mm bolt slides through every hole.

### 3.3 Swivel collar

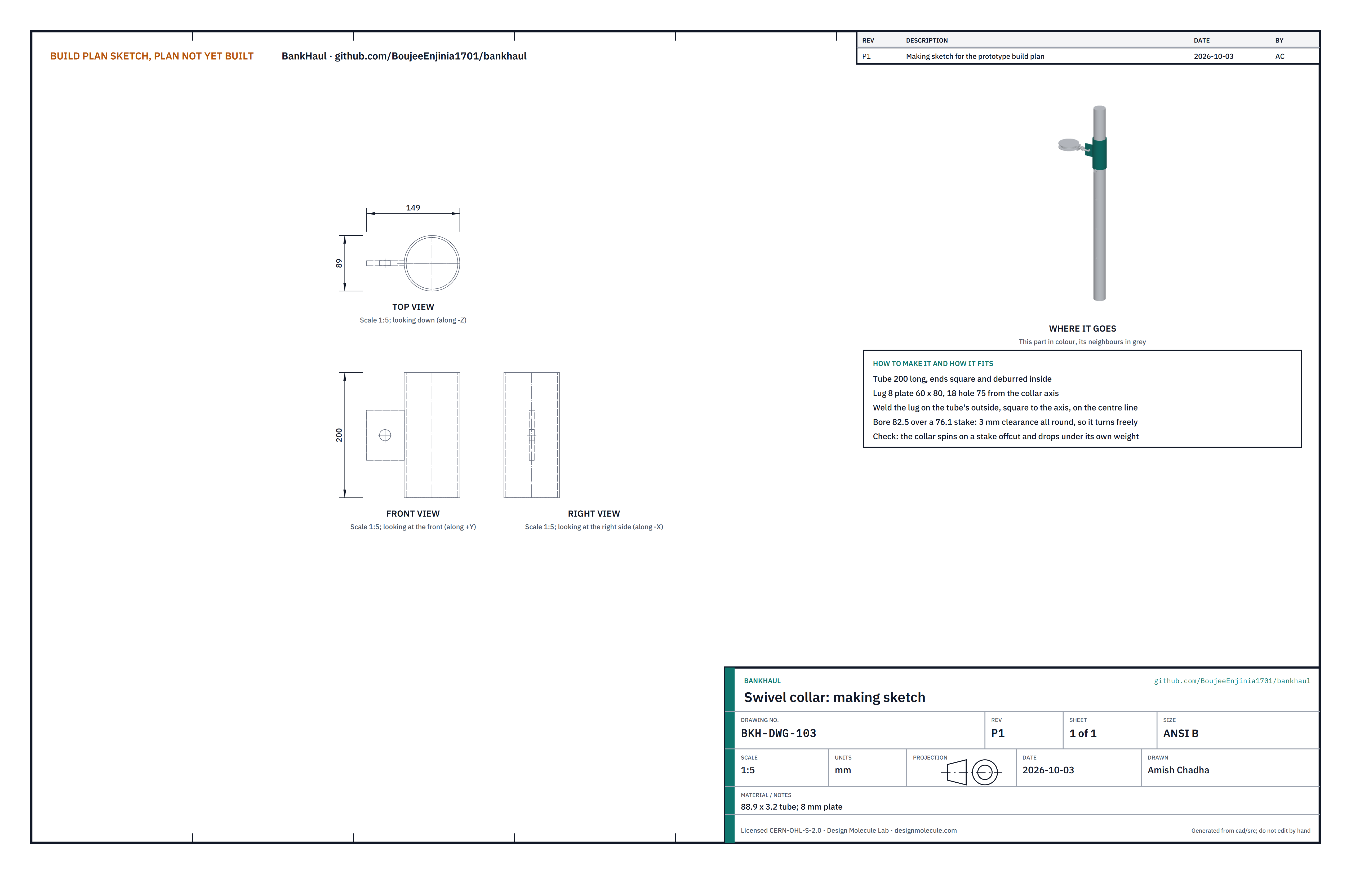
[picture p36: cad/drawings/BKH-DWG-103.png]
Making sketch: swivel collar


**What it is and what it is made from.** A short tube that turns on the stake and carries the far block. It is an 88.9 mm by 3.2 mm steel tube, 200 mm long, with an 8 mm lug.

**How to make it.**

1. Cut the tube 200 mm long with square ends and remove the burr inside.
2. Cut the lug from 8 mm plate, 60 by 80 mm, with an 18 mm hole 75 mm from the collar's centre line.
3. Weld the lug to the outside of the tube, square to the tube's axis and centred on its length. Paint.

**How it fits the parts next to it.**

Close-up: swivel collar on the stake, cut open

*Figure 6. The collar turns on the stake with about 3 mm clearance all round and rests on the M12 stop pin through the stake.*

Close-up: far block on the collar lug

*Figure 7. The far block hangs from the collar lug on a 10 mm shackle; the loop runs round its sheave and back toward the bank.*

**Check before moving on.** The collar spins on an offcut of the stake tube and drops down it under its own weight.

### 3.4 Clearing table

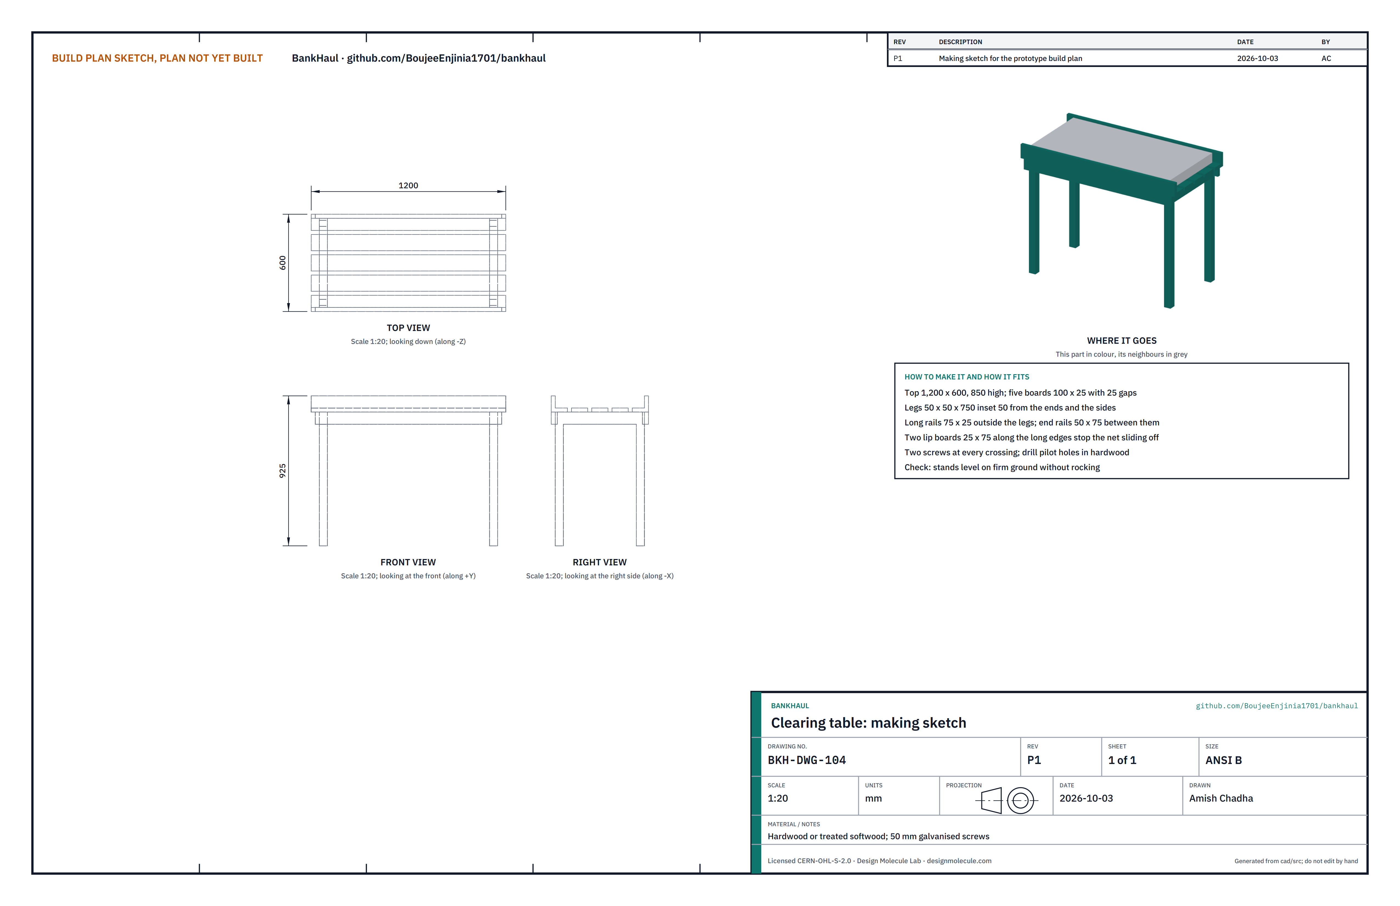
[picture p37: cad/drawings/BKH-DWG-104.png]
Making sketch: clearing table


**What it is and what it is made from.** A raised table on the bank where the net is stacked and cleared. Hardwood or treated softwood, held with 50 mm galvanised screws; the top is 1,200 by 600 mm and 850 mm high.

**How to make it.**

1. Cut four legs 50 by 50 by 750 mm, two long rails 75 by 25 by 1,150 mm, two end rails 50 by 75 by 475 mm, five top boards 100 by 25 by 1,200 mm and two lip boards 25 by 75 by 1,200 mm.
2. Screw the long rails to the outside of the legs, 50 mm in from each end, and the end rails between them.
3. Screw the top boards across the rails with 25 mm gaps so water drains.
4. Screw the lip boards on edge along both long sides.

**How it fits the parts next to it.** It stands free on the bank, landward of the post and on the side away from the stays.

**Check before moving on.** It stands level on firm ground without rocking.

### 3.5 Back-stays

Making sketch: back-stay

**What it is and what it is made from.** Two short ropes that hold the post back. Each is 10 mm three-strand polyester with a thimbled eye splice at each end.

**How to make it.**

1. Cut two lengths of 1,800 mm; tape and melt the ends.
2. Splice an eye round a thimble at each end with five full tucks, so the eye centres are 1,440 mm apart.

**How it fits the parts next to it.** One eye is shackled to a post lug (Figure 3); the other is shackled to the turnbuckle on the anchor eye.

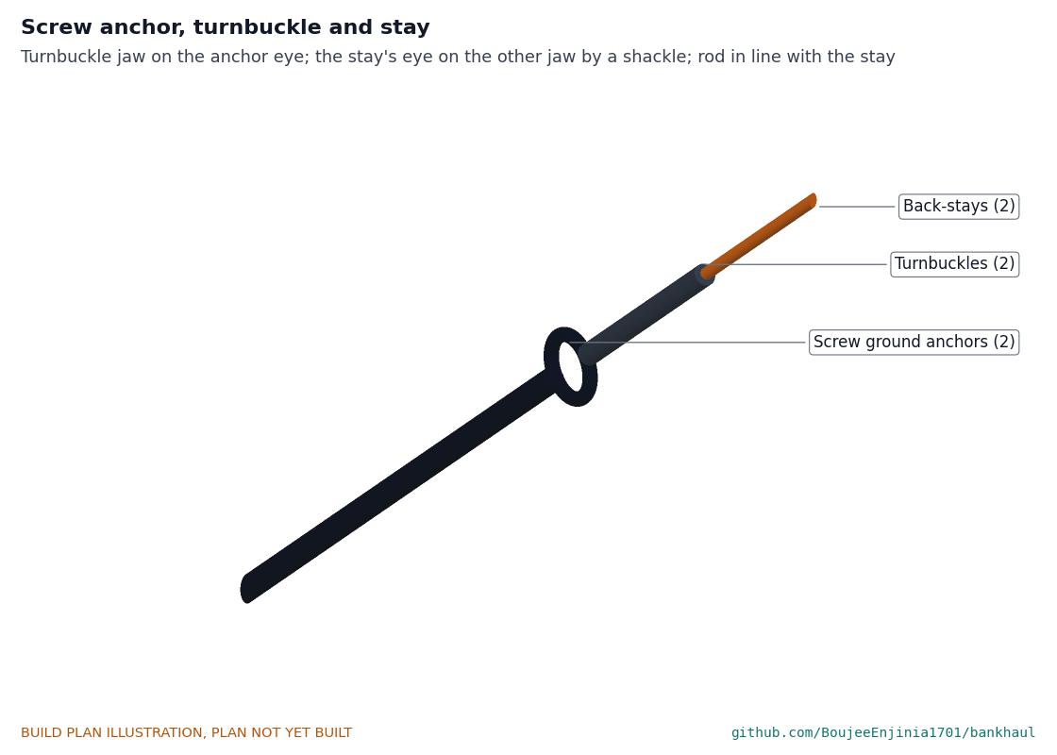
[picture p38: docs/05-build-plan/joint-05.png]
Close-up: screw anchor, turnbuckle and stay


*Figure 8. The turnbuckle's jaw takes the anchor's eye; the stay's eye is shackled to the other jaw. The anchor's rod runs in line with the stay.*

**Check before moving on.** Both stays are the same length within 20 mm.

### 3.6 Rope loop

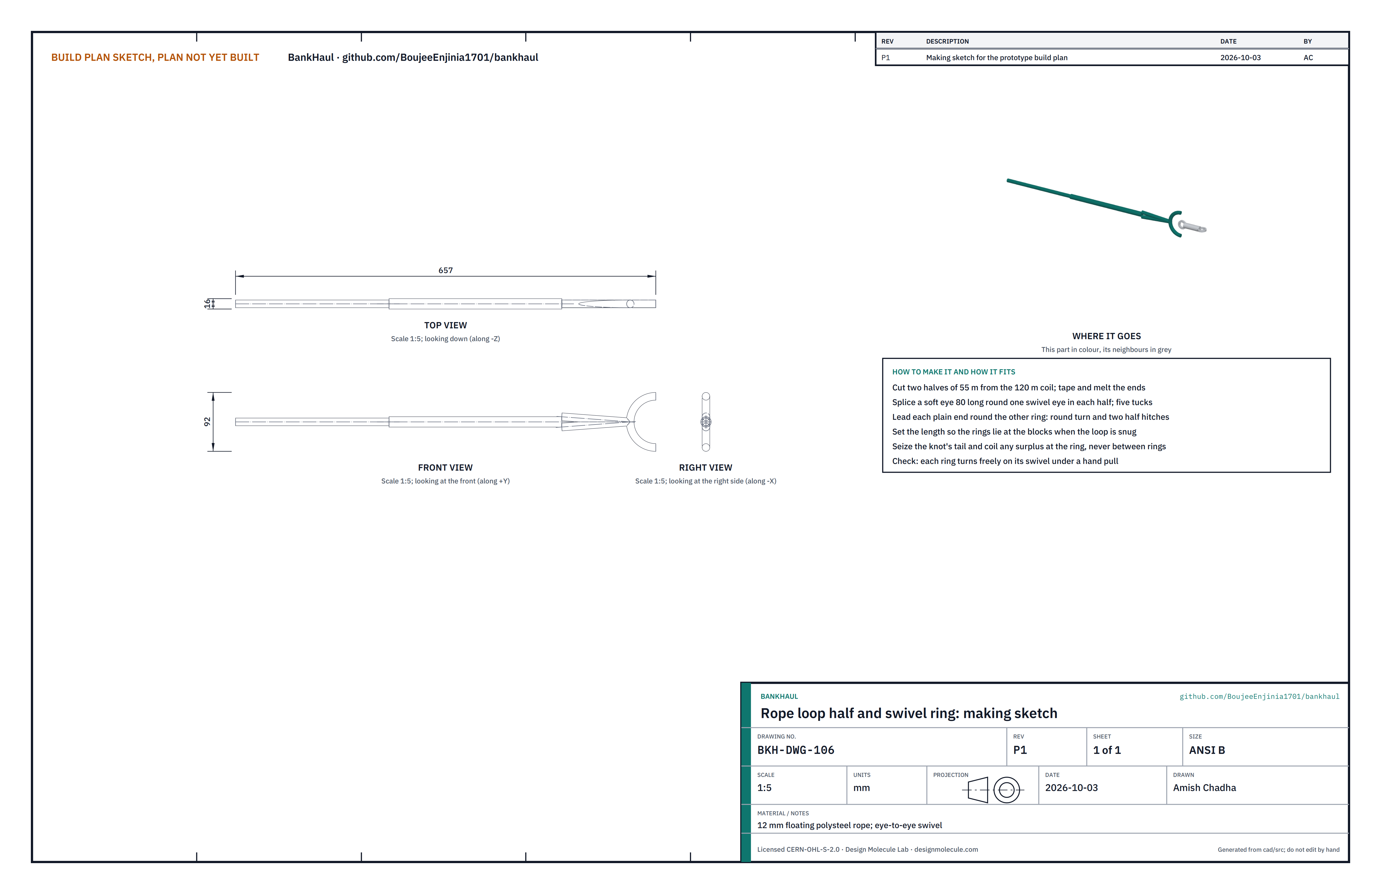
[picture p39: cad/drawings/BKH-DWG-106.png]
Making sketch: rope loop half and swivel ring


**What it is and what it is made from.** The loop that carries the net out and back: two halves of 12 mm floating polysteel rope joined by two eye-to-eye swivels, the swivel rings.

**How to make it.**

1. Cut two halves of 55 m from the 120 m coil; tape and melt all ends.
2. Splice a soft eye, about 80 mm long, round one eye of a swivel ring at one end of each half, with five tucks.
3. The plain end of each half is tied to the other ring with a round turn and two half hitches when the loop is reeved (step 9), so its length suits the span.

**How it fits the parts next to it.**

Close-up: swivel ring, loop eyes and net bridle

*Figure 9. The two loop halves meet at each swivel ring, one spliced and one hitched. The net bridle's snap hook clips onto ring 1.*

**Check before moving on.** Each ring turns freely under a firm hand pull; each splice has five full tucks.

### 3.7 Net bridles with weak links

Making sketch: net bridle with weak link

**What it is and what it is made from.** One bridle for each end of the net: 1.5 m of 6 mm polyester cord, a weak link of braided cord and a 60 mm stainless snap hook.

**How to make it.**

1. Pull three samples of the weak link cord to breaking on a spring scale or the CalRig rig; use the cord only if every sample breaks between 500 and 700 N, as a single loop 80 mm long.
2. Tie the bridle cord to the head rope and foot rope at the net's end with bowlines.
3. Join the bridle to the snap hook with one loop of the weak link cord. Mark the link with paint so it is never replaced with stronger cord.

**How it fits the parts next to it.** The far-end bridle clips onto ring 1 (Figure 9); the near-end bridle clips into the tie-off hole of the cleat bar.

**Check before moving on.** The hook opens with one hand and snaps shut by itself.

### 3.8 Bought components

- **Swivel blocks (2).** Single sheave, 100 mm sheave for 12 mm rope, swivel eye, working load limit at least 500 kg. The eye and the spacer between the cheeks must sit outside the rope's path round the sheave. Nothing to do to them.
- **Swivel rings (2).** Eye-to-eye swivels, 10 mm, working load limit at least 500 kg, with eyes at least 25 mm inside.
- **Jam cleats (2).** V-jam cleats for 10 to 14 mm rope with two 8 mm fixing holes about 60 mm apart. If the hole spacing differs, drill the cleat bar to suit.
- **Screw ground anchors (2).** A single 250 mm helix on a 20 mm galvanised rod, 1.6 m long, with an eye.
- **Turnbuckles (2).** Rated M12 jaw-and-jaw, working load limit at least 500 kg.
- **Shackles (6).** Rated 10 mm bow shackles, working load limit at least 750 kg; wire every pin shut (mousing).
- **Stop pin.** An M12 by 100 mm stainless bolt with a nyloc nut and two washers, plus a spare.
- **Stake driving cap (tool).** A 300 mm length of 88.9 mm tube with a 10 mm cap plate and two handles, made to fit over the stake top.

## 4. Putting it together

Steps 1 to 5 and 10 are done on the bank; steps 6 to 9 need a boat or a low-water day and two people.

### Step 1: Screw in the two ground anchors

Step 1

Mark the post spot at least 6 m back from the water's edge. Mark the two anchor spots 1,100 mm behind it and 450 mm either side of the line to the far stake. Screw each anchor in with a bar through its eye, leaning back toward the post at about 39 degrees from the ground, until the eye is just above the ground.

### Step 2: Stand the post on its spike

Step 2

Push the spike in until the foot plate sits flat, pad eye toward the water.

### Step 3: Fit the back-stays

Step 3

Shackle each stay to a post lug and to a turnbuckle on an anchor eye. Take up both turnbuckles evenly until the post leans about 1 degree away from the water. Wire the shackle pins.

### Step 4: Bolt on the jam cleats

Step 4

Two M8 bolts each, with the V pointing toward the water.

### Step 5: Hang the near block

Step 5

Shackle through the pad eye and the block's swivel eye; wire the pin.

### Step 6: Drive the far stake from a boat

Step 6

From a boat held on two anchors, or standing on the dry bed at low water, stand the stake on its point 30 m from the post on the line between the anchors. The stake is 5.0 m long, so two people lift it upright together. In soft mud it sinks part of the way under its own weight; push and twist it down as far as it will go. Then fit the driving cap and drive with a post driver or sledge until the paint ring, 3.5 m above the point, reaches the bed. Keep it upright within 2 degrees.

### Step 7: Fit the stop pin and the collar

Step 7

Choose the hole that puts the far block about 200 mm above the day's water. Fit the bolt and nyloc nut through it, then slide the collar down the stake onto the pin.

### Step 8: Hang the far block

Step 8

Shackle through the collar lug and the block's swivel eye; wire the pin.

### Step 9: Reeve the loop and join the halves

Step 9

From the boat, run the first half from the bank round the far block and back to the bank; run the second half round the near block. Tie each plain end to the other half's ring with a round turn and two half hitches, so that ring 1 lies about 450 mm in front of the near block when ring 2 lies about 450 mm short of the far block and the loop is snug but not tight. Coil and seize any surplus at the ring.

### Step 10: Set up the clearing table

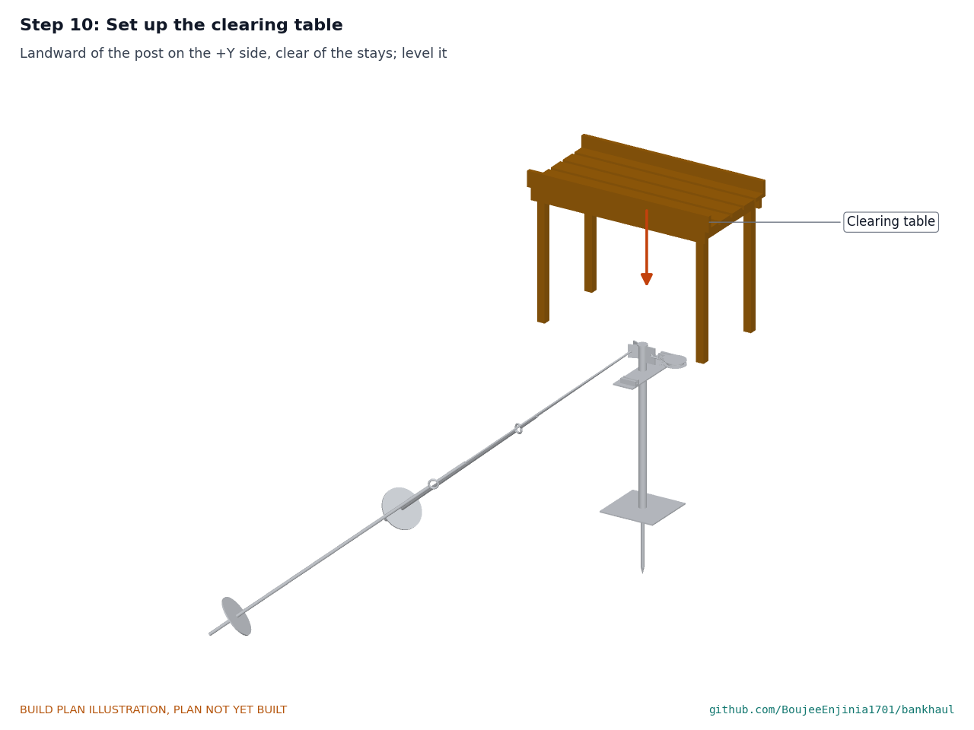
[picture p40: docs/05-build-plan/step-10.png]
Step 10


Landward of the post on the side away from the stays, level on firm ground.

### Step 11: Clip the net to ring 1

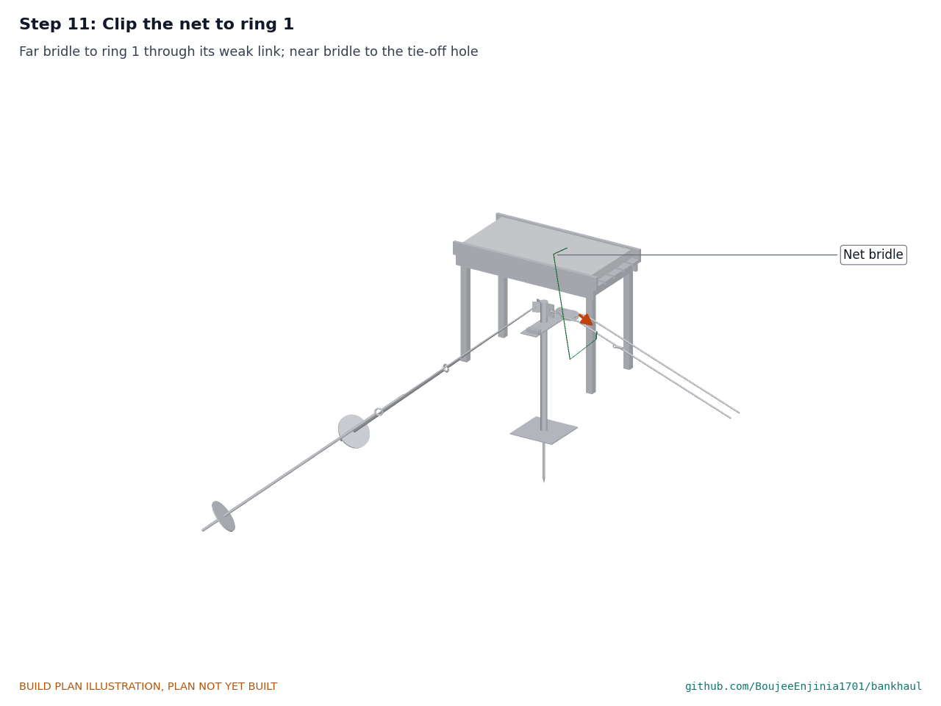
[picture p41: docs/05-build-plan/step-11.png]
Step 11


Stack the net on the table, far end on top. Clip the far-end bridle to ring 1 and the near-end bridle to the tie-off hole. The station is now ready for the first checks.

## 5. First checks

| Check | Requirement | How | Pass when |
| --- | --- | --- | --- |
| Post and stays | R4 | Pull the near block toward the water with a spring scale or come-along to 3 kN, from behind a screen | No visible movement of post, anchors or stays; no change at the anchor eyes |
| Far stake | R5 | Pull the collar toward the bank to 1.5 kN from the boat | The stake moves less than 25 mm at the collar and springs back |
| Weak link | R10 | Pull three links from the batch | Each releases between 500 and 700 N |
| Loop runs | R2 | Pull each leg by hand over a full cycle | The loop runs freely; no ring reaches a block; nothing rubs a cheek |
| Set and haul | R1, R3 | Set and haul a 30 m net from the bank with a spring scale on the hauling end | Nobody enters the water; peak pull under 250 N |
| Timing | R6 | Time a haul and reset | Under 10 minutes without clearing fish |
| Working spot | R11 | Measure from where the fisher stands to the water's edge | 5 m or more |

## 6. Safety stops

- **Before driving the far stake:** two people, a boat held on two anchors or a dry bed, a lookout on the water, and the local wildlife authority's advice on the site. Never wade. The 5.0 m stake is lifted upright by two people and never driven from a standing position higher than the boat's seat.
- **Before the first load on the bank station:** stays tensioned, all shackle pins wired, anchors in line with the stays, and nobody in line with a stay or in the bight of the loop.
- **Before the first pull test:** the person pulling stands behind a screen or to the side of the line; the load is applied slowly and held, never jerked.
- **Before the first net is set:** both weak links tested from the same batch and marked; the jam cleats hold a leg against a firm pull.
- **Before each use:** the loop, splices, stays, shackles and blocks are looked over; any cut, melted or worn rope is replaced.
- **When floods are expected:** the loop is taken out of the water and the net is not set.

## 7. Tools, skills and workspace

- **Welding and drilling:** MIG or stick welder for 3 to 8 mm steel, angle grinder, pillar drill or magnetic drill to 49 mm, a flat table to square the post. A competent welder.
- **Woodwork:** saw, drill and screwdriver.
- **Rope work:** splicing fid, sharp knife, tape and lighter; someone who can make an eye splice in three-strand rope.
- **Site:** two people, a tommy bar for the screw anchors, a post driver or 5 kg sledge with the driving cap, a tape measure, a boat that two people can work from, life jackets.
- **Testing:** a spring scale or load cell to 5 kN and a come-along, or the CalRig proof-load rig.

## 8. Where the numbers come from

- Model and constructability checks: `cad/src/model.py`
- General arrangements: `cad/drawings/BKH-DWG-001` (bank station), `BKH-DWG-002` (far end) and `BKH-DWG-003` (layout)
- Making sketches: `cad/drawings/BKH-DWG-101` to `BKH-DWG-107`; pictures: `cad/src/build_plan_media.py`
- Calculations: `docs/04-calcs/01-sizing.md` and `docs/04-calcs/sizing.py` (BKH-CAL-001)
- Parts: `bom/bom.csv`
- Design changes: `docs/decisions/0002-design-for-construction.md` (BKH-DDR-002) and `docs/decisions/0003-amish-requirement-decisions.md` (BKH-DDR-003)

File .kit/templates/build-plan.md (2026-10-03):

---
doc_id: PRJ-BLD-001
title: Project prototype build plan
project: Project name
doc_type: Build plan
version: "0.1"
status: Draft
date: YYYY-MM-DD
author: Amish Chadha
license: CERN-OHL-S-2.0
revisions:
  - version: "0.1"
    date: YYYY-MM-DD
    author: Amish Chadha
    change: First build plan; design made constructable
---

# Project prototype build plan

**Plan, not yet built.** How to build the first proof-of-concept prototype, component by component. Building and testing to it is TRL 4 work. Decisions still to be made are kept in the design decisions register (`docs/06-design-decisions.md`), not here.

## 1. What you are building

Every component, pulled apart and numbered in build order

One short paragraph: what the prototype is, how many components, which are made and which are bought, and the main ways they are made.

## 2. What changed to make it buildable

| Component | The concept had | The buildable design has | Why |
| --- | --- | --- | --- |

## 3. Making the components

### 3.1 Component name

Making sketch

**What it is and what it is made from.**

**How to make it.**

1. Mark out ...
2. Cut ...

**How it fits the parts next to it.**

Close-up of the joint

**Check before moving on.**

## 4. Putting it together

### Step 1: ...

Step 1

## 5. First checks

| Check | Requirement | How | Pass when |
| --- | --- | --- | --- |

## 6. Safety stops

## 7. Tools, skills and workspace

## 8. Where the numbers come from

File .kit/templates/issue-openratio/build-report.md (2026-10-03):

---
name: Build report
about: Tell us what happened when you built, printed or tested part of this design
title: "Build report: "
labels: build-report
---

This is a research and educational prototype, not a medical device. It is a TRL 3 concept and is not released for fabrication. If you build any part of it, you do so at your own risk. Reports help everyone.

**What you built** (part, sub-assembly or test)

**Materials, tools and settings**

**What worked**

**What did not work, with photos or measurements if you have them**

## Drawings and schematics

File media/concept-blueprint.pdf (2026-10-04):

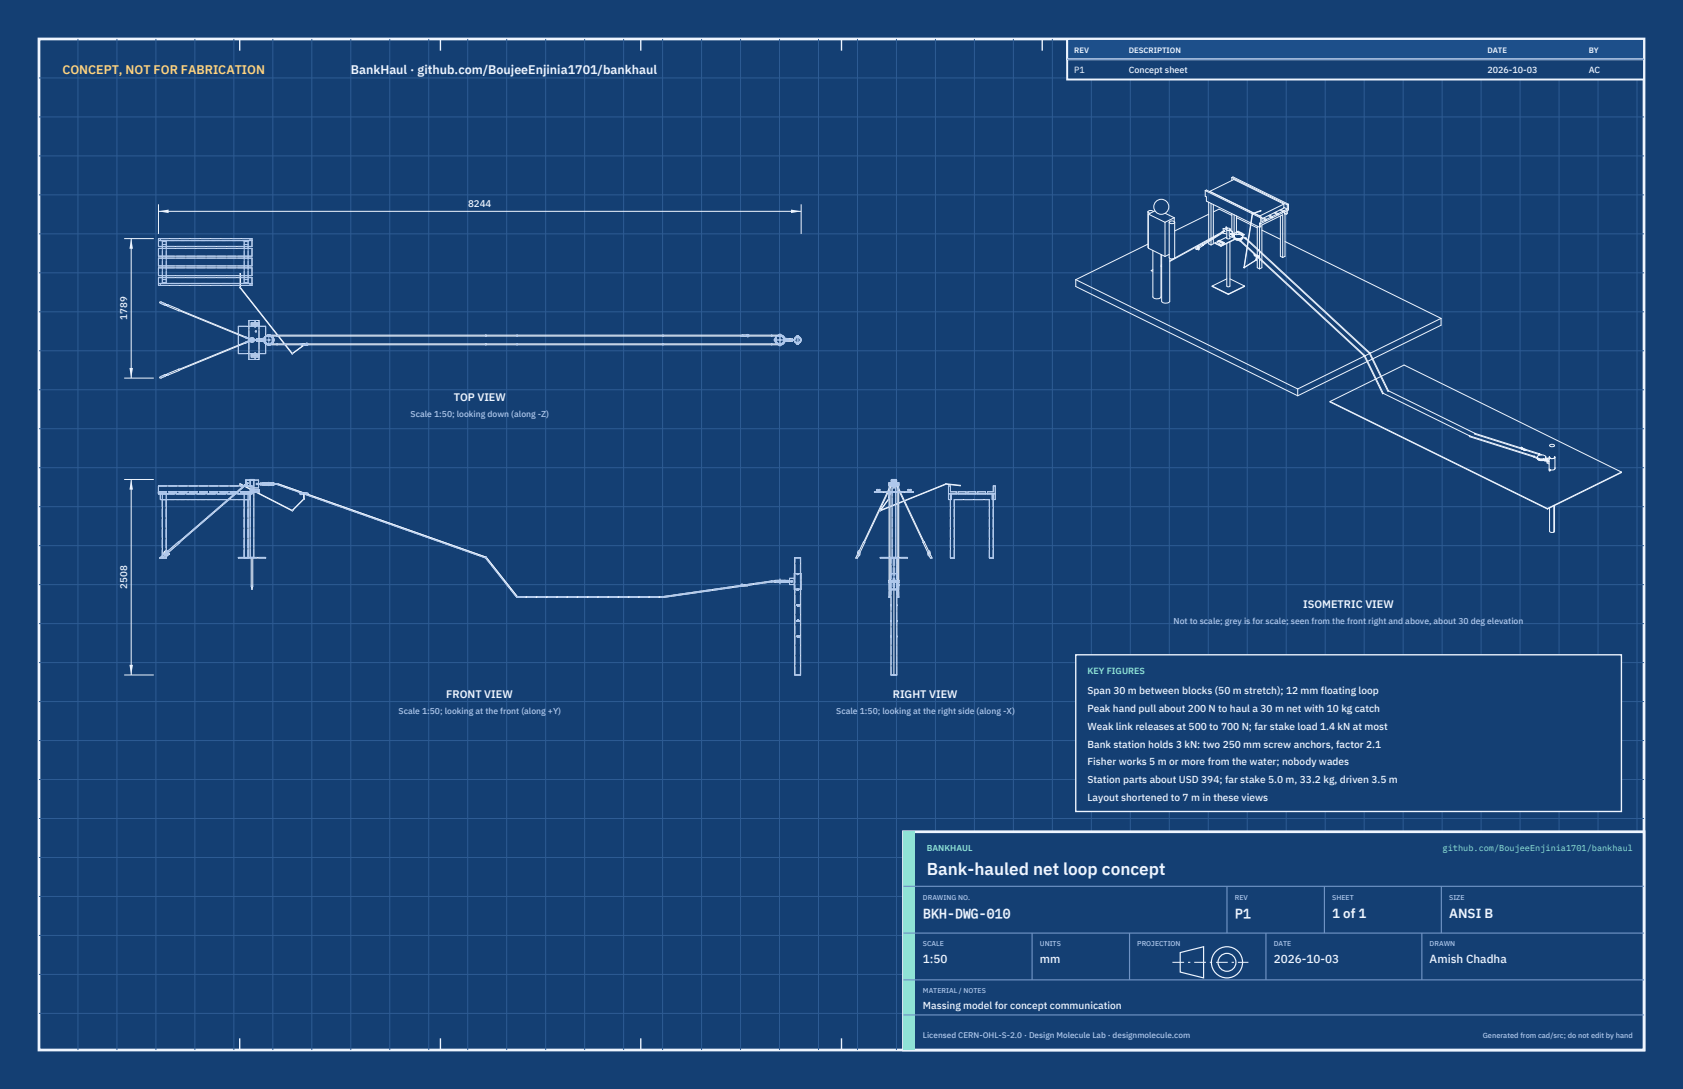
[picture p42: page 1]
CONCEPT, NOT FOR FABRICATION; BankHaul · github.com/BoujeeEnjinia1701/bankhaul; FRONT VIEW; TOP VIEW; RIGHT VIEW; ISOMETRIC VIEW; REV; DESCRIPTION; DATE; Concept sheet; BANKHAUL; github.com/BoujeeEnjinia1701/bankhaul; DRAWING NO. BKH-DWG-010; REV P1; SHEET 1 of 1; SIZE ANSI B; SCALE 1:50; UNITS mm; PROJECTION; DRAWN Amish Chadha; Licensed CERN-OHL-S-2.0 · Design Molecule Lab · designmolecule.com; Generated from cad/src; do not edit by hand

Scale 1:50; looking down (along -Z)

Not to scale; grey is for scale; seen from the front right and above, about 30 deg elevation

KEY FIGURES
Span 30 m between blocks (50 m stretch); 12 mm floating loop
Peak hand pull about 200 N to haul a 30 m net with 10 kg catch
Weak link releases at 500 to 700 N; far stake load 1.4 kN at most
Bank station holds 3 kN: two 250 mm screw anchors, factor 2.1
Fisher works 5 m or more from the water; nobody wades
Station parts about USD 394; far stake 5.0 m, 33.2 kg, driven 3.5 m
Layout shortened to 7 m in these views

Scale 1:50; looking at the front (along +Y)

Scale 1:50; looking at the right side (along -X)

Bank-hauled net loop concept

MATERIAL / NOTES
Massing model for concept communication

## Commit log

2026-10-03 BankHaul at TRL 3: constructable design (kit 1.7.0)
    Problem, concept and requirements; sizing calculations; CAD model, STEP and STL; general arrangement drawing; bill of materials; build plan with making sketches, joint close-ups and step pictures; design decisions register (design choices decided under Amish's 2026-10-03 pre-approval; requirement decisions open for Amish); TRL 2 and TRL 3 review; photoreal renders and storefront card. Private until Amish opens it.
    [bankhaul-assembly.step, bankhaul-bank-station.step, bankhaul-bank-station.stl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]
2026-10-04 Carry Amish's round 2 requirement decisions into the design
    Amish approved all 47 recommendations on 2026-10-03 ("i approve all of the 47 recommendations provided by you. Execute them."). Each repo gains a decision record (DDR-003, or the next free number for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
    [bom.csv, results.csv]
2026-10-04 Carry Amish's round-2 and round-3 decisions into the design
    Amish approved all 46 round-2 recommendations ("i agree with all the 46 recommendations you provided. please proceed.") and all round-3 recommendations ("For round 3, I agree with all your proposed r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
    [bankhaul-assembly.step, bankhaul-bank-station.step, bankhaul-far-end.step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]
2026-10-28 Kit 1.9.1 upgrade: pipeline documents and detailed CAD for every option
    Kit 1.9.1 installed (.kit, CLAUDE.md, .claude/commands). Kit 1.8 pipeline: STEM check with fixes under the 2026-10-23 standing instruction, concept options with the current design as option A, URS, PRS, generated RTM, REG, FEA, RSK with design FMEA, MKT, PLN and DDR; kit 1.9 D3 model of every option passing cad/fidelity.json; independent review recorded in the STEM check. Amish's 2026-10-25 decisions recorded where he approved a recommendation; all others proposed, awaiting Amish. Product renders and the options picture follow in a later commit where not yet included.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
2026-10-29 Add Cycles product renders and the concept options picture
    Blender Cycles renders of the kit 1.9.1 model, rendered on Amish's Mac and captioned; media/options.png from the D3 option models (this also clears the failing docs check, which needs the picture); cards and PDFs rebuilt. The options picture labels option A as the current design unless project.yaml records Amish's choice.

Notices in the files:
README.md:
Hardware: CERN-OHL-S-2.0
